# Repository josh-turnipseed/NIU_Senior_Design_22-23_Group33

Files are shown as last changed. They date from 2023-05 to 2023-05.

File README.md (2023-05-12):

# NIU Senior Design 2022-2023 Group 33
Analog and Digital Controlled Modular Synthesizer for Audio Synthesis and Signal Processing

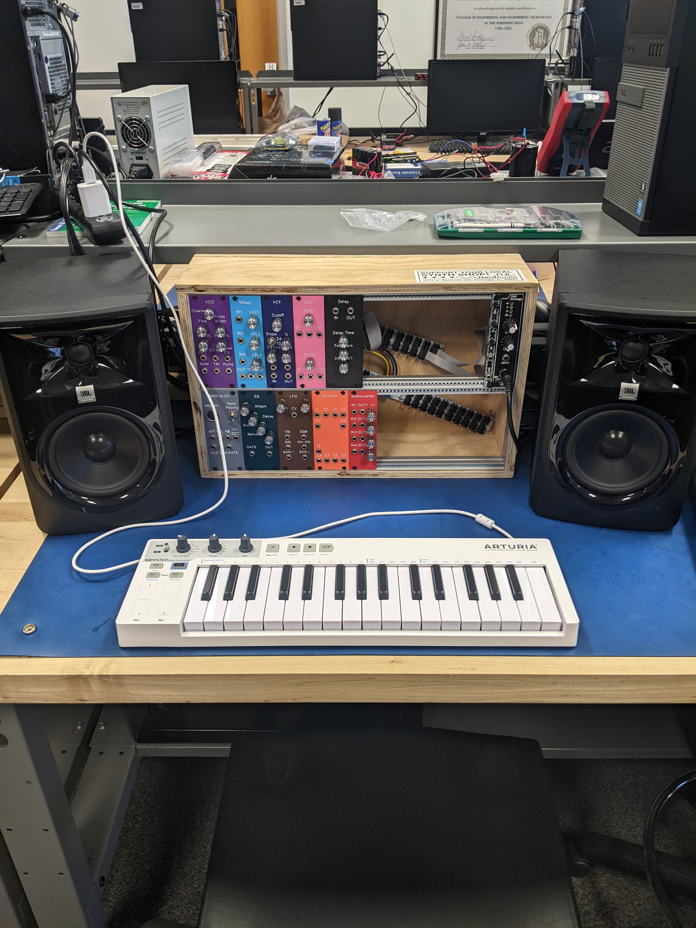
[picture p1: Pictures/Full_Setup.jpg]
Comleted Synthesizer


The goal of this project was to design and construct a modular Eurorack synthesizer.
The team has designed ten modules that perform the functions of a synthesizer. Those modules are:
- Musical Instrument Digital Interface (MIDI) to Control Voltage (CV)
- Voltage Controlled Oscillator (VCO)
- Voltage Controlled Amplifier (VCA)
- Voltage Controlled Filter (VCF)
- Envelope Generator (EG) ADSR Type
- Low Frequency Oscillator (LFO)
- Mixer
- Multiple
- Attenuverter
- Delay

# Schematics and PCBs
The schematic and board files for all ten modules can be found in the KiCad Schematics folder. In which, are folders for each of the modules. In addition to the KiCad project, schematic, and board files, there is a zip in each module folder which contains all the gerber files required to manufacture the PCBs. This group used JLCPCB, but any manufacture will do.

These files were made using KiCad version 7.0.1, release build

# Front Panels
This group chose to manufacture front panels using FDM 3D printing technologies. Step files can be found in the Steps folder for each of the modules. These files can be loaded into the slicer of your choice. Specifically, this group used Prusaslicer 2.6.0-alpha6 for the embossed text feature. Gcode can be found in the Gcode folder for each of the module front panels with text. The Gcode is for a Prusa i3 MK3S.

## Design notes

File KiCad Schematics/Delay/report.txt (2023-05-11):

Info: Processing symbol 'C2:Capacitor_THT:CP_Radial_D5.0mm_P2.00mm'.
Info: Processing symbol 'C3:Capacitor_THT:C_Disc_D3.8mm_W2.6mm_P2.50mm'.
Info: Processing symbol 'C4:Capacitor_THT:C_Disc_D3.8mm_W2.6mm_P2.50mm'.
Info: Processing symbol 'C5:Capacitor_THT:C_Disc_D3.8mm_W2.6mm_P2.50mm'.
Info: Processing symbol 'C6:Capacitor_THT:C_Disc_D3.8mm_W2.6mm_P2.50mm'.
Info: Processing symbol 'C7:Capacitor_THT:CP_Radial_D5.0mm_P2.00mm'.
Info: Processing symbol 'C8:Capacitor_THT:C_Disc_D3.8mm_W2.6mm_P2.50mm'.
Info: Processing symbol 'C9:Capacitor_THT:C_Disc_D3.8mm_W2.6mm_P2.50mm'.
Info: Processing symbol 'C10:Capacitor_THT:C_Disc_D3.8mm_W2.6mm_P2.50mm'.
Info: Processing symbol 'C11:Capacitor_THT:C_Disc_D3.8mm_W2.6mm_P2.50mm'.
Info: Processing symbol 'C12:Capacitor_THT:C_Disc_D3.8mm_W2.6mm_P2.50mm'.
Info: Processing symbol 'C13:Capacitor_THT:C_Disc_D3.8mm_W2.6mm_P2.50mm'.
Info: Processing symbol 'C14:Capacitor_THT:C_Disc_D3.8mm_W2.6mm_P2.50mm'.
Info: Processing symbol 'C15:Capacitor_THT:CP_Radial_D5.0mm_P2.00mm'.
Info: Processing symbol 'C16:Capacitor_THT:CP_Radial_D5.0mm_P2.00mm'.
Info: Processing symbol 'C17:Capacitor_THT:C_Disc_D3.8mm_W2.6mm_P2.50mm'.
Info: Processing symbol 'C18:Capacitor_THT:CP_Radial_D5.0mm_P2.00mm'.
Info: Processing symbol 'C19:Capacitor_THT:C_Disc_D3.8mm_W2.6mm_P2.50mm'.
Info: Processing symbol 'C20:Capacitor_THT:C_Disc_D3.8mm_W2.6mm_P2.50mm'.
Info: Processing symbol 'D2:Diode_THT:D_DO-41_SOD81_P10.16mm_Horizontal'.
Info: Processing symbol 'D3:Diode_THT:D_DO-41_SOD81_P10.16mm_Horizontal'.
Info: Processing symbol 'D4:Diode_THT:D_DO-41_SOD81_P10.16mm_Horizontal'.
Info: Processing symbol 'J1:Connector_Audio:Jack_3.5mm_QingPu_WQP-PJ398SM_Vertical_CircularHoles'.
Info: Processing symbol 'J2:Custom_Footprints:Eurorack_16_pin_header'.
Info: Processing symbol 'J3:Connector_Audio:Jack_3.5mm_QingPu_WQP-PJ398SM_Vertical_CircularHoles'.
Info: Processing symbol 'R1:Resistor_THT:R_Axial_DIN0207_L6.3mm_D2.5mm_P7.62mm_Horizontal'.
Info: Processing symbol 'R2:Resistor_THT:R_Axial_DIN0207_L6.3mm_D2.5mm_P7.62mm_Horizontal'.
Info: Processing symbol 'R3:Resistor_THT:R_Axial_DIN0207_L6.3mm_D2.5mm_P7.62mm_Horizontal'.
Info: Processing symbol 'R4:Resistor_THT:R_Axial_DIN0207_L6.3mm_D2.5mm_P7.62mm_Horizontal'.
Info: Processing symbol 'R5:Resistor_THT:R_Axial_DIN0207_L6.3mm_D2.5mm_P7.62mm_Horizontal'.
Info: Processing symbol 'R6:Resistor_THT:R_Axial_DIN0207_L6.3mm_D2.5mm_P7.62mm_Horizontal'.
Info: Processing symbol 'R7:Resistor_THT:R_Axial_DIN0207_L6.3mm_D2.5mm_P7.62mm_Horizontal'.
Info: Processing symbol 'R8:Resistor_THT:R_Axial_DIN0207_L6.3mm_D2.5mm_P7.62mm_Horizontal'.
Info: Processing symbol 'R9:Resistor_THT:R_Axial_DIN0207_L6.3mm_D2.5mm_P7.62mm_Horizontal'.
Info: Processing symbol 'R10:Resistor_THT:R_Axial_DIN0207_L6.3mm_D2.5mm_P7.62mm_Horizontal'.
Info: Processing symbol 'R11:Resistor_THT:R_Axial_DIN0207_L6.3mm_D2.5mm_P7.62mm_Horizontal'.
Info: Processing symbol 'R12:Resistor_THT:R_Axial_DIN0207_L6.3mm_D2.5mm_P7.62mm_Horizontal'.
Info: Processing symbol 'R13:Resistor_THT:R_Axial_DIN0207_L6.3mm_D2.5mm_P7.62mm_Horizontal'.
Info: Processing symbol 'R14:Resistor_THT:R_Axial_DIN0207_L6.3mm_D2.5mm_P7.62mm_Horizontal'.
Info: Processing symbol 'R15:Resistor_THT:R_Axial_DIN0207_L6.3mm_D2.5mm_P7.62mm_Horizontal'.
Info: Processing symbol 'R16:Resistor_THT:R_Axial_DIN0207_L6.3mm_D2.5mm_P7.62mm_Horizontal'.
Info: Processing symbol 'R17:Resistor_THT:R_Axial_DIN0207_L6.3mm_D2.5mm_P7.62mm_Horizontal'.
Info: Processing symbol 'R18:Resistor_THT:R_Axial_DIN0207_L6.3mm_D2.5mm_P7.62mm_Horizontal'.
Info: Processing symbol 'R19:Resistor_THT:R_Axial_DIN0207_L6.3mm_D2.5mm_P7.62mm_Horizontal'.
Info: Processing symbol 'R20:Resistor_THT:R_Axial_DIN0207_L6.3mm_D2.5mm_P7.62mm_Horizontal'.
Info: Processing symbol 'R21:Resistor_THT:R_Axial_DIN0207_L6.3mm_D2.5mm_P7.62mm_Horizontal'.
Info: Processing symbol 'RV1:Custom_Footprints:Alpha_9mm_Potentiometer'.
Info: Processing symbol 'RV2:Custom_Footprints:Alpha_9mm_Potentiometer'.
Info: Processing symbol 'RV3:Custom_Footprints:Alpha_9mm_Potentiometer'.
Info: Processing symbol 'U1:Package_DIP:DIP-8_W7.62mm'.
Info: Processing symbol 'U2:Package_DIP:DIP-16_W7.62mm'.

Info: Total warnings: 0, errors: 0.

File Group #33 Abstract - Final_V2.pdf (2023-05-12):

## Analog and Digital Controlled Modular Synthesizer for

## Audio Synthesis and Signal Processing

Team 33
Joshua Turnipseed, Michael Nelson, Tobi Adeyemi, Peter Dufka College of Engineering and Engineering Technology Northern Illinois University, Dekalb, IL, USA josh.turnipseed@proton.me, z1808464@students.niu.edu, z1869980@students.niu.edu, z1913659@students.niu.edu Faculty Sponsor: Dr. Fonseca (Electrical Engineering) bfonseca@niu.edu

Abstract— A synthesizer is an electronic musical instrument that generates and manipulates waveforms via electronic circuits, software algorithms, or other techniques to create various sounds, from traditional instruments to experimental sound effects. A modular, analog synthesizer comprises of several modules connected with patch cables. Eurorack is a popular modular synthesizer format due to its versatility, flexibility, and scalability. The goal of this project was to create Eurorack-compliant modules for an analog synthesizer. To reach this goal, the team had to apply knowledge related to electronic circuitry, signal processing, and user interface design, as well as consider technical specifications and compatibility requirements. The result was a musical instrument for live performances, studio recordings, or experimental sound art projects.

Keywords: Synthesizer, Modular, Analog, Eurorack.

I. INTRODUCTION
The goal of this project was to design and construct a modular Eurorack synthesizer. A modular Eurorack synthesizer is a customizable device that generates and manipulates sound using individual modules connected together. Eurorack is a popular synthesizer format due to its standardized size and power supply system, allowing modules from different manufacturers to be combined. Modules can be classified as audio sources, audio modifiers, Control Voltage (CV) sources, or CV modifiers, each with inputs and outputs to connect to other modules. The signal path consists of two different signals: audio and control. The audio signals are the sounds that can be heard while the control signals are not heard directly but affect the audio signals in some noticeable way. These signals are routed between each module’s inputs and outputs by patch cables. External control can be achieved by CVs from other devices or from a Musical Instrument Digital Interface (MIDI) keyboard or controller. MIDI is a protocol for sending musical information digitally. For this information to be used in our device, MIDI messages must be converted to an analog CV. In short, the synthesizer accepts MIDI messages which are converted to CVs. It generates a waveform based on these CVs which is then processed by subsequent modules. Its output can be used for real-time sound generation or recordings for later playback. A high-level flowchart of this is demonstrated in Figure 1. This method of synthesis is known as subtractive synthesis. Under this method, a harmonically rich waveform is generated and then filtered to produce the desired sound.

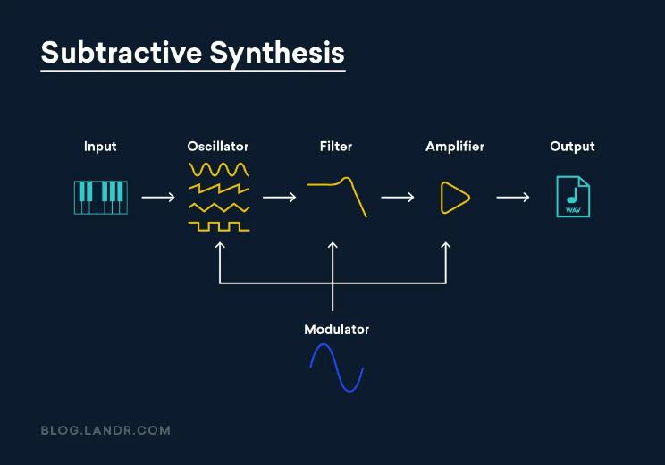
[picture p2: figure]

Figure 1. Subtractive Synthesis Basics [1]

II. PROJECT DESCRIPTION AND SCOPE There are many considerations that come with synthesizer design. Because of this, the team decided to adopt the Eurorack synthesizer format. In this way, some design decisions would be constrained to adhere to the specifications of the Eurorack format. Eurorack was selected due to its flexibility, expandability, and popularity. Modules can be designed in parallel; mounted and powered by Eurorack cases; and interface with other 3rd party modules.
The Eurorack format lays out two distinct specifications: mechanical and electrical. The mechanical specification defines the physical dimensions of the modules and how they mount in a case. The electrical specification defines the voltage levels for power and signals. Eurorack power supplies provide ±12V. +5V is also provided for any digital components. Audio signals range from ±5V, while control signals range from ±2.5V for bipolar CV sources and 0V to +8V for unipolar CV sources. These are typically values for CVs; modules must withstand input voltages within the ±12V range. 3.5mm patch cables connect audio and CV signals between modules. Module parameters can be adjusted on the module’s front panel or by CVs. Figure 2 shows how CVs are used to adjust module parameters.

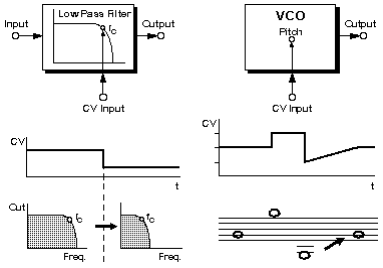
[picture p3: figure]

Figure 2. The Principles of Voltage Control [2]

III. MODULES
The team has designed ten modules that perform the functions of a synthesizer. Those modules are as follows:
1. MIDI to CV
A MIDI to CV module translates MIDI signals from a digital message into analog CVs.
2. Voltage Controlled Oscillator (VCO)
A VCO module produces a waveform with a variable-frequency based on a CV.
3. Voltage Controlled Amplifier (VCA)
A VCA module controls the amplitude or volume of an audio signal based on a CV.
4. Voltage Controlled Filter (VCF)
A VCF module filters the frequency content of an audio signal with the cutoff frequency of the passband being controlled by a voltage.
5. Envelope Generator (EG)
An EG module produces a time-varying CV used to shape the amplitude, timbre, or other module parameters.
6. Low Frequency Oscillator (LFO)
An LFO module generates a periodic waveform used to modulate the pitch, amplitude, filter cutoff frequency, or other module parameters.
7. Mixer
A Mixer module is used to adjust the volume levels of multiple audio signals and sum them into one output signal.
8. Multiple
A Multiple module duplicates and distributes incoming signals to multiple output channels.
9. Attenuverter
An Attenuverter module can attenuate and/or invert incoming signals with adjustable levels of control.
10. Delay
A Delay module creates an echo or repeating effect by delaying and repeating an input signal with adjustable parameters such as delay time and feedback.
These modules can be connected in a variety of ways by a user to create different signal paths. These differing paths allow for unique and complex sounds to be generated and processed. Since these combinations of modules are created by patch cables, a user can easily change the signal path whenever they wish, even in mid performance. Figure 3 shows one example of how all ten designed modules can be connected together as a system.

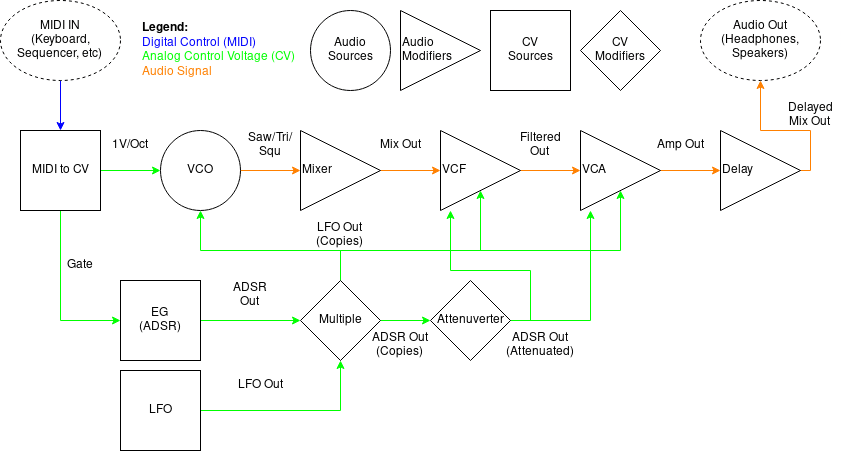
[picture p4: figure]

Figure 3. Example of System Block Diagram

| IV. | RESULTS
Each module designed performs its functions as expected. The modules adhere to the Eurorack format and can interface together to form a larger synthesizer system. This synthesizer can be played and controlled by a user.

ACKNOWLEDGMENT
Team 33 would like to thank and acknowledge the following people for both their direct and indirect involvement in this project. Dr. Fonseca, for accepting to be our faculty advisor and guiding us through this project. Ellaine Ray, for being our TA and providing feedback on our assignments. Dr. Peterson and NIU, for their support in allowing us to complete this design. Antonio Palacios, for helping us construct our case. Moritz Klein, Aaron Lanterman, Bernie Hutchins, Stevey Yarusinsky, and Ray Wilson for all providing invaluable online resources that were used extensively. And finally, to all who will play this synthesizer. Thank you.

REFERENCES

[1] Hahn, M. (2022, November 8). Subtractive Synthesis: Learn
Synthesizer | Sound | Design. | LANDR | Blog.
https://blog.landr.com/subtractive-synthesis/
[2] Technical | Details | | A-100. | (n.d.).
https://doepfer.de/a100_man/a100t_e.htm

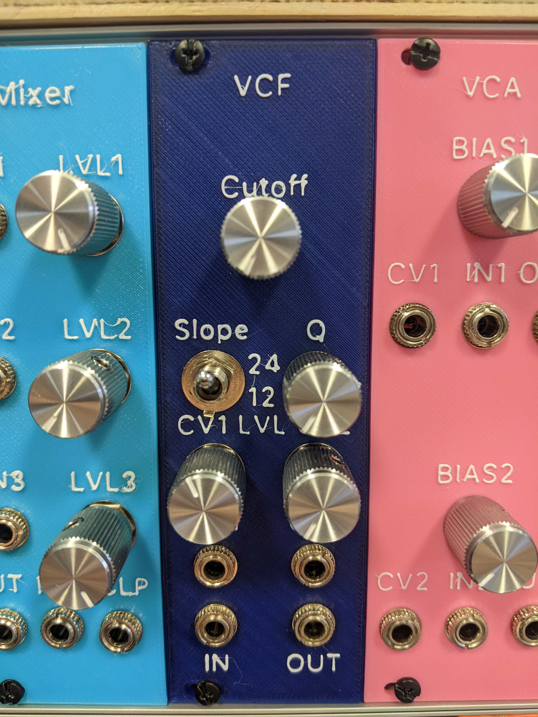
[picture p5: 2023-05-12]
Pictures/VCF.jpg

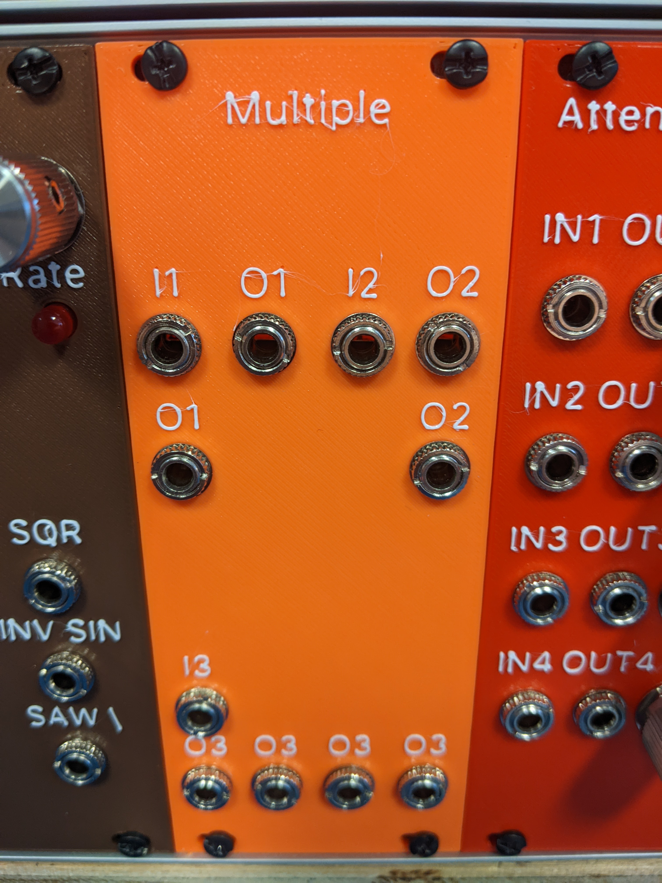
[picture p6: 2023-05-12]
Pictures/Multiple.jpg

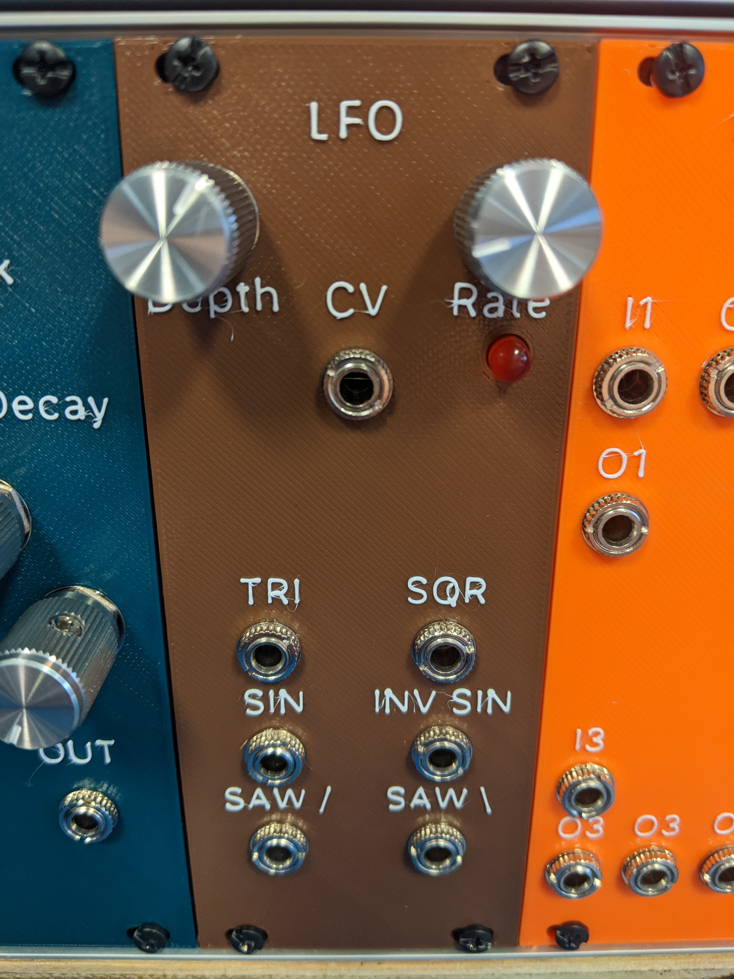
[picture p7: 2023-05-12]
Pictures/LFO.jpg

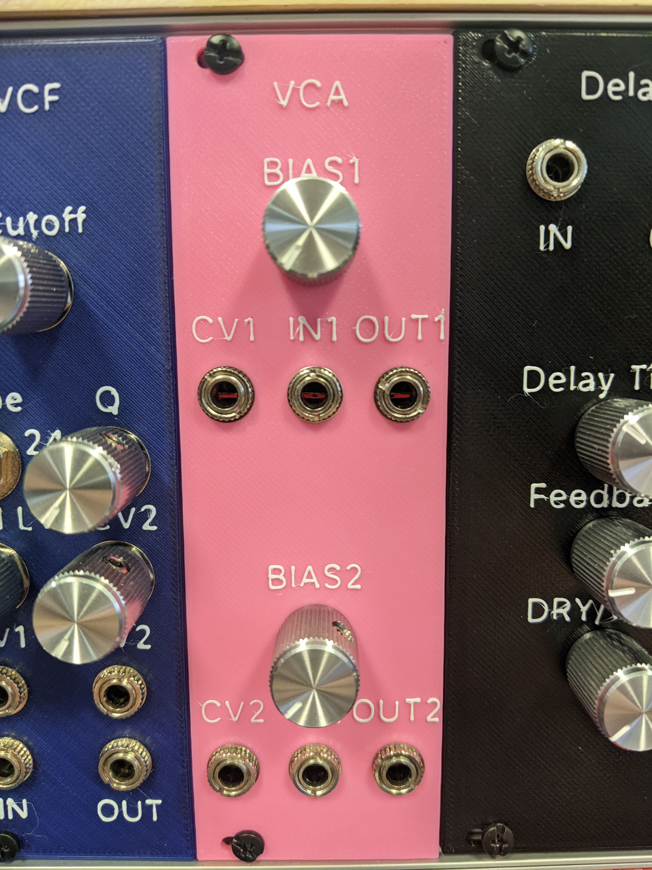
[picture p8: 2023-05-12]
Pictures/VCA.jpg

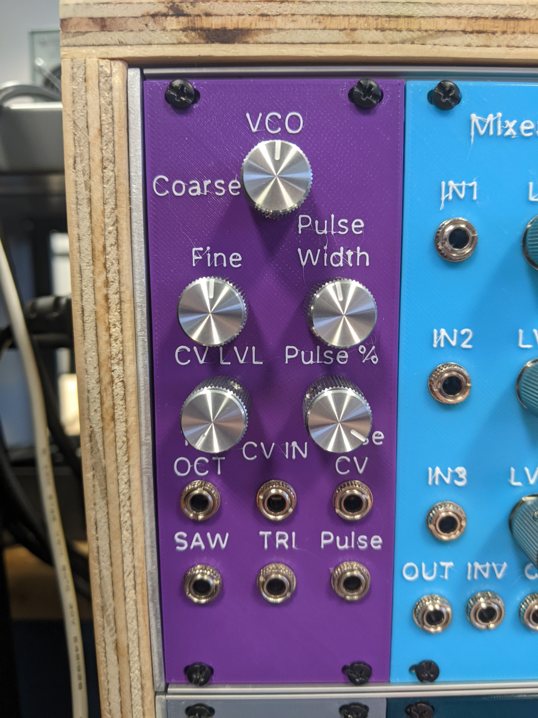
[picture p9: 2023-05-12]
Pictures/VCO.jpg

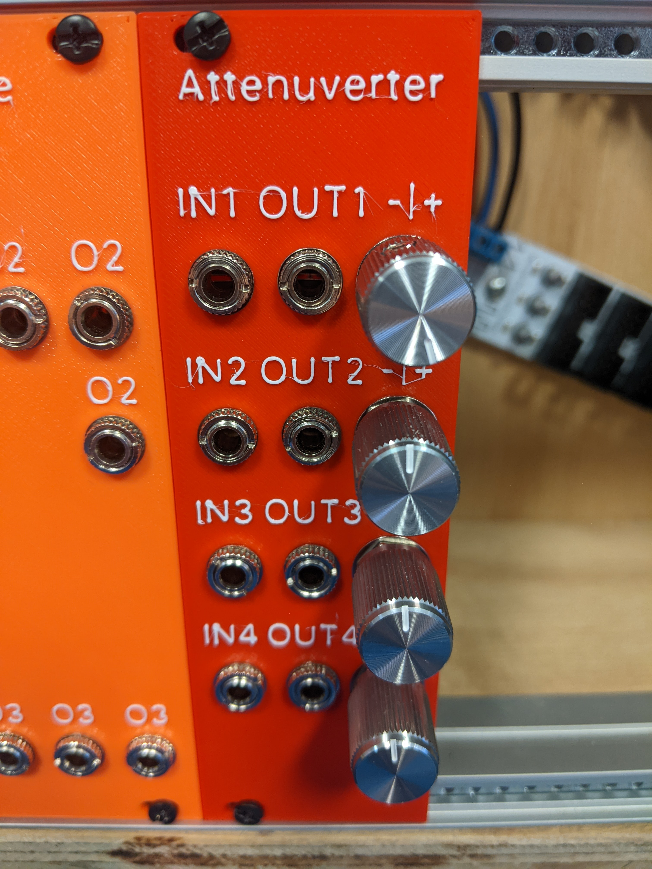
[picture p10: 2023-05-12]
Pictures/Attenuverter.jpg

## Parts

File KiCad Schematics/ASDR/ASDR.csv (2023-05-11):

Source: | /home/josh/Documents/Kicad Projects/Senior Design/ASDR Mike PCB/ASDR.kicad_sch
Date: | Sat 22 Apr 2023 10:32:47 AM CDT
Tool: | Eeschema 7.0.1
Generator: | /usr/share/kicad/plugins/bom_csv_grouped_by_value_with_fp.py
Component Count: | 51
Ref | Qnty | Value | Cmp name | Footprint | Description | Vendor | DNP
Attack1 | 1 | 1M | R_Potentiometer_US | Custom_Footprints:Alpha_9mm_Potentiometer | Potentiometer, US symbol
C1, C2, C3, C4, C6, C7, C10, C12 | 8 | 0.1u | C | Capacitor_THT:C_Disc_D4.7mm_W2.5mm_P5.00mm | Unpolarized capacitor
C5 | 1 | 3.3u | C | Capacitor_THT:C_Disc_D4.7mm_W2.5mm_P5.00mm | Unpolarized capacitor
C8, C9, C11 | 3 | 47u | C_Polarized_US | Capacitor_THT:CP_Radial_D4.0mm_P2.00mm | Polarized capacitor, US symbol
D1, D2, D3, D4, D5 | 5 | 1N4148 | D | Diode_THT:D_DO-41_SOD81_P3.81mm_Vertical_KathodeUp | Diode
D6, D7, D8 | 3 | 1N5819 | 1N5819 | Diode_THT:D_DO-41_SOD81_P3.81mm_Vertical_KathodeUp | 40V 1A Schottky Barrier Rectifier Diode, DO-41
Decay1 | 1 | 500k | R_Potentiometer_US | Custom_Footprints:Alpha_9mm_Potentiometer | Potentiometer, US symbol
J1 | 1 | Eurorack 16 DIP Header | Conn_02x08_Odd_Even | Custom_Footprints:Eurorack_16_pin_header | Generic connector, double row, 02x08, odd/even pin numbering scheme (row 1 odd numbers, row 2 even numbers), script generated (kicad-library-utils/schlib/autogen/connector/)
J2 | 1 | GATE | AudioJack2_SwitchT | Connector_Audio:Jack_3.5mm_QingPu_WQP-PJ398SM_Vertical_CircularHoles | Audio Jack, 2 Poles (Mono / TS), Switched T Pole (Normalling)
J3 | 1 | OUT | AudioJack2_SwitchT | Connector_Audio:Jack_3.5mm_QingPu_WQP-PJ398SM_Vertical_CircularHoles | Audio Jack, 2 Poles (Mono / TS), Switched T Pole (Normalling)
Q1, Q2, Q3 | 3 | 2N3904 | 2N3904 | Package_TO_SOT_THT:TO-92L_Inline_Wide | TRANS NPN 40V TO-92
R1, R3, R5, R8 | 4 | 5.6k | R_US | Resistor_THT:R_Axial_DIN0207_L6.3mm_D2.5mm_P2.54mm_Vertical | Resistor, US symbol
R2, R4, R6, R13 | 4 | 10k | R_US | Resistor_THT:R_Axial_DIN0207_L6.3mm_D2.5mm_P2.54mm_Vertical | Resistor, US symbol
R7, R19 | 2 | 1k | R_US | Resistor_THT:R_Axial_DIN0207_L6.3mm_D2.5mm_P2.54mm_Vertical | Resistor, US symbol
R9, R10, R11 | 3 | 180 | R_US | Resistor_THT:R_Axial_DIN0207_L6.3mm_D2.5mm_P2.54mm_Vertical | Resistor, US symbol
R12 | 1 | 7k | R_US | Resistor_THT:R_Axial_DIN0207_L6.3mm_D2.5mm_P2.54mm_Vertical | Resistor, US symbol
R14 | 1 | 150k | R_US | Resistor_THT:R_Axial_DIN0207_L6.3mm_D2.5mm_P2.54mm_Vertical | Resistor, US symbol
R15 | 1 | 5k | R_US | Resistor_THT:R_Axial_DIN0207_L6.3mm_D2.5mm_P2.54mm_Vertical | Resistor, US symbol
R16, R17, R18 | 3 | 10 | R_US | Resistor_THT:R_Axial_DIN0207_L6.3mm_D2.5mm_P2.54mm_Vertical | Resistor, US symbol
Release1 | 1 | 500k | R_Potentiometer_US | Custom_Footprints:Alpha_9mm_Potentiometer | Potentiometer, US symbol
Sustain1 | 1 | 500k | R_Potentiometer_US | Custom_Footprints:Alpha_9mm_Potentiometer | Potentiometer, US symbol
U1 | 1 | NE555P | NE555P | Package_DIP:DIP-8_W7.62mm | IC OSC SINGLE TIMER 100KHZ 8-DIP
U2 | 1 | LM324 | LM324 | Package_DIP:DIP-14_W7.62mm | Low-Power, Quad-Operational Amplifiers, DIP-14/SOIC-14/SSOP-14

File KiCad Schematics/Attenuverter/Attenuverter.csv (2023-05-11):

Source: | /home/josh/Documents/Kicad Projects/Senior Design/Attenuverter/Attenuverter.kicad_sch
Date: | Sat 22 Apr 2023 10:55:21 AM CDT
Tool: | Eeschema 7.0.1
Generator: | /usr/share/kicad/plugins/bom_csv_grouped_by_value_with_fp.py
Component Count: | 36
Ref | Qnty | Value | Cmp name | Footprint | Description | Vendor | DNP
C1, C2, C5, C6 | 4 | 0.1u | C_Small | Capacitor_THT:C_Disc_D4.7mm_W2.5mm_P5.00mm | Unpolarized capacitor, small symbol
C3, C4 | 2 | 47u | C_Polarized_US | Capacitor_THT:CP_Radial_D4.0mm_P2.00mm | Polarized capacitor, US symbol
D1, D2 | 2 | 1N5819 | 1N5819 | Diode_THT:D_DO-41_SOD81_P3.81mm_Vertical_KathodeUp | 40V 1A Schottky Barrier Rectifier Diode, DO-41
J1 | 1 | IN1 | AudioJack2_SwitchT | Connector_Audio:Jack_3.5mm_QingPu_WQP-PJ398SM_Vertical_CircularHoles | Audio Jack, 2 Poles (Mono / TS), Switched T Pole (Normalling)
J2 | 1 | OUT1 | AudioJack2_SwitchT | Connector_Audio:Jack_3.5mm_QingPu_WQP-PJ398SM_Vertical_CircularHoles | Audio Jack, 2 Poles (Mono / TS), Switched T Pole (Normalling)
J3 | 1 | IN2 | AudioJack2_SwitchT | Connector_Audio:Jack_3.5mm_QingPu_WQP-PJ398SM_Vertical_CircularHoles | Audio Jack, 2 Poles (Mono / TS), Switched T Pole (Normalling)
J4 | 1 | OUT2 | AudioJack2_SwitchT | Connector_Audio:Jack_3.5mm_QingPu_WQP-PJ398SM_Vertical_CircularHoles | Audio Jack, 2 Poles (Mono / TS), Switched T Pole (Normalling)
J5 | 1 | IN3 | AudioJack2_SwitchT | Connector_Audio:Jack_3.5mm_QingPu_WQP-PJ398SM_Vertical_CircularHoles | Audio Jack, 2 Poles (Mono / TS), Switched T Pole (Normalling)
J6 | 1 | OUT3 | AudioJack2_SwitchT | Connector_Audio:Jack_3.5mm_QingPu_WQP-PJ398SM_Vertical_CircularHoles | Audio Jack, 2 Poles (Mono / TS), Switched T Pole (Normalling)
J7 | 1 | IN4 | AudioJack2_SwitchT | Connector_Audio:Jack_3.5mm_QingPu_WQP-PJ398SM_Vertical_CircularHoles | Audio Jack, 2 Poles (Mono / TS), Switched T Pole (Normalling)
J8 | 1 | OUT4 | AudioJack2_SwitchT | Connector_Audio:Jack_3.5mm_QingPu_WQP-PJ398SM_Vertical_CircularHoles | Audio Jack, 2 Poles (Mono / TS), Switched T Pole (Normalling)
J9 | 1 | Eurorack 10 DIP Header | Conn_02x05_Odd_Even | Custom_Footprints:Eurorack_10_pin_header | Generic connector, double row, 02x05, odd/even pin numbering scheme (row 1 odd numbers, row 2 even numbers), script generated (kicad-library-utils/schlib/autogen/connector/)
R1, R2 | 2 | 10 | R_US | Resistor_THT:R_Axial_DIN0207_L6.3mm_D2.5mm_P2.54mm_Vertical | Resistor, US symbol
R3, R4, R5, R6, R9, R10, R11, R12 | 8 | 20k | R_US | Resistor_THT:R_Axial_DIN0207_L6.3mm_D2.5mm_P2.54mm_Vertical | Resistor, US symbol
R7, R8, R13, R14 | 4 | 1k | R_US | Resistor_THT:R_Axial_DIN0207_L6.3mm_D2.5mm_P2.54mm_Vertical | Resistor, US symbol
RV1, RV2, RV3, RV4 | 4 | 10k | R_Potentiometer_US | Custom_Footprints:Alpha_9mm_Potentiometer_Aligned | Potentiometer, US symbol
U1 | 1 | TL074 | TL074 | Package_DIP:DIP-14_W7.62mm | Quad Low-Noise JFET-Input Operational Amplifiers, DIP-14/SOIC-14

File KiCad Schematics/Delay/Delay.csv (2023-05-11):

Source: | /home/josh/Documents/Kicad Projects/Senior Design/Delay/Delay.kicad_sch
Date: | Sat 22 Apr 2023 10:56:42 AM CDT
Tool: | Eeschema 7.0.1
Generator: | /usr/share/kicad/plugins/bom_csv_grouped_by_value_with_fp.py
Component Count: | 51
Ref | Qnty | Value | Cmp name | Footprint | Description | Vendor | DNP
C2 | 1 | 47uF | C_Polarized_US | Capacitor_THT:CP_Radial_D5.0mm_P2.00mm | Polarized capacitor, US symbol
C3 | 1 | .22uF | C | Capacitor_THT:C_Disc_D3.8mm_W2.6mm_P2.50mm | Unpolarized capacitor
C4, C5, C8, C11 | 4 | .1uF | C | Capacitor_THT:C_Disc_D3.8mm_W2.6mm_P2.50mm | Unpolarized capacitor
C6 | 1 | 47pF | C | Capacitor_THT:C_Disc_D3.8mm_W2.6mm_P2.50mm | Unpolarized capacitor
C7, C15, C16, C18 | 4 | 1uF | C_Polarized_US | Capacitor_THT:CP_Radial_D5.0mm_P2.00mm | Polarized capacitor, US symbol
C9, C10 | 2 | 2200pF | C | Capacitor_THT:C_Disc_D3.8mm_W2.6mm_P2.50mm | Unpolarized capacitor
C12 | 1 | 100pF | C | Capacitor_THT:C_Disc_D3.8mm_W2.6mm_P2.50mm | Unpolarized capacitor
C13 | 1 | .015uF | C | Capacitor_THT:C_Disc_D3.8mm_W2.6mm_P2.50mm | Unpolarized capacitor
C14 | 1 | 4700pF | C | Capacitor_THT:C_Disc_D3.8mm_W2.6mm_P2.50mm | Unpolarized capacitor
C17 | 1 | .01uF | C | Capacitor_THT:C_Disc_D3.8mm_W2.6mm_P2.50mm | Unpolarized capacitor
C19 | 1 | .047uF | C | Capacitor_THT:C_Disc_D3.8mm_W2.6mm_P2.50mm | Unpolarized capacitor
C20 | 1 | .022uF | C | Capacitor_THT:C_Disc_D3.8mm_W2.6mm_P2.50mm | Unpolarized capacitor
D2, D3, D4 | 3 | 1N5819 | 1N5819 | Diode_THT:D_DO-41_SOD81_P10.16mm_Horizontal | 40V 1A Schottky Barrier Rectifier Diode, DO-41
J1, J3 | 2 | IN | AudioJack2_SwitchT | Connector_Audio:Jack_3.5mm_QingPu_WQP-PJ398SM_Vertical_CircularHoles | Audio Jack, 2 Poles (Mono / TS), Switched T Pole (Normalling)
J2 | 1 | Eurorack 16 DIP Header | Conn_02x08_Odd_Even | Custom_Footprints:Eurorack_16_pin_header | Generic connector, double row, 02x08, odd/even pin numbering scheme (row 1 odd numbers, row 2 even numbers), script generated (kicad-library-utils/schlib/autogen/connector/)
R1, R18 | 2 | 2K | R | Resistor_THT:R_Axial_DIN0207_L6.3mm_D2.5mm_P7.62mm_Horizontal | Resistor
R2 | 1 | 1M | R | Resistor_THT:R_Axial_DIN0207_L6.3mm_D2.5mm_P7.62mm_Horizontal | Resistor
R3 | 1 | 180K | R | Resistor_THT:R_Axial_DIN0207_L6.3mm_D2.5mm_P7.62mm_Horizontal | Resistor
R4 | 1 | 360K | R | Resistor_THT:R_Axial_DIN0207_L6.3mm_D2.5mm_P7.62mm_Horizontal | Resistor
R5, R7, R8, R9, R10 | 5 | 10K | R | Resistor_THT:R_Axial_DIN0207_L6.3mm_D2.5mm_P7.62mm_Horizontal | Resistor
R6 | 1 | 22K | R | Resistor_THT:R_Axial_DIN0207_L6.3mm_D2.5mm_P7.62mm_Horizontal | Resistor
R11 | 1 | 12K | R | Resistor_THT:R_Axial_DIN0207_L6.3mm_D2.5mm_P7.62mm_Horizontal | Resistor
R12, R13 | 2 | 20K | R | Resistor_THT:R_Axial_DIN0207_L6.3mm_D2.5mm_P7.62mm_Horizontal | Resistor
R14, R15 | 2 | 1K | R | Resistor_THT:R_Axial_DIN0207_L6.3mm_D2.5mm_P7.62mm_Horizontal | Resistor
R16 | 1 | 100K | R | Resistor_THT:R_Axial_DIN0207_L6.3mm_D2.5mm_P7.62mm_Horizontal | Resistor
R17 | 1 | 5.1K | R | Resistor_THT:R_Axial_DIN0207_L6.3mm_D2.5mm_P7.62mm_Horizontal | Resistor
R19, R20, R21 | 3 | 10 | R_US | Resistor_THT:R_Axial_DIN0207_L6.3mm_D2.5mm_P7.62mm_Horizontal | Resistor, US symbol
RV1, RV2, RV3 | 3 | R_Potentiometer | R_Potentiometer | Custom_Footprints:Alpha_9mm_Potentiometer | Potentiometer
U1 | 1 | TL072 | TL072 | Package_DIP:DIP-8_W7.62mm | Dual Low-Noise JFET-Input Operational Amplifiers, DIP-8/SOIC-8
U2 | 1 | PT2399 | PT2399 | Package_DIP:DIP-16_W7.62mm | Echo Processor IC

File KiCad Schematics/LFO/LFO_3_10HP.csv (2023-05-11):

Source: | /home/josh/Documents/Kicad Projects/Senior Design/LFO_3/LFO_3_10HP.kicad_sch
Date: | Sat 22 Apr 2023 10:38:05 AM CDT
Tool: | Eeschema 7.0.1
Generator: | /usr/share/kicad/plugins/bom_csv_grouped_by_value_with_fp.py
Component Count: | 84
Ref | Qnty | Value | Cmp name | Footprint | Description | Vendor | DNP
C1, C2, C5, C6, C7, C8, C9, C10, C11 | 9 | 0.1u | C | Capacitor_THT:C_Disc_D4.7mm_W2.5mm_P5.00mm | Unpolarized capacitor
C3, C4 | 2 | 47u | C_Polarized_US | Capacitor_THT:CP_Radial_D4.0mm_P2.00mm | Polarized capacitor, US symbol
D1, D2 | 2 | 1N5819 | 1N5819 | Diode_THT:D_DO-41_SOD81_P10.16mm_Horizontal | 40V 1A Schottky Barrier Rectifier Diode, DO-41
D3 | 1 | LED | LED | LED_THT:LED_D5.0mm | Light emitting diode
J1 | 1 | CV IN | AudioJack2_SwitchT | Connector_Audio:Jack_3.5mm_QingPu_WQP-PJ398SM_Vertical_CircularHoles | Audio Jack, 2 Poles (Mono / TS), Switched T Pole (Normalling)
J2 | 1 | Eurorack 10 DIP Header | Conn_02x05_Odd_Even | Custom_Footprints:Eurorack_10_pin_header | Generic connector, double row, 02x05, odd/even pin numbering scheme (row 1 odd numbers, row 2 even numbers), script generated (kicad-library-utils/schlib/autogen/connector/)
J3 | 1 | TRI | AudioJack2_SwitchT | Connector_Audio:Jack_3.5mm_QingPu_WQP-PJ398SM_Vertical_CircularHoles | Audio Jack, 2 Poles (Mono / TS), Switched T Pole (Normalling)
J4 | 1 | SQR | AudioJack2_SwitchT | Connector_Audio:Jack_3.5mm_QingPu_WQP-PJ398SM_Vertical_CircularHoles | Audio Jack, 2 Poles (Mono / TS), Switched T Pole (Normalling)
J5 | 1 | SINE | AudioJack2_SwitchT | Connector_Audio:Jack_3.5mm_QingPu_WQP-PJ398SM_Vertical_CircularHoles | Audio Jack, 2 Poles (Mono / TS), Switched T Pole (Normalling)
J6 | 1 | COSINE | AudioJack2_SwitchT | Connector_Audio:Jack_3.5mm_QingPu_WQP-PJ398SM_Vertical_CircularHoles | Audio Jack, 2 Poles (Mono / TS), Switched T Pole (Normalling)
J7 | 1 | RAMP UP | AudioJack2_SwitchT | Connector_Audio:Jack_3.5mm_QingPu_WQP-PJ398SM_Vertical_CircularHoles | Audio Jack, 2 Poles (Mono / TS), Switched T Pole (Normalling)
J8 | 1 | RAMP DOWN | AudioJack2_SwitchT | Connector_Audio:Jack_3.5mm_QingPu_WQP-PJ398SM_Vertical_CircularHoles | Audio Jack, 2 Poles (Mono / TS), Switched T Pole (Normalling)
J9, J10, J11, J12 | 4 | Conn_01x04 | Conn_01x04 | Connector_PinHeader_2.54mm:PinHeader_1x04_P2.54mm_Vertical | Generic connector, single row, 01x04, script generated (kicad-library-utils/schlib/autogen/connector/)
J13, J14 | 2 | Conn_01x02 | Conn_01x02 | Connector_PinHeader_2.54mm:PinHeader_1x02_P2.54mm_Vertical | Generic connector, single row, 01x02, script generated (kicad-library-utils/schlib/autogen/connector/)
Q1, Q2, Q3, Q4, Q5 | 5 | BC550 | BC550 | Package_TO_SOT_THT:TO-92_Inline_Wide | 0.1A Ic, 45V Vce, Small Signal NPN Transistor, TO-92
R1, R2, R5, R6, R7, R8, R18, R22, R23, R25, R26, R30 | 12 | 100k | R_US | Resistor_THT:R_Axial_DIN0207_L6.3mm_D2.5mm_P7.62mm_Horizontal | Resistor, US symbol
R3, R4 | 2 | 10 | R_US | Resistor_THT:R_Axial_DIN0207_L6.3mm_D2.5mm_P7.62mm_Horizontal | Resistor, US symbol
R9, R10, R11, R14, R17 | 5 | 47k | R_US | Resistor_THT:R_Axial_DIN0207_L6.3mm_D2.5mm_P7.62mm_Horizontal | Resistor, US symbol
R12, R15, R16, R21, R33, R35, R36, R37, R38, R39 | 10 | 10k | R_US | Resistor_THT:R_Axial_DIN0207_L6.3mm_D2.5mm_P7.62mm_Horizontal | Resistor, US symbol
R13, R24 | 2 | 470 | R_US | Resistor_THT:R_Axial_DIN0207_L6.3mm_D2.5mm_P7.62mm_Horizontal | Resistor, US symbol
R19 | 1 | 220 | R_US | Resistor_THT:R_Axial_DIN0207_L6.3mm_D2.5mm_P7.62mm_Horizontal | Resistor, US symbol
R20 | 1 | 68k | R_US | Resistor_THT:R_Axial_DIN0207_L6.3mm_D2.5mm_P7.62mm_Horizontal | Resistor, US symbol
R27, R29 | 2 | 33k | R_US | Resistor_THT:R_Axial_DIN0207_L6.3mm_D2.5mm_P7.62mm_Horizontal | Resistor, US symbol
R28, R34, R40, R41, R42 | 5 | 1k | R_US | Resistor_THT:R_Axial_DIN0207_L6.3mm_D2.5mm_P7.62mm_Horizontal | Resistor, US symbol
R31 | 1 | 50k | R_US | Resistor_THT:R_Axial_DIN0207_L6.3mm_D2.5mm_P7.62mm_Horizontal | Resistor, US symbol
R32 | 1 | 20k | R_US | Resistor_THT:R_Axial_DIN0207_L6.3mm_D2.5mm_P7.62mm_Horizontal | Resistor, US symbol
R43 | 1 | 560 | R_US | Resistor_THT:R_Axial_DIN0207_L6.3mm_D2.5mm_P7.62mm_Horizontal | Resistor, US symbol
RV1, RV2 | 2 | 100K | R_Potentiometer_US | Custom_Footprints:Alpha_9mm_Potentiometer_Aligned | Potentiometer, US symbol
RV3 | 1 | 100k | R_Potentiometer_Trim_US | Custom_Footprints:3296Y-1-502LF | Trim-potentiometer, US symbol
RV4 | 1 | 50k | R_Potentiometer_Trim_US | Custom_Footprints:3296Y-1-502LF | Trim-potentiometer, US symbol
RV5 | 1 | 20k | R_Potentiometer_Trim_US | Custom_Footprints:3296Y-1-502LF | Trim-potentiometer, US symbol
U1, U2 | 2 | TL074CN | LM324 | TL074CN:DIP794W45P254L1969H508Q14 | Low-Power, Quad-Operational Amplifiers, DIP-14/SOIC-14/SSOP-14
U3 | 1 | TL072CP | LM358 | TL072CPE4:DIP794W45P254L959H508Q8 | Low-Power, Dual Operational Amplifiers, DIP-8/SOIC-8/TO-99-8

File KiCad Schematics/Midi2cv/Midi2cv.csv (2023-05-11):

Source: | /home/josh/Documents/Kicad Projects/Senior Design/Midi2cv/Midi2cv.kicad_sch
Date: | Mon 27 Feb 2023 08:28:13 PM CST
Tool: | Eeschema (6.0.11)
Generator: | /usr/share/kicad/plugins/bom_csv_grouped_by_value.py
Component Count: | 35
Individual Components:
Item | Qty | Reference(s) | Value | LibPart | Footprint | Datasheet
 |  | A1 | ELEGOO_Nano_V3.0 | MCU_Module:Arduino_Nano_v2.x | Module:Arduino_Nano | https://www.arduino.cc/en/uploads/Main/ArduinoNanoManual23.pdf
 |  | C1 | 0.1uF | Midi2cv-eagle-import:0.1UF-KIT-EZ-50V-20% | Capacitor_THT:C_Disc_D4.7mm_W2.5mm_P5.00mm
 |  | C2 | 0.1uF | Midi2cv-eagle-import:0.1UF-KIT-EZ-50V-20% | Capacitor_THT:C_Disc_D4.7mm_W2.5mm_P5.00mm
 |  | C3 | 0.1uF | Midi2cv-eagle-import:0.1UF-KIT-EZ-50V-20% | Capacitor_THT:C_Disc_D4.7mm_W2.5mm_P5.00mm
 |  | C4 | 0.1u | Device:C | Capacitor_THT:C_Disc_D4.7mm_W2.5mm_P5.00mm | ~
 |  | C5 | 4.7u | Device:C_Polarized_US | Capacitor_THT:CP_Radial_D4.0mm_P1.50mm | ~
 |  | C6 | 0.1u | Device:C | Capacitor_THT:C_Disc_D4.7mm_W2.5mm_P5.00mm | ~
 |  | C7 | 4.7u | Device:C_Polarized_US | Capacitor_THT:CP_Radial_D4.0mm_P1.50mm | ~
 |  | D1 | IN4148 | Device:D | Diode_THT:D_DO-35_SOD27_P7.62mm_Horizontal | ~
 |  | D2 | 1N5819 | Diode:1N5819 | Diode_THT:D_DO-41_SOD81_P10.16mm_Horizontal | http://www.vishay.com/docs/88525/1n5817.pdf
 |  | D3 | 1N5819 | Diode:1N5819 | Diode_THT:D_DO-41_SOD81_P10.16mm_Horizontal | http://www.vishay.com/docs/88525/1n5817.pdf
 |  | IC1 | LM324N | Midi2cv-eagle-import:LM324N | Package_DIP:DIP-14_W7.62mm
 |  | J1 | Clock | Connector:AudioJack2_SwitchT | Connector_Audio:Jack_3.5mm_QingPu_WQP-PJ398SM_Vertical_CircularHoles | ~
 |  | J2 | Trigger | Connector:AudioJack2_SwitchT | Connector_Audio:Jack_3.5mm_QingPu_WQP-PJ398SM_Vertical_CircularHoles | ~
 |  | J3 | Gate | Connector:AudioJack2_SwitchT | Connector_Audio:Jack_3.5mm_QingPu_WQP-PJ398SM_Vertical_CircularHoles | ~
 |  | J4 | Pitch Bend | Connector:AudioJack2_SwitchT | Connector_Audio:Jack_3.5mm_QingPu_WQP-PJ398SM_Vertical_CircularHoles | ~
 |  | J5 | Continuous Control | Connector:AudioJack2_SwitchT | Connector_Audio:Jack_3.5mm_QingPu_WQP-PJ398SM_Vertical_CircularHoles | ~
 |  | J6 | Note | Connector:AudioJack2_SwitchT | Connector_Audio:Jack_3.5mm_QingPu_WQP-PJ398SM_Vertical_CircularHoles | ~
 |  | J7 | Velocity | Connector:AudioJack2_SwitchT | Connector_Audio:Jack_3.5mm_QingPu_WQP-PJ398SM_Vertical_CircularHoles | ~
 |  | J8 | Eurorack 16 DIP Header | Connector_Generic:Conn_02x08_Odd_Even | Custom_Footprints:Eurorack_16_pin_header | ~
 |  | R1 | 470 | Midi2cv-eagle-import:R-US_0207{slash}10 | Resistor_THT:R_Axial_DIN0207_L6.3mm_D2.5mm_P7.62mm_Horizontal
 |  | R2 | 220 | Midi2cv-eagle-import:R-US_0207{slash}10 | Resistor_THT:R_Axial_DIN0207_L6.3mm_D2.5mm_P7.62mm_Horizontal
 |  | R3 | 3K | Midi2cv-eagle-import:R-US_0207{slash}10 | Resistor_THT:R_Axial_DIN0207_L6.3mm_D2.5mm_P7.62mm_Horizontal
 |  | R4 | 10K | Midi2cv-eagle-import:R-US_0207{slash}10 | Resistor_THT:R_Axial_DIN0207_L6.3mm_D2.5mm_P7.62mm_Horizontal
 |  | R5 | 1K | Midi2cv-eagle-import:R-US_0207{slash}10 | Resistor_THT:R_Axial_DIN0207_L6.3mm_D2.5mm_P7.62mm_Horizontal
 |  | R6 | 1K | Midi2cv-eagle-import:R-US_0207{slash}10 | Resistor_THT:R_Axial_DIN0207_L6.3mm_D2.5mm_P7.62mm_Horizontal
 |  | R7 | 1K | Midi2cv-eagle-import:R-US_0207{slash}10 | Resistor_THT:R_Axial_DIN0207_L6.3mm_D2.5mm_P7.62mm_Horizontal
 |  | R8 | 4.7K | Midi2cv-eagle-import:R-US_0207{slash}10 | Resistor_THT:R_Axial_DIN0207_L6.3mm_D2.5mm_P7.62mm_Horizontal
 |  | R9 | 10 | Device:R_US | Resistor_THT:R_Axial_DIN0207_L6.3mm_D2.5mm_P7.62mm_Horizontal | ~
 |  | R10 | 10 | Device:R_US | Resistor_THT:R_Axial_DIN0207_L6.3mm_D2.5mm_P7.62mm_Horizontal | ~
 |  | SW1 | SW_SPDT_MSM | Switch:SW_SPDT_MSM | Eurocad:SPDT toggle on-off-on | ~
 |  | U1 | MCP4822 | Analog_DAC:MCP4822 | Package_DIP:DIP-8_W7.62mm | http://ww1.microchip.com/downloads/en/DeviceDoc/20002249B.pdf
 |  | U2 | MCP4822 | Analog_DAC:MCP4822 | Package_DIP:DIP-8_W7.62mm | http://ww1.microchip.com/downloads/en/DeviceDoc/20002249B.pdf
 |  | U3 | PC817 | Isolator:PC817 | Package_DIP:DIP-4_W7.62mm | http://www.soselectronic.cz/a_info/resource/d/pc817.pdf
 |  | U$1 | MIDIJACK | Midi2cv-eagle-import:MIDIJACK | SD-50BV:CUI_SD-50BV
Collated Components:
Item | Qty | Reference(s) | Value | LibPart | Footprint | Datasheet
1 | 1 | A1 | ELEGOO_Nano_V3.0 | MCU_Module:Arduino_Nano_v2.x | Module:Arduino_Nano | https://www.arduino.cc/en/uploads/Main/ArduinoNanoManual23.pdf
2 | 3 | C1, C2, C3 | 0.1uF | Midi2cv-eagle-import:0.1UF-KIT-EZ-50V-20% | Capacitor_THT:C_Disc_D4.7mm_W2.5mm_P5.00mm
3 | 2 | C4, C6 | 0.1u | Device:C | Capacitor_THT:C_Disc_D4.7mm_W2.5mm_P5.00mm | ~
4 | 2 | C5, C7 | 4.7u | Device:C_Polarized_US | Capacitor_THT:CP_Radial_D4.0mm_P1.50mm | ~
5 | 1 | D1 | IN4148 | Device:D | Diode_THT:D_DO-35_SOD27_P7.62mm_Horizontal | ~
6 | 2 | D2, D3 | 1N5819 | Diode:1N5819 | Diode_THT:D_DO-41_SOD81_P10.16mm_Horizontal | http://www.vishay.com/docs/88525/1n5817.pdf
7 | 1 | IC1 | LM324N | Midi2cv-eagle-import:LM324N | Package_DIP:DIP-14_W7.62mm
8 | 1 | J1 | Clock | Connector:AudioJack2_SwitchT | Connector_Audio:Jack_3.5mm_QingPu_WQP-PJ398SM_Vertical_CircularHoles | ~
9 | 1 | J2 | Trigger | Connector:AudioJack2_SwitchT | Connector_Audio:Jack_3.5mm_QingPu_WQP-PJ398SM_Vertical_CircularHoles | ~
10 | 1 | J3 | Gate | Connector:AudioJack2_SwitchT | Connector_Audio:Jack_3.5mm_QingPu_WQP-PJ398SM_Vertical_CircularHoles | ~
11 | 1 | J4 | Pitch Bend | Connector:AudioJack2_SwitchT | Connector_Audio:Jack_3.5mm_QingPu_WQP-PJ398SM_Vertical_CircularHoles | ~
12 | 1 | J5 | Continuous Control | Connector:AudioJack2_SwitchT | Connector_Audio:Jack_3.5mm_QingPu_WQP-PJ398SM_Vertical_CircularHoles | ~
13 | 1 | J6 | Note | Connector:AudioJack2_SwitchT | Connector_Audio:Jack_3.5mm_QingPu_WQP-PJ398SM_Vertical_CircularHoles | ~
14 | 1 | J7 | Velocity | Connector:AudioJack2_SwitchT | Connector_Audio:Jack_3.5mm_QingPu_WQP-PJ398SM_Vertical_CircularHoles | ~
15 | 1 | J8 | Eurorack 16 DIP Header | Connector_Generic:Conn_02x08_Odd_Even | Custom_Footprints:Eurorack_16_pin_header | ~
16 | 1 | R1 | 470 | Midi2cv-eagle-import:R-US_0207{slash}10 | Resistor_THT:R_Axial_DIN0207_L6.3mm_D2.5mm_P7.62mm_Horizontal
17 | 1 | R2 | 220 | Midi2cv-eagle-import:R-US_0207{slash}10 | Resistor_THT:R_Axial_DIN0207_L6.3mm_D2.5mm_P7.62mm_Horizontal
18 | 1 | R3 | 3K | Midi2cv-eagle-import:R-US_0207{slash}10 | Resistor_THT:R_Axial_DIN0207_L6.3mm_D2.5mm_P7.62mm_Horizontal
19 | 1 | R4 | 10K | Midi2cv-eagle-import:R-US_0207{slash}10 | Resistor_THT:R_Axial_DIN0207_L6.3mm_D2.5mm_P7.62mm_Horizontal
20 | 3 | R5, R6, R7 | 1K | Midi2cv-eagle-import:R-US_0207{slash}10 | Resistor_THT:R_Axial_DIN0207_L6.3mm_D2.5mm_P7.62mm_Horizontal
21 | 1 | R8 | 4.7K | Midi2cv-eagle-import:R-US_0207{slash}10 | Resistor_THT:R_Axial_DIN0207_L6.3mm_D2.5mm_P7.62mm_Horizontal
22 | 2 | R9, R10 | 10 | Device:R_US | Resistor_THT:R_Axial_DIN0207_L6.3mm_D2.5mm_P7.62mm_Horizontal | ~
23 | 1 | SW1 | SW_SPDT_MSM | Switch:SW_SPDT_MSM | Eurocad:SPDT toggle on-off-on | ~
24 | 2 | U1, U2 | MCP4822 | Analog_DAC:MCP4822 | Package_DIP:DIP-8_W7.62mm | http://ww1.microchip.com/downloads/en/DeviceDoc/20002249B.pdf
25 | 1 | U3 | PC817 | Isolator:PC817 | Package_DIP:DIP-4_W7.62mm | http://www.soselectronic.cz/a_info/resource/d/pc817.pdf
26 | 1 | U$1 | MIDIJACK | Midi2cv-eagle-import:MIDIJACK | SD-50BV:CUI_SD-50BV

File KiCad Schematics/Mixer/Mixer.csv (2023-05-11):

Source: | /home/josh/Documents/Kicad Projects/Senior Design/Mixer/Mixer.kicad_sch
Date: | Sat 22 Apr 2023 10:41:42 AM CDT
Tool: | Eeschema 7.0.1
Generator: | /usr/share/kicad/plugins/bom_csv_grouped_by_value_with_fp.py
Component Count: | 36
Ref | Qnty | Value | Cmp name | Footprint | Description | Vendor | DNP
C1, C2, C5, C6 | 4 | 0.1u | C_Small | Capacitor_THT:C_Disc_D4.7mm_W2.5mm_P5.00mm | Unpolarized capacitor, small symbol
C3, C4 | 2 | 47u | C_Polarized_US | Capacitor_THT:CP_Radial_D4.0mm_P2.00mm | Polarized capacitor, US symbol
D1, D2 | 2 | 1N5819 | 1N5819 | Diode_THT:D_DO-41_SOD81_P3.81mm_Vertical_KathodeUp | 40V 1A Schottky Barrier Rectifier Diode, DO-41
D3, D4 | 2 | 1N4148 | D | Diode_THT:D_DO-41_SOD81_P2.54mm_Vertical_KathodeUp | Diode
J1 | 1 | Eurorack 10 DIP Header | Conn_02x05_Odd_Even | Custom_Footprints:Eurorack_10_pin_header | Generic connector, double row, 02x05, odd/even pin numbering scheme (row 1 odd numbers, row 2 even numbers), script generated (kicad-library-utils/schlib/autogen/connector/)
J2 | 1 | IN1 | AudioJack2_SwitchT | Connector_Audio:Jack_3.5mm_QingPu_WQP-PJ398SM_Vertical_CircularHoles | Audio Jack, 2 Poles (Mono / TS), Switched T Pole (Normalling)
J3 | 1 | IN2 | AudioJack2_SwitchT | Connector_Audio:Jack_3.5mm_QingPu_WQP-PJ398SM_Vertical_CircularHoles | Audio Jack, 2 Poles (Mono / TS), Switched T Pole (Normalling)
J4 | 1 | IN3 | AudioJack2_SwitchT | Connector_Audio:Jack_3.5mm_QingPu_WQP-PJ398SM_Vertical_CircularHoles | Audio Jack, 2 Poles (Mono / TS), Switched T Pole (Normalling)
J5 | 1 | INV OUT | AudioJack2_SwitchT | Connector_Audio:Jack_3.5mm_QingPu_WQP-PJ398SM_Vertical_CircularHoles | Audio Jack, 2 Poles (Mono / TS), Switched T Pole (Normalling)
J6 | 1 | OUT | AudioJack2_SwitchT | Connector_Audio:Jack_3.5mm_QingPu_WQP-PJ398SM_Vertical_CircularHoles | Audio Jack, 2 Poles (Mono / TS), Switched T Pole (Normalling)
J7 | 1 | CLP OUT | AudioJack2_SwitchT | Connector_Audio:Jack_3.5mm_QingPu_WQP-PJ398SM_Vertical_CircularHoles | Audio Jack, 2 Poles (Mono / TS), Switched T Pole (Normalling)
R1, R2 | 2 | 10 | R_US | Resistor_THT:R_Axial_DIN0207_L6.3mm_D2.5mm_P2.54mm_Vertical | Resistor, US symbol
R3, R4, R5, R6, R7, R8, R11, R13 | 8 | 100k | R_US | Resistor_THT:R_Axial_DIN0207_L6.3mm_D2.5mm_P2.54mm_Vertical | Resistor, US symbol
R9, R10, R14 | 3 | 1k | R_US | Resistor_THT:R_Axial_DIN0207_L6.3mm_D2.5mm_P2.54mm_Vertical | Resistor, US symbol
R12 | 1 | 27k | R_US | Resistor_THT:R_Axial_DIN0207_L6.3mm_D2.5mm_P2.54mm_Vertical | Resistor, US symbol
RV1, RV2, RV3 | 3 | 100k | R_Potentiometer_US | Custom_Footprints:Alpha_9mm_Potentiometer_Aligned | Potentiometer, US symbol
RV4 | 1 | 20k | R_Potentiometer_Trim_US | Custom_Footprints:3296Y1104LF | Trim-potentiometer, US symbol
U1 | 1 | TL074 | TL074 | Package_DIP:DIP-14_W7.62mm | Quad Low-Noise JFET-Input Operational Amplifiers, DIP-14/SOIC-14

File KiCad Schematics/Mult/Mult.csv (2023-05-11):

Source: | /home/josh/Documents/Kicad Projects/Senior Design/Mult/Mult.kicad_sch
Date: | Sat 22 Apr 2023 10:53:35 AM CDT
Tool: | Eeschema 7.0.1
Generator: | /usr/share/kicad/plugins/bom_csv_grouped_by_value_with_fp.py
Component Count: | 37
Ref | Qnty | Value | Cmp name | Footprint | Description | Vendor | DNP
C1, C2, C5, C6, C7, C8 | 6 | 0.1u | C_Small | Capacitor_THT:C_Disc_D4.7mm_W2.5mm_P5.00mm | Unpolarized capacitor, small symbol
C3, C4 | 2 | 47u | C_Polarized_US | Capacitor_THT:CP_Radial_D4.0mm_P2.00mm | Polarized capacitor, US symbol
D1, D2 | 2 | 1N5819 | 1N5819 | Diode_THT:D_DO-41_SOD81_P10.16mm_Horizontal | 40V 1A Schottky Barrier Rectifier Diode, DO-41
J1 | 1 | Eurorack 10 DIP Header | Conn_02x05_Odd_Even | Custom_Footprints:Eurorack_10_pin_header | Generic connector, double row, 02x05, odd/even pin numbering scheme (row 1 odd numbers, row 2 even numbers), script generated (kicad-library-utils/schlib/autogen/connector/)
J2 | 1 | IN2 | AudioJack2_SwitchT | Connector_Audio:Jack_3.5mm_QingPu_WQP-PJ398SM_Vertical_CircularHoles | Audio Jack, 2 Poles (Mono / TS), Switched T Pole (Normalling)
J3, J5 | 2 | OUT1A | AudioJack2_SwitchT | Connector_Audio:Jack_3.5mm_QingPu_WQP-PJ398SM_Vertical_CircularHoles | Audio Jack, 2 Poles (Mono / TS), Switched T Pole (Normalling)
J4 | 1 | OUT2A | AudioJack2_SwitchT | Connector_Audio:Jack_3.5mm_QingPu_WQP-PJ398SM_Vertical_CircularHoles | Audio Jack, 2 Poles (Mono / TS), Switched T Pole (Normalling)
J6 | 1 | IN3 | AudioJack2_SwitchT | Connector_Audio:Jack_3.5mm_QingPu_WQP-PJ398SM_Vertical_CircularHoles | Audio Jack, 2 Poles (Mono / TS), Switched T Pole (Normalling)
J7 | 1 | OUT3C | AudioJack2_SwitchT | Connector_Audio:Jack_3.5mm_QingPu_WQP-PJ398SM_Vertical_CircularHoles | Audio Jack, 2 Poles (Mono / TS), Switched T Pole (Normalling)
J8 | 1 | OUT2C | AudioJack2_SwitchT | Connector_Audio:Jack_3.5mm_QingPu_WQP-PJ398SM_Vertical_CircularHoles | Audio Jack, 2 Poles (Mono / TS), Switched T Pole (Normalling)
J9 | 1 | OUT1C | AudioJack2_SwitchT | Connector_Audio:Jack_3.5mm_QingPu_WQP-PJ398SM_Vertical_CircularHoles | Audio Jack, 2 Poles (Mono / TS), Switched T Pole (Normalling)
J10 | 1 | IN1 | AudioJack2_SwitchT | Connector_Audio:Jack_3.5mm_QingPu_WQP-PJ398SM_Vertical_CircularHoles | Audio Jack, 2 Poles (Mono / TS), Switched T Pole (Normalling)
J11 | 1 | OUT2B | AudioJack2_SwitchT | Connector_Audio:Jack_3.5mm_QingPu_WQP-PJ398SM_Vertical_CircularHoles | Audio Jack, 2 Poles (Mono / TS), Switched T Pole (Normalling)
J12 | 1 | OUT4C | AudioJack2_SwitchT | Connector_Audio:Jack_3.5mm_QingPu_WQP-PJ398SM_Vertical_CircularHoles | Audio Jack, 2 Poles (Mono / TS), Switched T Pole (Normalling)
R1, R7, R11 | 3 | 100k | R_US | Resistor_THT:R_Axial_DIN0207_L6.3mm_D2.5mm_P7.62mm_Horizontal | Resistor, US symbol
R2, R3 | 2 | 10 | R_US | Resistor_THT:R_Axial_DIN0207_L6.3mm_D2.5mm_P7.62mm_Horizontal | Resistor, US symbol
R4, R5, R6, R8, R9, R10, R12, R13 | 8 | 1k | R_US | Resistor_THT:R_Axial_DIN0207_L6.3mm_D2.5mm_P7.62mm_Horizontal | Resistor, US symbol
U1, U2 | 2 | TL074 | TL074 | Package_DIP:DIP-14_W7.62mm | Quad Low-Noise JFET-Input Operational Amplifiers, DIP-14/SOIC-14

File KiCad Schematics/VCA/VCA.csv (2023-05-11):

Source: | /home/josh/Documents/Kicad Projects/Senior Design/VCA/VCA.kicad_sch
Date: | Tue 28 Feb 2023 03:15:13 PM CST
Tool: | Eeschema (6.0.11)
Generator: | /usr/share/kicad/plugins/bom_csv_grouped_by_value.py
Component Count: | 58
Individual Components:
Item | Qty | Reference(s) | Value | LibPart | Footprint | Datasheet | Category | DK_Datasheet_Link | DK_Detail_Page | Description | Digi-Key_PN | Family | MPN | Manufacturer | Status
 |  | BIAS1 | 100k | Device:R_Potentiometer_US | Custom_Footprints:Alpha_9mm_Potentiometer_Aligned | ~
 |  | BIAS2 | 100k | Device:R_Potentiometer_US | Custom_Footprints:Alpha_9mm_Potentiometer_Aligned | ~
 |  | C1 | 0.1u | Device:C | Capacitor_THT:C_Disc_D4.7mm_W2.5mm_P5.00mm | ~
 |  | C2 | 0.1u | Device:C | Capacitor_THT:C_Disc_D4.7mm_W2.5mm_P5.00mm | ~
 |  | C3 | 0.1u | Device:C | Capacitor_THT:C_Disc_D4.7mm_W2.5mm_P5.00mm | ~
 |  | C4 | 0.1u | Device:C | Capacitor_THT:C_Disc_D4.7mm_W2.5mm_P5.00mm | ~
 |  | C5 | 47u | Device:C_Polarized_US | Capacitor_THT:CP_Radial_D4.0mm_P2.00mm | ~
 |  | C6 | 47u | Device:C_Polarized_US | Capacitor_THT:CP_Radial_D4.0mm_P2.00mm | ~
 |  | D1 | 1N5819 | Diode:1N5819 | Diode_THT:D_DO-41_SOD81_P10.16mm_Horizontal | http://www.vishay.com/docs/88525/1n5817.pdf
 |  | D2 | 1N5819 | Diode:1N5819 | Diode_THT:D_DO-41_SOD81_P10.16mm_Horizontal | http://www.vishay.com/docs/88525/1n5817.pdf
 |  | J1 | IN1 | Connector:AudioJack2_SwitchT | Connector_Audio:Jack_3.5mm_QingPu_WQP-PJ398SM_Vertical_CircularHoles | ~
 |  | J2 | CV1 | Connector:AudioJack2_SwitchT | Connector_Audio:Jack_3.5mm_QingPu_WQP-PJ398SM_Vertical_CircularHoles | ~
 |  | J3 | OUT1 | Connector:AudioJack2_SwitchT | Connector_Audio:Jack_3.5mm_QingPu_WQP-PJ398SM_Vertical_CircularHoles | ~
 |  | J4 | Eurorack 10 DIP Header | Connector_Generic:Conn_02x05_Odd_Even | Custom_Footprints:Eurorack_10_pin_header | ~
 |  | J5 | CV2 | Connector:AudioJack2_SwitchT | Connector_Audio:Jack_3.5mm_QingPu_WQP-PJ398SM_Vertical_CircularHoles | ~
 |  | J6 | IN2 | Connector:AudioJack2_SwitchT | Connector_Audio:Jack_3.5mm_QingPu_WQP-PJ398SM_Vertical_CircularHoles | ~
 |  | J7 | OUT2 | Connector:AudioJack2_SwitchT | Connector_Audio:Jack_3.5mm_QingPu_WQP-PJ398SM_Vertical_CircularHoles | ~
 |  | Q1 | BC550 | Device:Q_NPN_BCE | Package_TO_SOT_THT:TO-92L_Inline_Wide | ~
 |  | Q2 | BC550 | Device:Q_NPN_BCE | Package_TO_SOT_THT:TO-92L_Inline_Wide | ~
 |  | Q3 | BC550 | Device:Q_NPN_BCE | Package_TO_SOT_THT:TO-92L_Inline_Wide | ~
 |  | Q4 | BC550 | Device:Q_NPN_BCE | Package_TO_SOT_THT:TO-92L_Inline_Wide | ~
 |  | R1 | 20k | Device:R_US | Resistor_THT:R_Axial_DIN0207_L6.3mm_D2.5mm_P2.54mm_Vertical | ~
 |  | R2 | 100k | Device:R_US | Resistor_THT:R_Axial_DIN0207_L6.3mm_D2.5mm_P2.54mm_Vertical | ~
 |  | R3 | 100k | Device:R_US | Resistor_THT:R_Axial_DIN0207_L6.3mm_D2.5mm_P2.54mm_Vertical | ~
 |  | R4 | 100k | Device:R_US | Resistor_THT:R_Axial_DIN0207_L6.3mm_D2.5mm_P2.54mm_Vertical | ~
 |  | R5 | 100 | Device:R_US | Resistor_THT:R_Axial_DIN0207_L6.3mm_D2.5mm_P2.54mm_Vertical | ~
 |  | R6 | 82k | Device:R_US | Resistor_THT:R_Axial_DIN0207_L6.3mm_D2.5mm_P2.54mm_Vertical | ~
 |  | R7 | 20k | Device:R_US | Resistor_THT:R_Axial_DIN0207_L6.3mm_D2.5mm_P2.54mm_Vertical | ~
 |  | R8 | 10k | Device:R_US | Resistor_THT:R_Axial_DIN0207_L6.3mm_D2.5mm_P2.54mm_Vertical | ~
 |  | R9 | 20k | Device:R_US | Resistor_THT:R_Axial_DIN0207_L6.3mm_D2.5mm_P2.54mm_Vertical | ~
 |  | R10 | 100 | Device:R_US | Resistor_THT:R_Axial_DIN0207_L6.3mm_D2.5mm_P2.54mm_Vertical | ~
 |  | R11 | 100k | Device:R_US | Resistor_THT:R_Axial_DIN0207_L6.3mm_D2.5mm_P2.54mm_Vertical | ~
 |  | R12 | 4.7k | Device:R_US | Resistor_THT:R_Axial_DIN0207_L6.3mm_D2.5mm_P2.54mm_Vertical | ~
 |  | R13 | 4.7k | Device:R_US | Resistor_THT:R_Axial_DIN0207_L6.3mm_D2.5mm_P2.54mm_Vertical | ~
 |  | R14 | 100k | Device:R_US | Resistor_THT:R_Axial_DIN0207_L6.3mm_D2.5mm_P2.54mm_Vertical | ~
 |  | R15 | 100k | Device:R_US | Resistor_THT:R_Axial_DIN0207_L6.3mm_D2.5mm_P2.54mm_Vertical | ~
 |  | R16 | 1k | Device:R_US | Resistor_THT:R_Axial_DIN0207_L6.3mm_D2.5mm_P2.54mm_Vertical | ~
 |  | R17 | 20k | Device:R_US | Resistor_THT:R_Axial_DIN0207_L6.3mm_D2.5mm_P2.54mm_Vertical | ~
 |  | R18 | 100k | Device:R_US | Resistor_THT:R_Axial_DIN0207_L6.3mm_D2.5mm_P2.54mm_Vertical | ~
 |  | R19 | 100k | Device:R_US | Resistor_THT:R_Axial_DIN0207_L6.3mm_D2.5mm_P2.54mm_Vertical | ~
 |  | R20 | 100k | Device:R_US | Resistor_THT:R_Axial_DIN0207_L6.3mm_D2.5mm_P2.54mm_Vertical | ~
 |  | R21 | 100 | Device:R_US | Resistor_THT:R_Axial_DIN0207_L6.3mm_D2.5mm_P2.54mm_Vertical | ~
 |  | R22 | 82k | Device:R_US | Resistor_THT:R_Axial_DIN0207_L6.3mm_D2.5mm_P2.54mm_Vertical | ~
 |  | R23 | 20k | Device:R_US | Resistor_THT:R_Axial_DIN0207_L6.3mm_D2.5mm_P2.54mm_Vertical | ~
 |  | R24 | 10k | Device:R_US | Resistor_THT:R_Axial_DIN0207_L6.3mm_D2.5mm_P2.54mm_Vertical | ~
 |  | R25 | 20k | Device:R_US | Resistor_THT:R_Axial_DIN0207_L6.3mm_D2.5mm_P2.54mm_Vertical | ~
 |  | R26 | 100 | Device:R_US | Resistor_THT:R_Axial_DIN0207_L6.3mm_D2.5mm_P2.54mm_Vertical | ~
 |  | R27 | 100k | Device:R_US | Resistor_THT:R_Axial_DIN0207_L6.3mm_D2.5mm_P2.54mm_Vertical | ~
 |  | R28 | 4.7k | Device:R_US | Resistor_THT:R_Axial_DIN0207_L6.3mm_D2.5mm_P2.54mm_Vertical | ~
 |  | R29 | 4.7k | Device:R_US | Resistor_THT:R_Axial_DIN0207_L6.3mm_D2.5mm_P2.54mm_Vertical | ~
 |  | R30 | 100k | Device:R_US | Resistor_THT:R_Axial_DIN0207_L6.3mm_D2.5mm_P2.54mm_Vertical | ~
 |  | R31 | 100k | Device:R_US | Resistor_THT:R_Axial_DIN0207_L6.3mm_D2.5mm_P2.54mm_Vertical | ~
 |  | R32 | 1k | Device:R_US | Resistor_THT:R_Axial_DIN0207_L6.3mm_D2.5mm_P2.54mm_Vertical | ~
 |  | R33 | 10 | Device:R_US | Resistor_THT:R_Axial_DIN0207_L6.3mm_D2.5mm_P7.62mm_Horizontal | ~
 |  | R34 | 10 | Device:R_US | Resistor_THT:R_Axial_DIN0207_L6.3mm_D2.5mm_P7.62mm_Horizontal | ~
 |  | RV1 | 100k | Device:R_Potentiometer_Trim_US | Potassium's KiCad Footprints:3296Y1502LF | ~
 |  | RV2 | 100k | Device:R_Potentiometer_Trim_US | Potassium's KiCad Footprints:3296Y1502LF | ~
 |  | U1 | TL074CN | dk_Linear-Amplifiers-Instrumentation-OP-Amps-Buffer-Amps:LM324N | digikey-footprints:DIP-14_W3mm | http://www.ti.com/general/docs/suppproductinfo.tsp?distId=10 | Integrated Circuits (ICs) | http://www.ti.com/general/docs/suppproductinfo.tsp?distId=10 | /product-detail/en/texas-instruments/LM324N/296-1391-5-ND/277627 | IC OPAMP GP 4 CIRCUIT 14DIP | 296-1391-5-ND | Linear - Amplifiers - Instrumentation, OP Amps, Buffer Amps | TL074CN | Texas Instruments | Active
Collated Components:
Item | Qty | Reference(s) | Value | LibPart | Footprint | Datasheet | Category | DK_Datasheet_Link | DK_Detail_Page | Description | Digi-Key_PN | Family | MPN | Manufacturer | Status
1 | 2 | BIAS1, BIAS2 | 100k | Device:R_Potentiometer_US | Custom_Footprints:Alpha_9mm_Potentiometer_Aligned | ~
2 | 4 | C1, C2, C3, C4 | 0.1u | Device:C | Capacitor_THT:C_Disc_D4.7mm_W2.5mm_P5.00mm | ~
3 | 2 | C5, C6 | 47u | Device:C_Polarized_US | Capacitor_THT:CP_Radial_D4.0mm_P2.00mm | ~
4 | 2 | D1, D2 | 1N5819 | Diode:1N5819 | Diode_THT:D_DO-41_SOD81_P10.16mm_Horizontal | http://www.vishay.com/docs/88525/1n5817.pdf
5 | 1 | J1 | IN1 | Connector:AudioJack2_SwitchT | Connector_Audio:Jack_3.5mm_QingPu_WQP-PJ398SM_Vertical_CircularHoles | ~
6 | 1 | J2 | CV1 | Connector:AudioJack2_SwitchT | Connector_Audio:Jack_3.5mm_QingPu_WQP-PJ398SM_Vertical_CircularHoles | ~
7 | 1 | J3 | OUT1 | Connector:AudioJack2_SwitchT | Connector_Audio:Jack_3.5mm_QingPu_WQP-PJ398SM_Vertical_CircularHoles | ~
8 | 1 | J4 | Eurorack 10 DIP Header | Connector_Generic:Conn_02x05_Odd_Even | Custom_Footprints:Eurorack_10_pin_header | ~
9 | 1 | J5 | CV2 | Connector:AudioJack2_SwitchT | Connector_Audio:Jack_3.5mm_QingPu_WQP-PJ398SM_Vertical_CircularHoles | ~
10 | 1 | J6 | IN2 | Connector:AudioJack2_SwitchT | Connector_Audio:Jack_3.5mm_QingPu_WQP-PJ398SM_Vertical_CircularHoles | ~
11 | 1 | J7 | OUT2 | Connector:AudioJack2_SwitchT | Connector_Audio:Jack_3.5mm_QingPu_WQP-PJ398SM_Vertical_CircularHoles | ~
12 | 4 | Q1, Q2, Q3, Q4 | BC550 | Device:Q_NPN_BCE | Package_TO_SOT_THT:TO-92L_Inline_Wide | ~
13 | 6 | R1, R7, R9, R17, R23, R25 | 20k | Device:R_US | Resistor_THT:R_Axial_DIN0207_L6.3mm_D2.5mm_P2.54mm_Vertical | ~
14 | 12 | R2, R3, R4, R11, R14, R15, R18, R19, R20, R27, R30, R31 | 100k | Device:R_US | Resistor_THT:R_Axial_DIN0207_L6.3mm_D2.5mm_P2.54mm_Vertical | ~
15 | 4 | R5, R10, R21, R26 | 100 | Device:R_US | Resistor_THT:R_Axial_DIN0207_L6.3mm_D2.5mm_P2.54mm_Vertical | ~
16 | 2 | R6, R22 | 82k | Device:R_US | Resistor_THT:R_Axial_DIN0207_L6.3mm_D2.5mm_P2.54mm_Vertical | ~
17 | 2 | R8, R24 | 10k | Device:R_US | Resistor_THT:R_Axial_DIN0207_L6.3mm_D2.5mm_P2.54mm_Vertical | ~
18 | 4 | R12, R13, R28, R29 | 4.7k | Device:R_US | Resistor_THT:R_Axial_DIN0207_L6.3mm_D2.5mm_P2.54mm_Vertical | ~
19 | 2 | R16, R32 | 1k | Device:R_US | Resistor_THT:R_Axial_DIN0207_L6.3mm_D2.5mm_P2.54mm_Vertical | ~
20 | 2 | R33, R34 | 10 | Device:R_US | Resistor_THT:R_Axial_DIN0207_L6.3mm_D2.5mm_P7.62mm_Horizontal | ~
21 | 2 | RV1, RV2 | 100k | Device:R_Potentiometer_Trim_US | Potassium's KiCad Footprints:3296Y1502LF | ~
22 | 1 | U1 | TL074CN | dk_Linear-Amplifiers-Instrumentation-OP-Amps-Buffer-Amps:LM324N | digikey-footprints:DIP-14_W3mm | http://www.ti.com/general/docs/suppproductinfo.tsp?distId=10 | Integrated Circuits (ICs) | http://www.ti.com/general/docs/suppproductinfo.tsp?distId=10 | /product-detail/en/texas-instruments/LM324N/296-1391-5-ND/277627 | IC OPAMP GP 4 CIRCUIT 14DIP | 296-1391-5-ND | Linear - Amplifiers - Instrumentation, OP Amps, Buffer Amps | TL074CN | Texas Instruments | Active

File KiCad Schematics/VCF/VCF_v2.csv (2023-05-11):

Source: | /home/josh/Documents/Kicad Projects/Senior Design/VCF_v2/VCF_v2.kicad_sch
Date: | Sat 22 Apr 2023 10:35:44 AM CDT
Tool: | Eeschema 7.0.1
Generator: | /usr/share/kicad/plugins/bom_csv_grouped_by_value_with_fp.py
Component Count: | 82
Ref | Qnty | Value | Cmp name | Footprint | Description | Vendor | DNP
C1, C2, C10, C11, C12, C13, C14, C15, C16, C17, C18, C19 | 12 | 0.1u | C | Capacitor_THT:C_Disc_D4.7mm_W2.5mm_P5.00mm | Unpolarized capacitor
C3, C4 | 2 | 47u | C_Polarized_US | Capacitor_THT:CP_Radial_D4.0mm_P2.00mm | Polarized capacitor, US symbol
C5 | 1 | 20p | C | Capacitor_THT:C_Disc_D4.7mm_W2.5mm_P5.00mm | Unpolarized capacitor
C6, C7, C8, C9 | 4 | 100p | C | Capacitor_THT:C_Disc_D4.7mm_W2.5mm_P5.00mm | Unpolarized capacitor
D1, D2 | 2 | 1N5819 | 1N5819 | Diode_THT:D_DO-41_SOD81_P3.81mm_Vertical_KathodeUp | 40V 1A Schottky Barrier Rectifier Diode, DO-41
J1 | 1 | Eurorack 10 DIP Header | Conn_02x05_Odd_Even | Custom_Footprints.pretty-master:Eurorack_10_pin_header | Generic connector, double row, 02x05, odd/even pin numbering scheme (row 1 odd numbers, row 2 even numbers), script generated (kicad-library-utils/schlib/autogen/connector/)
J2 | 1 | CV2 | AudioJack2_SwitchT | Connector_Audio:Jack_3.5mm_QingPu_WQP-PJ398SM_Vertical_CircularHoles | Audio Jack, 2 Poles (Mono / TS), Switched T Pole (Normalling)
J3 | 1 | CV1 | AudioJack2_SwitchT | Connector_Audio:Jack_3.5mm_QingPu_WQP-PJ398SM_Vertical_CircularHoles | Audio Jack, 2 Poles (Mono / TS), Switched T Pole (Normalling)
J4 | 1 | IN | AudioJack2_SwitchT | Connector_Audio:Jack_3.5mm_QingPu_WQP-PJ398SM_Vertical_CircularHoles | Audio Jack, 2 Poles (Mono / TS), Switched T Pole (Normalling)
J5 | 1 | OUT | AudioJack2_SwitchT | Connector_Audio:Jack_3.5mm_QingPu_WQP-PJ398SM_Vertical_CircularHoles | Audio Jack, 2 Poles (Mono / TS), Switched T Pole (Normalling)
J6 | 1 | Comp1 | Conn_01x03 | Connector_PinSocket_2.54mm:PinSocket_1x03_P2.54mm_Vertical | Generic connector, single row, 01x03, script generated (kicad-library-utils/schlib/autogen/connector/)
J7 | 1 | Inter1 | Conn_01x03 | Connector_PinSocket_2.54mm:PinSocket_1x03_P2.54mm_Vertical | Generic connector, single row, 01x03, script generated (kicad-library-utils/schlib/autogen/connector/)
J8 | 1 | Comp2 | Conn_01x05 | Connector_PinSocket_2.54mm:PinSocket_1x05_P2.54mm_Vertical | Generic connector, single row, 01x05, script generated (kicad-library-utils/schlib/autogen/connector/)
J9 | 1 | Inter2 | Conn_01x05 | Connector_PinSocket_2.54mm:PinSocket_1x05_P2.54mm_Vertical | Generic connector, single row, 01x05, script generated (kicad-library-utils/schlib/autogen/connector/)
Q1, Q2, Q3, Q4, Q5 | 5 | 2N3906 | 2N3906 | Package_TO_SOT_THT:TO-92L_Inline_Wide | TRANS PNP 40V TO-92
R1, R2, R3, R14 | 4 | 100k | R_US | Resistor_THT:R_Axial_DIN0204_L3.6mm_D1.6mm_P5.08mm_Horizontal | Resistor, US symbol
R4, R5, R12, R13, R16, R17, R20, R21, R24, R25, R28, R31 | 12 | 100k | R_US | Resistor_THT:R_Axial_DIN0204_L3.6mm_D1.6mm_P2.54mm_Vertical | Resistor, US symbol
R6 | 1 | 1.87k | R_US | Resistor_THT:R_Axial_DIN0204_L3.6mm_D1.6mm_P2.54mm_Vertical | Resistor, US symbol
R7 | 1 | 470 | R_US | Resistor_THT:R_Axial_DIN0204_L3.6mm_D1.6mm_P2.54mm_Vertical | Resistor, US symbol
R8 | 1 | 1Meg | R_US | Resistor_THT:R_Axial_DIN0204_L3.6mm_D1.6mm_P2.54mm_Vertical | Resistor, US symbol
R9 | 1 | 20k | R_US | Resistor_THT:R_Axial_DIN0204_L3.6mm_D1.6mm_P2.54mm_Vertical | Resistor, US symbol
R10, R19, R23, R27 | 4 | 150k | R_US | Resistor_THT:R_Axial_DIN0204_L3.6mm_D1.6mm_P2.54mm_Vertical | Resistor, US symbol
R11 | 1 | 1.8k | R_US | Resistor_THT:R_Axial_DIN0204_L3.6mm_D1.6mm_P2.54mm_Vertical | Resistor, US symbol
R15, R34, R35 | 3 | 1k | R_US | Resistor_THT:R_Axial_DIN0204_L3.6mm_D1.6mm_P5.08mm_Horizontal | Resistor, US symbol
R18, R22, R26 | 3 | 1k | R_US | Resistor_THT:R_Axial_DIN0204_L3.6mm_D1.6mm_P2.54mm_Vertical | Resistor, US symbol
R29 | 1 | 3.9k | R_US | Resistor_THT:R_Axial_DIN0204_L3.6mm_D1.6mm_P2.54mm_Vertical | Resistor, US symbol
R30 | 1 | 10k | R_US | Resistor_THT:R_Axial_DIN0204_L3.6mm_D1.6mm_P2.54mm_Vertical | Resistor, US symbol
R32 | 1 | 220k | R_US | Resistor_THT:R_Axial_DIN0204_L3.6mm_D1.6mm_P5.08mm_Horizontal | Resistor, US symbol
R33 | 1 | 18k | R_US | Resistor_THT:R_Axial_DIN0204_L3.6mm_D1.6mm_P5.08mm_Horizontal | Resistor, US symbol
R36 | 1 | 27k | R_US | Resistor_THT:R_Axial_DIN0204_L3.6mm_D1.6mm_P5.08mm_Horizontal | Resistor, US symbol
RV1 | 1 | 50k | R_Potentiometer_US | Custom_Footprints.pretty-master:Alpha_9mm_Potentiometer_Aligned | Potentiometer, US symbol
RV2, RV3, RV5 | 3 | 100k | R_Potentiometer_US | Custom_Footprints.pretty-master:Alpha_9mm_Potentiometer_Aligned | Potentiometer, US symbol
RV4 | 1 | 100 | R_Potentiometer_Trim_US | Potentiometer_THT:Potentiometer_Bourns_3296Y_Vertical | Trim-potentiometer, US symbol
SW1 | 1 | SW_SPDT | SW_SPDT | Eurocad:SPDT toggle on-off-on | Switch, single pole double throw
U1, U2 | 2 | LM13700 | LM13700 | Package_DIP:DIP-16_W7.62mm | Dual Operational Transconductance Amplifiers with Linearizing Diodes and Buffers, DIP-16/SOIC-16
U3, U4 | 2 | TL074 | TL074 | Package_DIP:DIP-14_W7.62mm | Quad Low-Noise JFET-Input Operational Amplifiers, DIP-14/SOIC-14
U5 | 1 | TL072 | TL072 | Package_DIP:DIP-8_W7.62mm | Dual Low-Noise JFET-Input Operational Amplifiers, DIP-8/SOIC-8

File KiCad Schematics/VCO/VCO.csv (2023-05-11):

Source: | /home/josh/Documents/Kicad Projects/Senior Design/VCO/VCO.kicad_sch
Date: | Tue 28 Feb 2023 02:08:49 PM CST
Tool: | Eeschema (6.0.11)
Generator: | /usr/share/kicad/plugins/bom_csv_grouped_by_value.py
Component Count: | 77
Individual Components:
Item | Qty | Reference(s) | Value | LibPart | Footprint | Datasheet | Category | DK_Datasheet_Link | DK_Detail_Page | Description | Digi-Key_PN | Family | MPN | Manufacturer | Status
 |  | C1 | 30p | Device:C | Capacitor_THT:C_Disc_D4.7mm_W2.5mm_P5.00mm | ~
 |  | C2 | 2.2n | Device:C | Capacitor_THT:C_Disc_D4.7mm_W2.5mm_P5.00mm | ~
 |  | C3 | 1u | Device:C | Capacitor_THT:C_Disc_D4.7mm_W2.5mm_P5.00mm | ~
 |  | C4 | 1u | Device:C | Capacitor_THT:C_Disc_D4.7mm_W2.5mm_P5.00mm | ~
 |  | C5 | 1u | Device:C | Capacitor_THT:C_Disc_D4.7mm_W2.5mm_P5.00mm | ~
 |  | C6 | 0.1u | Device:C | Capacitor_THT:C_Disc_D4.7mm_W2.5mm_P5.00mm | ~
 |  | C7 | 0.1u | Device:C | Capacitor_THT:C_Disc_D4.7mm_W2.5mm_P5.00mm | ~
 |  | C8 | 0.1u | Device:C | Capacitor_THT:C_Disc_D4.7mm_W2.5mm_P5.00mm | ~
 |  | C9 | 0.1u | Device:C | Capacitor_THT:C_Disc_D4.7mm_W2.5mm_P5.00mm | ~
 |  | C10 | 0.1u | Device:C | Capacitor_THT:C_Disc_D4.7mm_W2.5mm_P5.00mm | ~
 |  | C11 | 47u | Device:C_Polarized_US | Capacitor_THT:CP_Radial_D4.0mm_P2.00mm | ~
 |  | C12 | 47u | Device:C_Polarized_US | Capacitor_THT:CP_Radial_D4.0mm_P2.00mm | ~
 |  | C13 | 0.1u | Device:C | Capacitor_THT:C_Disc_D4.7mm_W2.5mm_P5.00mm | ~
 |  | C14 | 0.1u | Device:C | Capacitor_THT:C_Disc_D4.7mm_W2.5mm_P5.00mm | ~
 |  | C15 | 0.1u | Device:C | Capacitor_THT:C_Disc_D4.7mm_W2.5mm_P5.00mm | ~
 |  | C16 | 0.1u | Device:C | Capacitor_THT:C_Disc_D4.7mm_W2.5mm_P5.00mm | ~
 |  | D1 | 1N4148 | Device:D | Diode_THT:D_DO-41_SOD81_P10.16mm_Horizontal | ~
 |  | D2 | 1N4148 | Device:D | Diode_THT:D_DO-41_SOD81_P10.16mm_Horizontal | ~
 |  | D3 | 1N4148 | Device:D | Diode_THT:D_DO-41_SOD81_P10.16mm_Horizontal | ~
 |  | D4 | 1N5819 | Diode:1N5819 | Diode_THT:D_DO-41_SOD81_P10.16mm_Horizontal | http://www.vishay.com/docs/88525/1n5817.pdf
 |  | D5 | 1N5819 | Diode:1N5819 | Diode_THT:D_DO-41_SOD81_P10.16mm_Horizontal | http://www.vishay.com/docs/88525/1n5817.pdf
 |  | IC1 | 300P14-U | 300P14-U:300P14-U | Package_DIP:DIP-14_W7.62mm
 |  | J1 | Eurorack 10 DIP Header | Connector_Generic:Conn_02x05_Odd_Even | Custom_Footprints:Eurorack_10_pin_header | ~
 |  | J2 | FM | Connector:AudioJack2_SwitchT | Connector_Audio:Jack_3.5mm_QingPu_WQP-PJ398SM_Vertical_CircularHoles | ~
 |  | J3 | CV | Connector:AudioJack2_SwitchT | Connector_Audio:Jack_3.5mm_QingPu_WQP-PJ398SM_Vertical_CircularHoles | ~
 |  | J4 | PWM | Connector:AudioJack2_SwitchT | Connector_Audio:Jack_3.5mm_QingPu_WQP-PJ398SM_Vertical_CircularHoles | ~
 |  | J5 | Triangle | Connector:AudioJack2_SwitchT | Connector_Audio:Jack_3.5mm_QingPu_WQP-PJ398SM_Vertical_CircularHoles | ~
 |  | J6 | Saw | Connector:AudioJack2_SwitchT | Connector_Audio:Jack_3.5mm_QingPu_WQP-PJ398SM_Vertical_CircularHoles | ~
 |  | J7 | Pulse | Connector:AudioJack2_SwitchT | Connector_Audio:Jack_3.5mm_QingPu_WQP-PJ398SM_Vertical_CircularHoles | ~
 |  | J8 | Conn_01x03 | Connector_Generic:Conn_01x03 | Connector_PinSocket_2.54mm:PinSocket_1x03_P2.54mm_Vertical | ~
 |  | J9 | Conn_01x03 | Connector_Generic:Conn_01x03 | Connector_PinHeader_2.54mm:PinHeader_1x03_P2.54mm_Vertical | ~
 |  | J10 | Conn_01x06 | Connector_Generic:Conn_01x06 | Connector_PinSocket_2.54mm:PinSocket_1x06_P2.54mm_Vertical | ~
 |  | J11 | Conn_01x06 | Connector_Generic:Conn_01x06 | Connector_PinHeader_2.54mm:PinHeader_1x06_P2.54mm_Vertical | ~
 |  | R1 | 100k | Device:R_US | Resistor_THT:R_Axial_DIN0207_L6.3mm_D2.5mm_P7.62mm_Horizontal | ~
 |  | R2 | 1.87k | Device:R_US | Resistor_THT:R_Axial_DIN0207_L6.3mm_D2.5mm_P7.62mm_Horizontal | ~
 |  | R3 | 1Meg | Device:R_US | Resistor_THT:R_Axial_DIN0207_L6.3mm_D2.5mm_P7.62mm_Horizontal | ~
 |  | R4 | 500 | Device:R_US | Resistor_THT:R_Axial_DIN0207_L6.3mm_D2.5mm_P7.62mm_Horizontal | ~
 |  | R5 | 100k | Device:R_US | Resistor_THT:R_Axial_DIN0207_L6.3mm_D2.5mm_P7.62mm_Horizontal | ~
 |  | R6 | 100k | Device:R_US | Resistor_THT:R_Axial_DIN0207_L6.3mm_D2.5mm_P7.62mm_Horizontal | ~
 |  | R7 | 1Meg | Device:R_US | Resistor_THT:R_Axial_DIN0207_L6.3mm_D2.5mm_P7.62mm_Horizontal | ~
 |  | R8 | 100k | Device:R_US | Resistor_THT:R_Axial_DIN0207_L6.3mm_D2.5mm_P7.62mm_Horizontal | ~
 |  | R9 | 100k | Device:R_US | Resistor_THT:R_Axial_DIN0207_L6.3mm_D2.5mm_P7.62mm_Horizontal | ~
 |  | R10 | 33k | Device:R_US | Resistor_THT:R_Axial_DIN0207_L6.3mm_D2.5mm_P7.62mm_Horizontal | ~
 |  | R11 | 100k | Device:R_US | Resistor_THT:R_Axial_DIN0207_L6.3mm_D2.5mm_P7.62mm_Horizontal | ~
 |  | R12 | 100k | Device:R_US | Resistor_THT:R_Axial_DIN0207_L6.3mm_D2.5mm_P7.62mm_Horizontal | ~
 |  | R13 | 68k | Device:R_US | Resistor_THT:R_Axial_DIN0207_L6.3mm_D2.5mm_P7.62mm_Horizontal | ~
 |  | R14 | 47k | Device:R_US | Resistor_THT:R_Axial_DIN0207_L6.3mm_D2.5mm_P7.62mm_Horizontal | ~
 |  | R15 | 100k | Device:R_US | Resistor_THT:R_Axial_DIN0207_L6.3mm_D2.5mm_P7.62mm_Horizontal | ~
 |  | R16 | 1k | Device:R_US | Resistor_THT:R_Axial_DIN0207_L6.3mm_D2.5mm_P7.62mm_Horizontal | ~
 |  | R17 | 14k | Device:R_US | Resistor_THT:R_Axial_DIN0207_L6.3mm_D2.5mm_P7.62mm_Horizontal | ~
 |  | R18 | 100k | Device:R_US | Resistor_THT:R_Axial_DIN0207_L6.3mm_D2.5mm_P7.62mm_Horizontal | ~
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

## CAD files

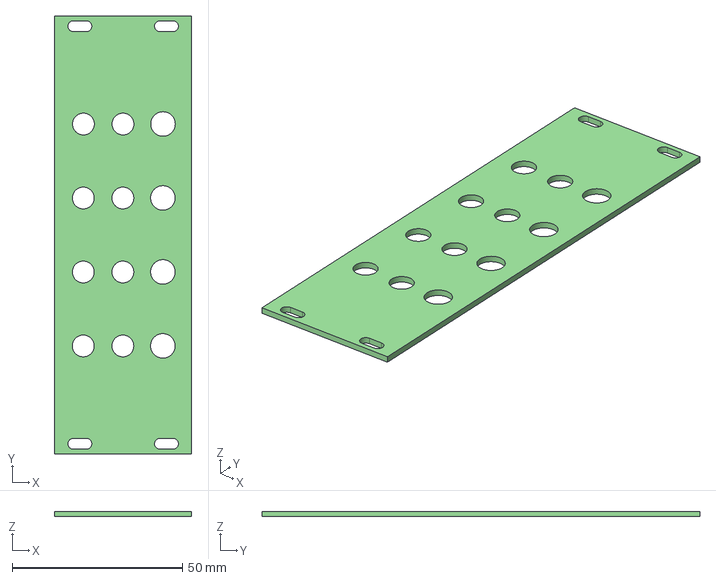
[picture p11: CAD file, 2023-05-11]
KiCad Schematics/Attenuverter/Attenuverter_PANEL.step
40.3 x 128.5 x 1.60 mm

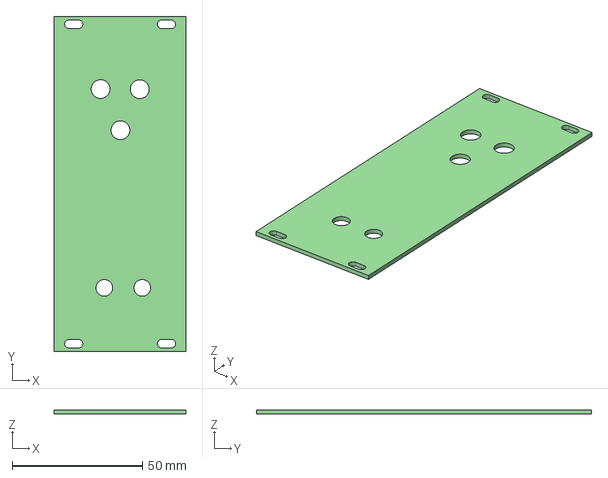
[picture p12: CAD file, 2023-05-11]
KiCad Schematics/Delay/DelayPCBPanel.step
50.5 x 128.5 x 1.60 mm

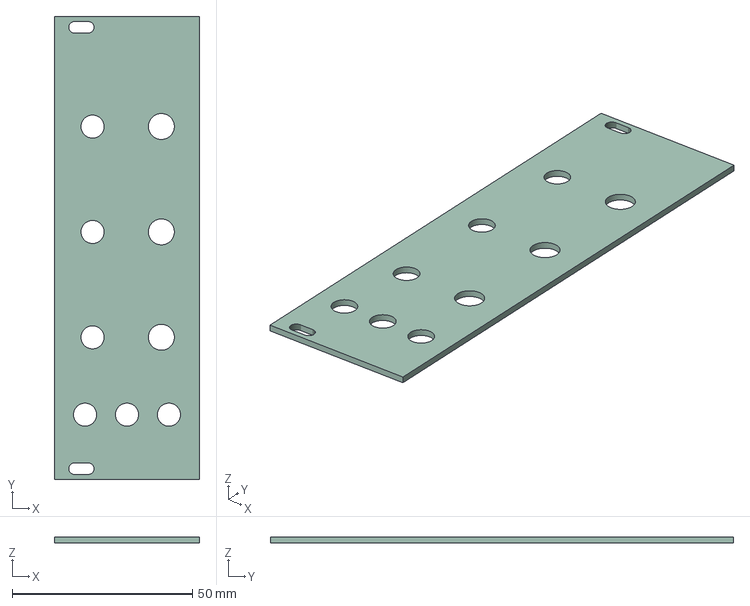
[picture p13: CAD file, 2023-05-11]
KiCad Schematics/Mixer/Mixer_PANEL.step
40.3 x 128.5 x 1.58 mm

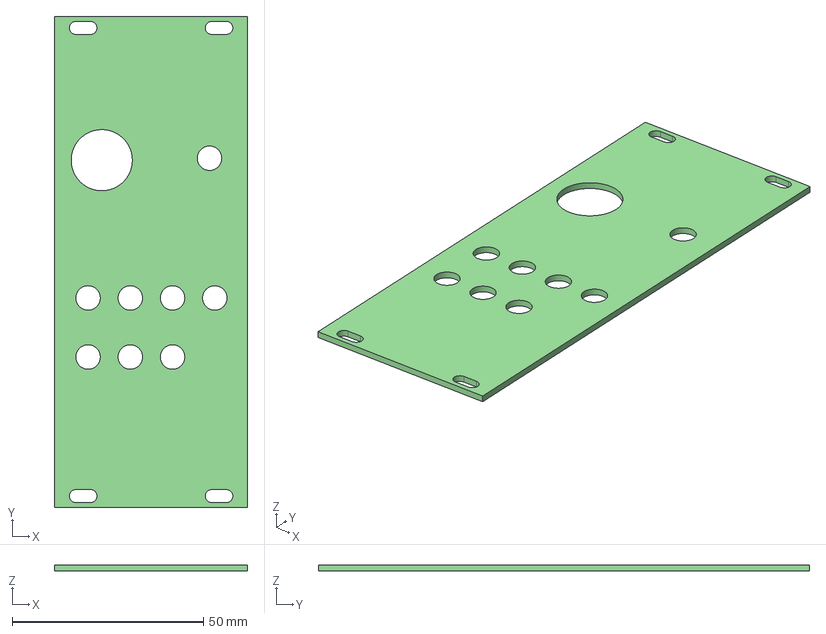
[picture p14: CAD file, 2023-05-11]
KiCad Schematics/Midi2cv/Midi2cv - panel/Midi2cv - panel - V2.step
50.5 x 128.5 x 1.60 mm

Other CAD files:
KiCad Schematics/Midi2cv/Midi2cv - panel/Midi2cv - panel.step
KiCad Schematics/Mult/Mult done-PANEL.step
KiCad Schematics/VCA/VCA_PANEL.step
KiCad Schematics/VCF/VCF-FRONT_PANEL_v2.step
KiCad Schematics/VCO/VCO_INTERFACE_PANEL.step
Steps/Mult done-PANEL.step
KiCad Schematics/Delay/DelayBoard2PanelBoard.step
Steps/Mixer_PANEL.step
Steps/VCO_INTERFACE_PANEL.step
Steps/VCA_PANEL.step
Steps/DelayBoard2PanelBoard.step
Steps/VCF-FRONT_PANEL_v2.step
Steps/Midi2cv - panel - V2.step
Steps/LFO_3_10HP_INTERFACE_PANEL.step
KiCad Schematics/Delay/DelayPCBPanel.3mf
KiCad Schematics/Midi2cv/Midi2cv - panel/Midi2cv - panel.3mf
Steps/ASDR_PANEL.step
Steps/Attenuverter_PANEL.step

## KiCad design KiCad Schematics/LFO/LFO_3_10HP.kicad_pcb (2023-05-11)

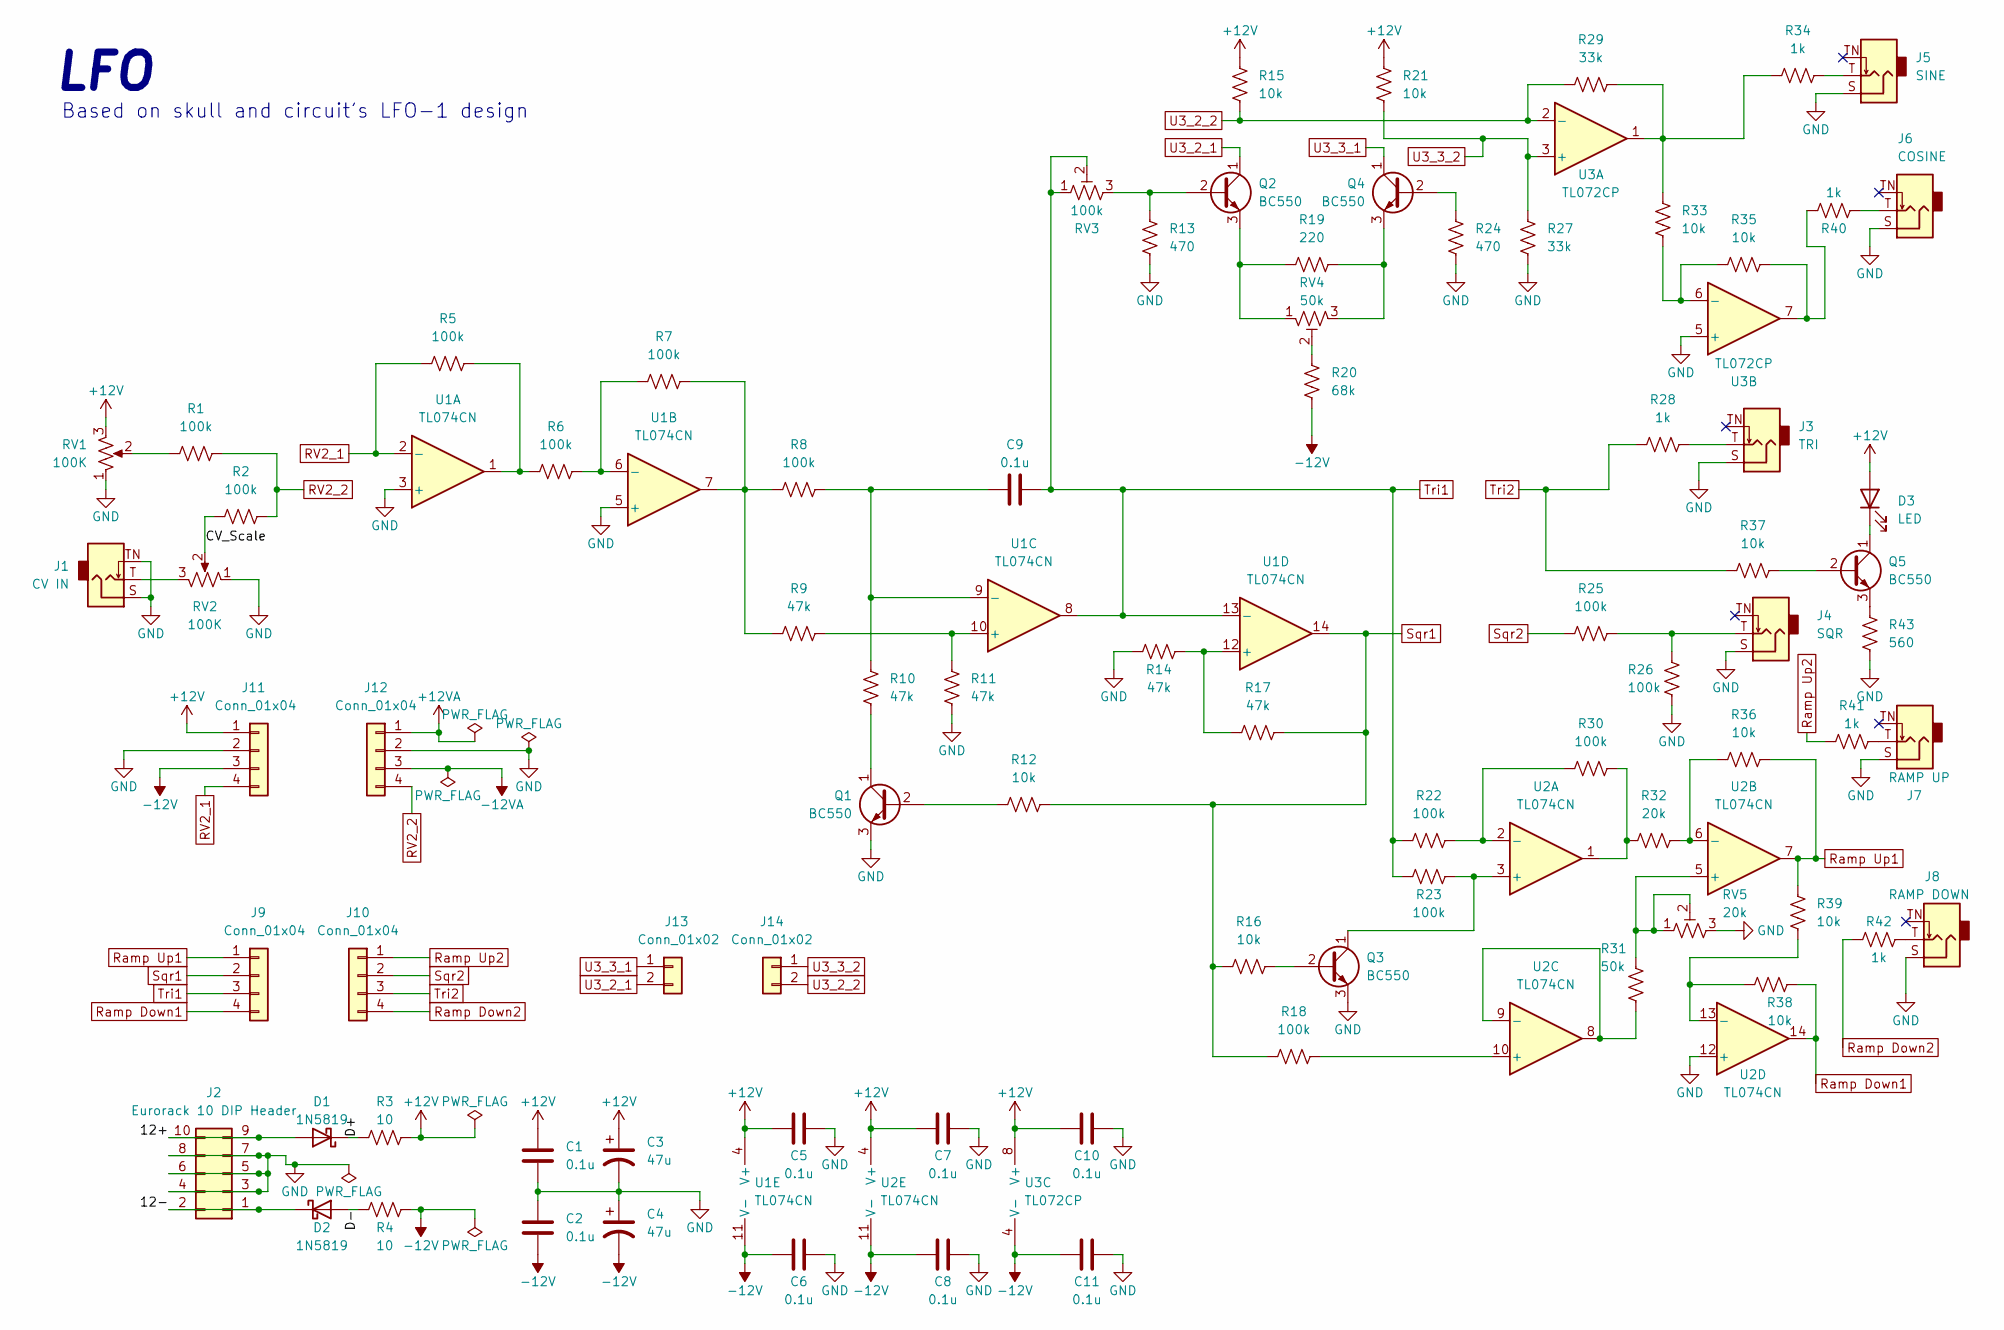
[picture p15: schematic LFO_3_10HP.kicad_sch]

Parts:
C1, C2, C5, C6, C7, C8, C9, C10, C11: 0.1u; C_Disc_D4.7mm_W2.5mm_P5.00mm
C3, C4: 47u; CP_Radial_D4.0mm_P2.00mm
D1, D2: 1N5819; D_DO-41_SOD81_P10.16mm_Horizontal
D3: LED; LED_D5.0mm
J1: CV IN; Jack_3.5mm_QingPu_WQP-PJ398SM_Vertical_CircularHoles
J2: Eurorack 10 DIP Header; Eurorack_10_pin_header
J3: TRI; Jack_3.5mm_QingPu_WQP-PJ398SM_Vertical_CircularHoles
J4: SQR; Jack_3.5mm_QingPu_WQP-PJ398SM_Vertical_CircularHoles
J5: SINE; Jack_3.5mm_QingPu_WQP-PJ398SM_Vertical_CircularHoles
J6: COSINE; Jack_3.5mm_QingPu_WQP-PJ398SM_Vertical_CircularHoles
J7: RAMP UP; Jack_3.5mm_QingPu_WQP-PJ398SM_Vertical_CircularHoles
J8: RAMP DOWN; Jack_3.5mm_QingPu_WQP-PJ398SM_Vertical_CircularHoles
J9, J10, J11, J12: Conn_01x04; PinHeader_1x04_P2.54mm_Vertical
J13, J14: Conn_01x02; PinHeader_1x02_P2.54mm_Vertical
Q1, Q2, Q3, Q4, Q5: BC550; TO-92_Inline_Wide
R1, R2, R5, R6, R7, R8, R18, R22, R23, R25, R26, R30: 100k; R_Axial_DIN0207_L6.3mm_D2.5mm_P7.62mm_Horizontal
R3, R4: 10; R_Axial_DIN0207_L6.3mm_D2.5mm_P7.62mm_Horizontal
R9, R10, R11, R14, R17: 47k; R_Axial_DIN0207_L6.3mm_D2.5mm_P7.62mm_Horizontal
R12, R15, R16, R21, R33, R35, R36, R37, R38, R39: 10k; R_Axial_DIN0207_L6.3mm_D2.5mm_P7.62mm_Horizontal
R13, R24: 470; R_Axial_DIN0207_L6.3mm_D2.5mm_P7.62mm_Horizontal
R19: 220; R_Axial_DIN0207_L6.3mm_D2.5mm_P7.62mm_Horizontal
R20: 68k; R_Axial_DIN0207_L6.3mm_D2.5mm_P7.62mm_Horizontal
R27, R29: 33k; R_Axial_DIN0207_L6.3mm_D2.5mm_P7.62mm_Horizontal
R28, R34, R40, R41, R42: 1k; R_Axial_DIN0207_L6.3mm_D2.5mm_P7.62mm_Horizontal
R31: 50k; R_Axial_DIN0207_L6.3mm_D2.5mm_P7.62mm_Horizontal
R32: 20k; R_Axial_DIN0207_L6.3mm_D2.5mm_P7.62mm_Horizontal
R43: 560; R_Axial_DIN0207_L6.3mm_D2.5mm_P7.62mm_Horizontal
RV1, RV2: 100K; Alpha_9mm_Potentiometer_Aligned
RV3: 100k; 3296Y-1-502LF
RV4: 50k; 3296Y-1-502LF
RV5: 20k; 3296Y-1-502LF
U1, U2: TL074CN; DIP794W45P254L1969H508Q14
U3: TL072CP; DIP794W45P254L959H508Q8

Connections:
/12+: D1.2 (A), J2.9, J2.10
/12-: D2.1 (K), J2.1, J2.2
/CV_Scale: R2.1, RV2.2
/D+: D1.1 (K), R3.2
/D-: D2.2 (A), R4.2
GND: C1.1, C2.2, C3.2, C4.1, C5.2, C6.2, C7.2, C8.2, C10.2, C11.2, J1.S, J1.TN, J2.3, J2.4, J2.5, J2.6, J2.7, J2.8, J3.S, J4.S, J5.S, J6.S, J7.S, J8.S, J11.2, J12.2, Q1.3 (E), Q3.3 (E), R11.1, R13.2, R14.1, R24.2, R26.2, R27.2, R43.2, RV1.1, RV2.1, RV5.3, U1.3 (+), U1.5 (+), U2.12 (+), U3.5 (+)
unnamed: C9.1, R8.2, R10.2, U1.9 (-)
unnamed: D3.1 (K), Q5.1 (C)
unnamed: J1.T, RV2.3
unnamed: J3.T, R28.1
unnamed: J4.T, R25.1, R26.1
unnamed: J5.T, R34.1
unnamed: J6.T, R40.1
unnamed: J7.T, R41.1
unnamed: J8.T, R42.1
unnamed: Q1.1 (C), R10.1
unnamed: Q1.2 (B), R12.2
unnamed: Q2.2 (B), R13.1, RV3.3
unnamed: Q2.3 (E), R19.2, RV4.1
unnamed: Q3.1 (C), R23.1, U2.3 (+)
unnamed: Q3.2 (B), R16.1
unnamed: Q4.2 (B), R24.1
unnamed: Q4.3 (E), R19.1, RV4.3
unnamed: Q5.2 (B), R37.1
unnamed: Q5.3 (E), R43.1
unnamed: R1.1, RV1.2
unnamed: R5.2, R6.1, U1.1
unnamed: R6.2, R7.1, U1.6 (-)
unnamed: R7.2, R8.1, R9.1, U1.7
unnamed: R9.2, R11.2, U1.10 (+)
unnamed: R14.2, R17.2, U1.12 (+)
unnamed: R18.1, U2.10 (+)
unnamed: R20.1, RV4.2
unnamed: R22.1, R30.2, U2.2 (-)
unnamed: R29.2, R33.1, R34.2, U3.1
unnamed: R30.1, R32.2, U2.1
unnamed: R31.1, RV5.1, RV5.2, U2.5 (+)
unnamed: R31.2, U2.8, U2.9 (-)
unnamed: R32.1, R36.2, U2.6 (-)
unnamed: R33.2, R35.1, U3.6 (-)
unnamed: R35.2, R40.2, U3.7
unnamed: R38.2, R39.2, U2.13 (-)
RV2_1: J11.4, R5.1, U1.2 (-)
RV2_2: J12.4, R1.2, R2.2
Ramp Down1: J9.4, R38.1, U2.14
Ramp Down2: J10.4, R42.2
Ramp Up1: J9.1, R36.1, R39.1, U2.7
Ramp Up2: J10.1, R41.2
Sqr1: J9.2, R12.1, R16.2, R17.1, R18.2, U1.14
Sqr2: J10.2, R25.2
Tri1: C9.2, J9.3, R22.2, R23.2, RV3.1, RV3.2, U1.8, U1.13 (-)
Tri2: J10.3, R28.2, R37.2
U3_2_1: J13.2, Q2.1 (C)
U3_2_2: J14.2, R15.2, R29.1, U3.2 (-)
U3_3_1: J13.1, Q4.1 (C)
U3_3_2: J14.1, R21.2, R27.1, U3.3 (+)

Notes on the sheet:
LFO
Based on skull and circuit's LFO-1 design

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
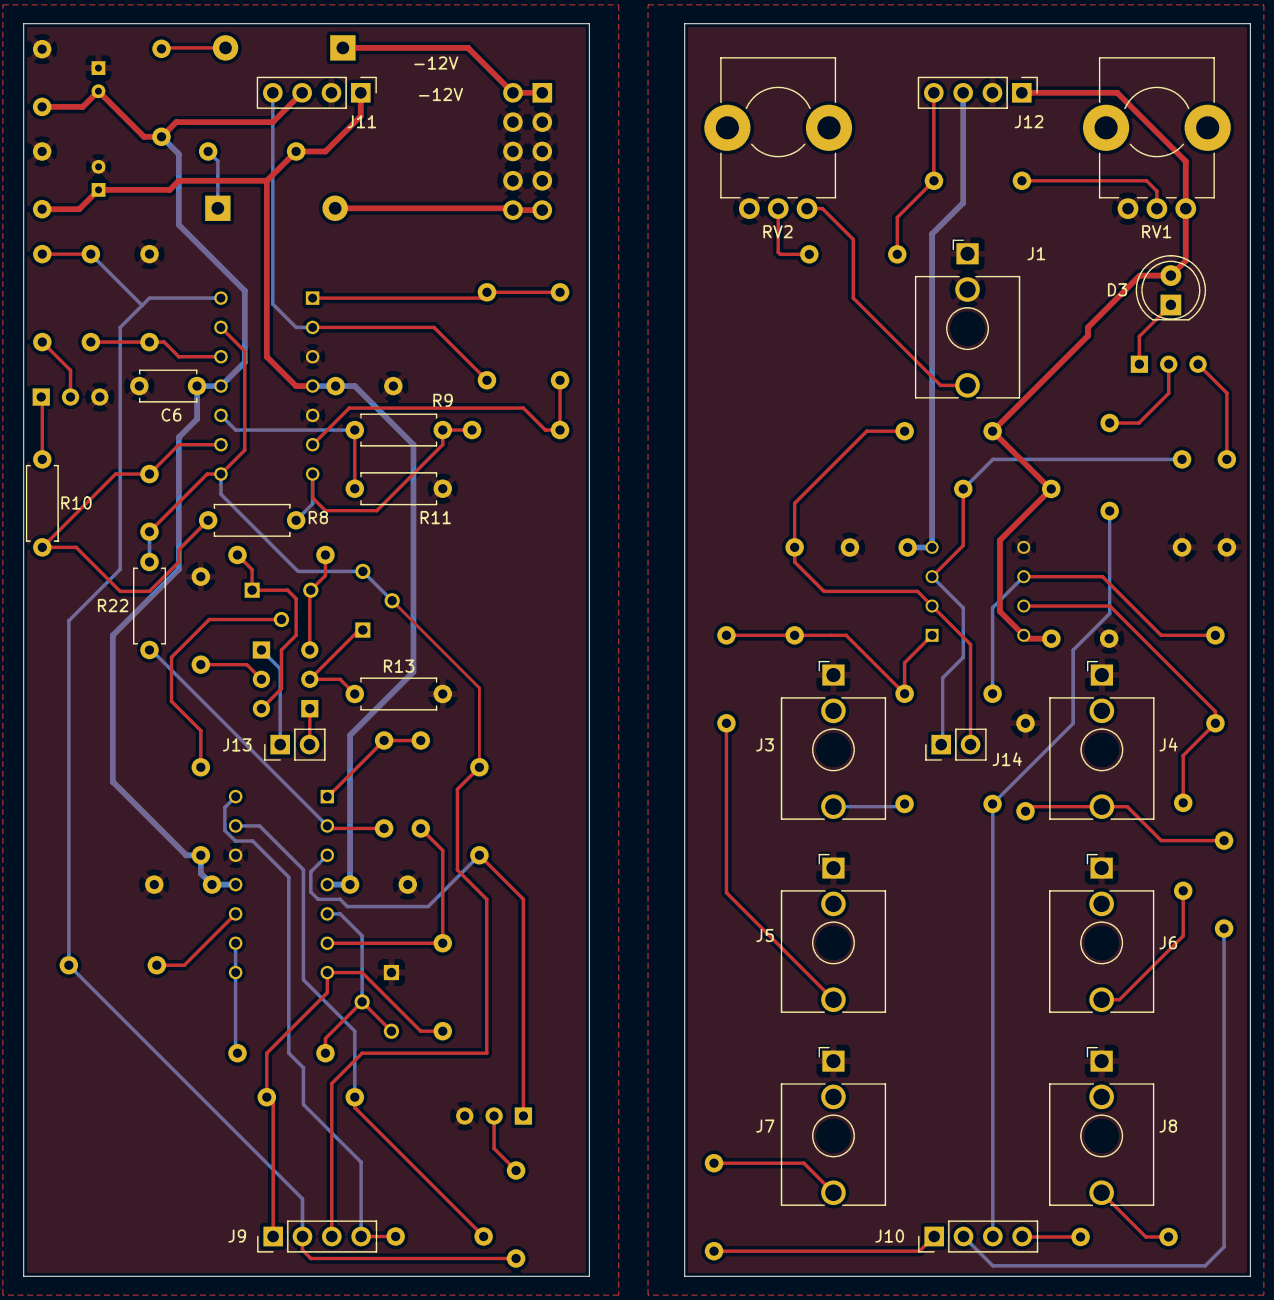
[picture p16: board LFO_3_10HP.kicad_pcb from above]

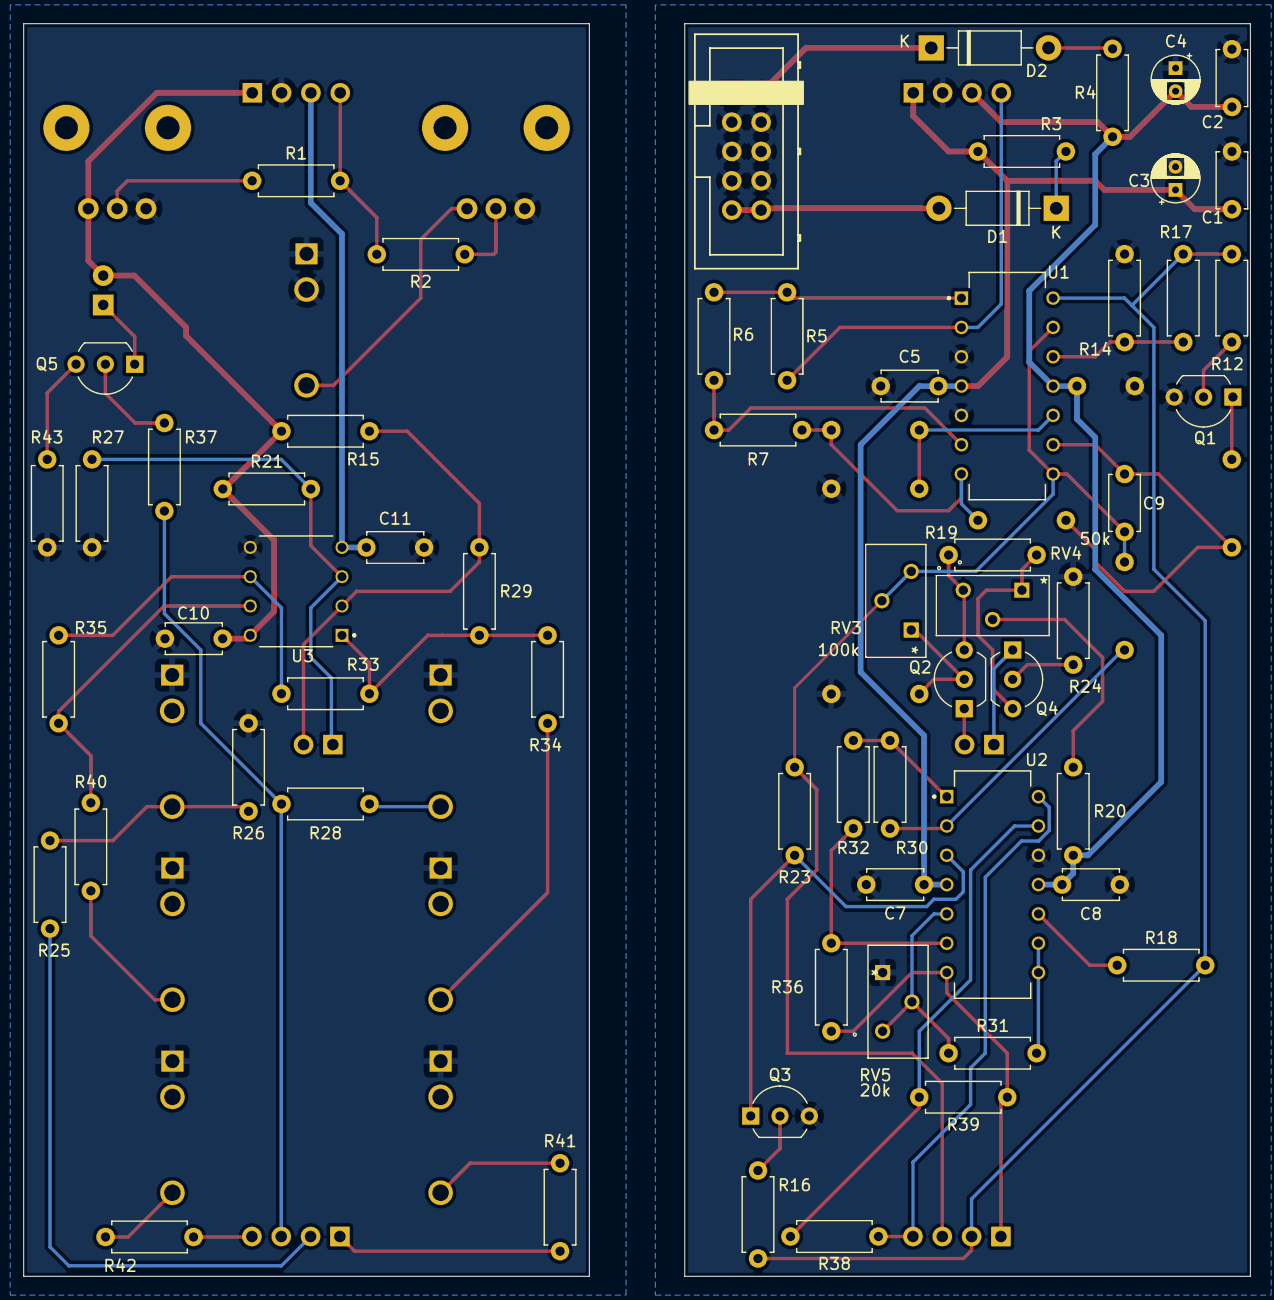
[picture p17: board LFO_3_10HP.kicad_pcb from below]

Board: 2 copper layers, 106.3 x 108.5 mm, 84 parts (61 on the bottom side), 60 nets.

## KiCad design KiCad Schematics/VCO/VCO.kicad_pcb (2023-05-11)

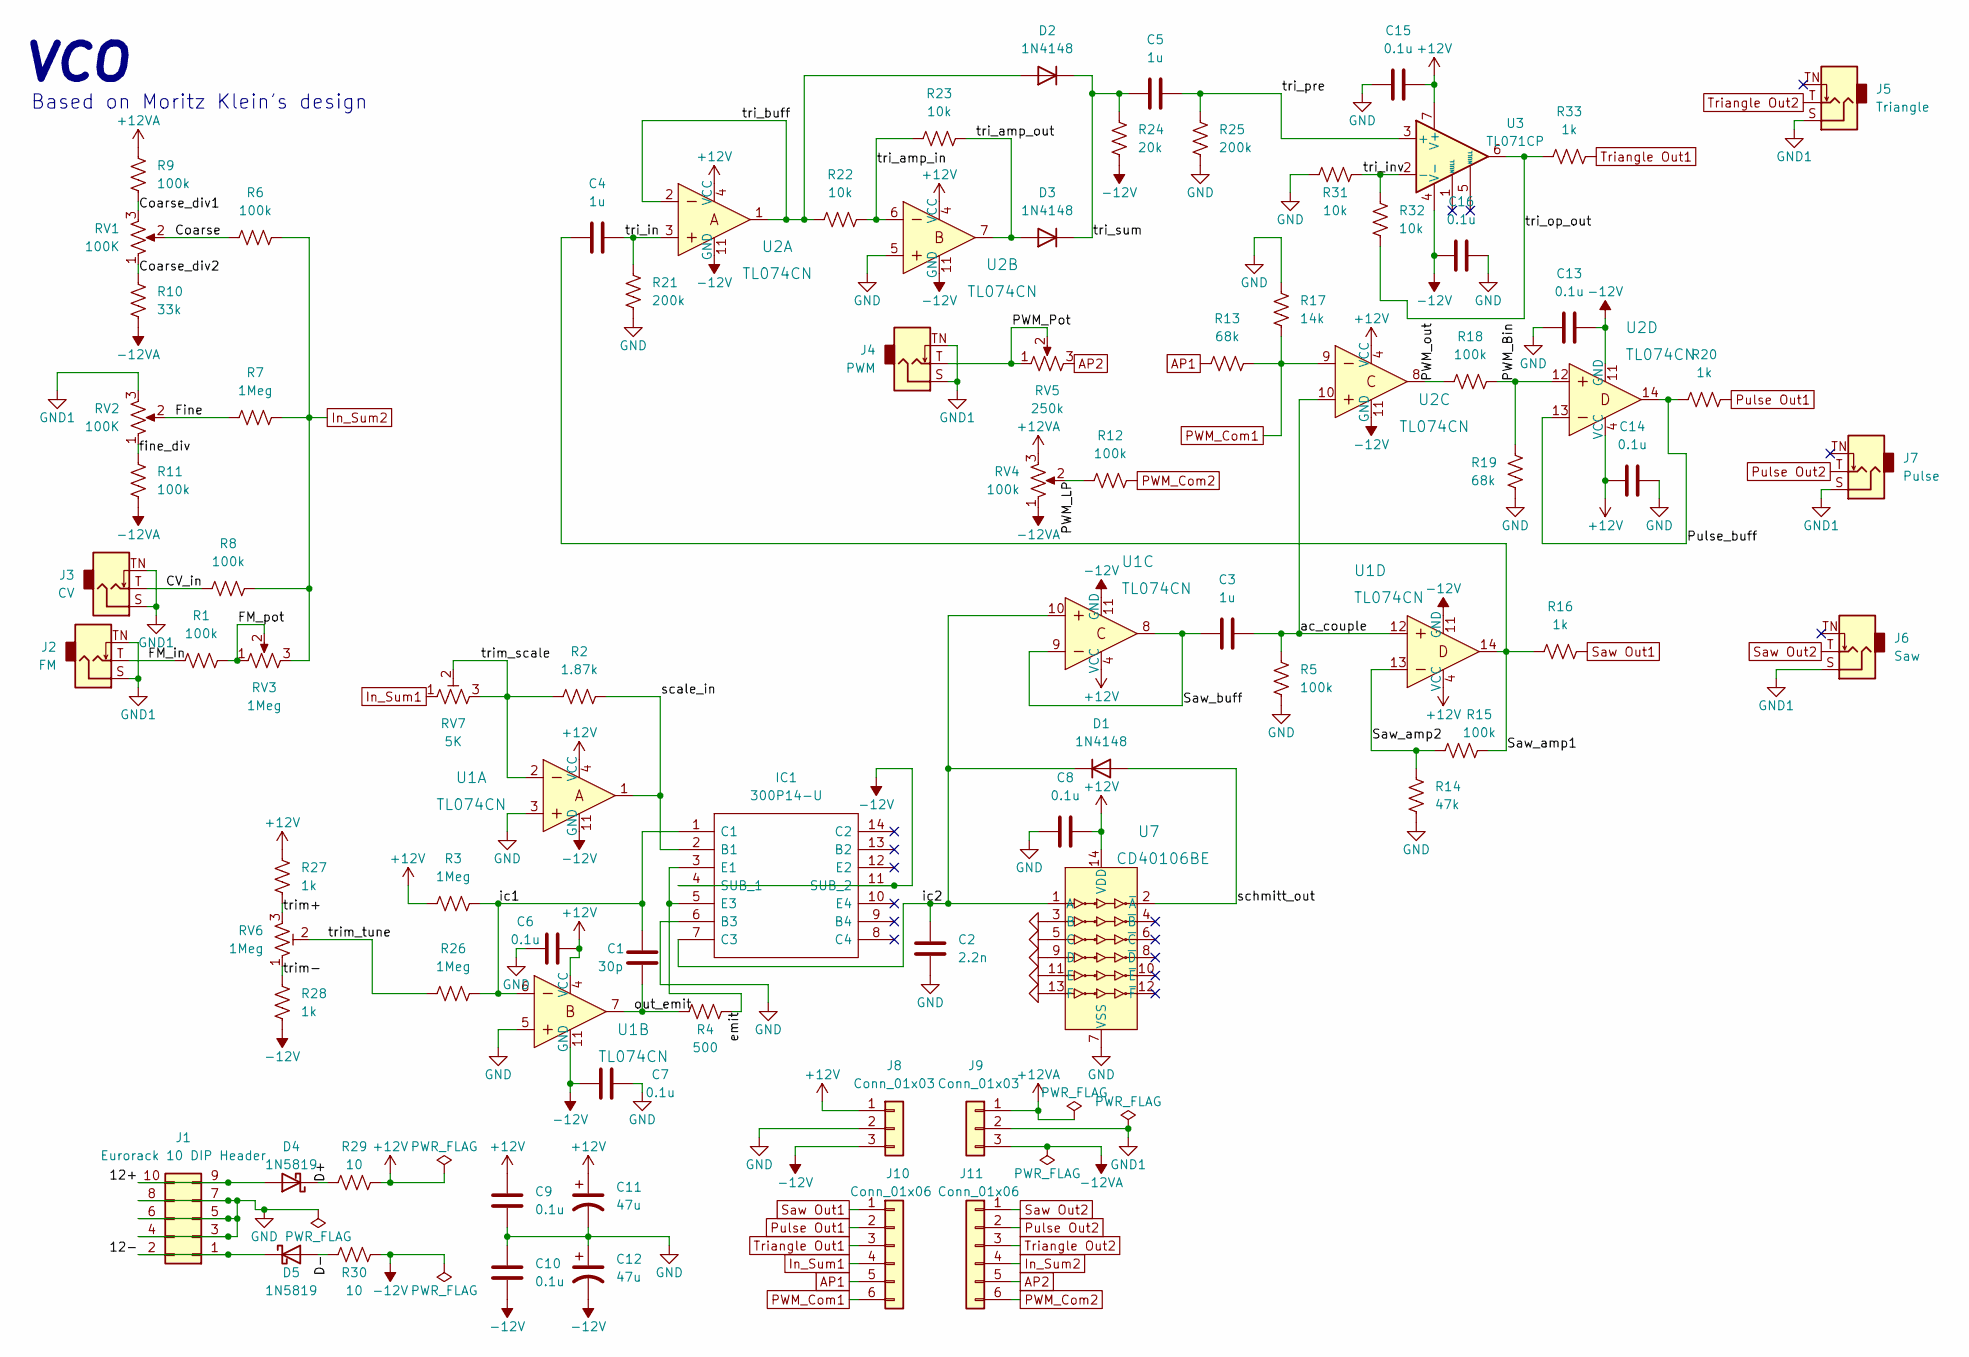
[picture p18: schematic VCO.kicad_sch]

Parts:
C1: 30p; C_Disc_D4.7mm_W2.5mm_P5.00mm
C2: 2.2n; C_Disc_D4.7mm_W2.5mm_P5.00mm
C3, C4, C5: 1u; C_Disc_D4.7mm_W2.5mm_P5.00mm
C6, C7, C8, C9, C10, C13, C14, C15, C16: 0.1u; C_Disc_D4.7mm_W2.5mm_P5.00mm
C11, C12: 47u; CP_Radial_D4.0mm_P2.00mm
D1, D2, D3: 1N4148; D_DO-41_SOD81_P10.16mm_Horizontal
D4, D5: 1N5819; D_DO-41_SOD81_P10.16mm_Horizontal
IC1: 300P14-U; DIP-14_W7.62mm
J1: Eurorack 10 DIP Header; Eurorack_10_pin_header
J2: FM; Jack_3.5mm_QingPu_WQP-PJ398SM_Vertical_CircularHoles
J3: CV; Jack_3.5mm_QingPu_WQP-PJ398SM_Vertical_CircularHoles
J4: PWM; Jack_3.5mm_QingPu_WQP-PJ398SM_Vertical_CircularHoles
J5: Triangle; Jack_3.5mm_QingPu_WQP-PJ398SM_Vertical_CircularHoles
J6: Saw; Jack_3.5mm_QingPu_WQP-PJ398SM_Vertical_CircularHoles
J7: Pulse; Jack_3.5mm_QingPu_WQP-PJ398SM_Vertical_CircularHoles
J8: Conn_01x03; PinSocket_1x03_P2.54mm_Vertical
J9: Conn_01x03; PinHeader_1x03_P2.54mm_Vertical
J10: Conn_01x06; PinSocket_1x06_P2.54mm_Vertical
J11: Conn_01x06; PinHeader_1x06_P2.54mm_Vertical
R1, R5, R6, R8, R9, R11, R12, R15, R18: 100k; R_Axial_DIN0207_L6.3mm_D2.5mm_P7.62mm_Horizontal
R2: 1.87k; R_Axial_DIN0207_L6.3mm_D2.5mm_P7.62mm_Horizontal
R3, R7, R26: 1Meg; R_Axial_DIN0207_L6.3mm_D2.5mm_P7.62mm_Horizontal
R4: 500; R_Axial_DIN0207_L6.3mm_D2.5mm_P7.62mm_Horizontal
R10: 33k; R_Axial_DIN0207_L6.3mm_D2.5mm_P7.62mm_Horizontal
R13, R19: 68k; R_Axial_DIN0207_L6.3mm_D2.5mm_P7.62mm_Horizontal
R14: 47k; R_Axial_DIN0207_L6.3mm_D2.5mm_P7.62mm_Horizontal
R16, R20, R27, R28, R33: 1k; R_Axial_DIN0207_L6.3mm_D2.5mm_P7.62mm_Horizontal
R17: 14k; R_Axial_DIN0207_L6.3mm_D2.5mm_P7.62mm_Horizontal
R21, R25: 200k; R_Axial_DIN0207_L6.3mm_D2.5mm_P7.62mm_Horizontal
R22, R23, R31, R32: 10k; R_Axial_DIN0207_L6.3mm_D2.5mm_P7.62mm_Horizontal
R24: 20k; R_Axial_DIN0207_L6.3mm_D2.5mm_P7.62mm_Horizontal
R29, R30: 10; R_Axial_DIN0207_L6.3mm_D2.5mm_P7.62mm_Horizontal
RV1, RV2: 100K; Alpha_9mm_Potentiometer_Aligned
RV3: 1Meg; Alpha_9mm_Potentiometer_Aligned
RV4: 100k; Alpha_9mm_Potentiometer_Aligned
RV5: 250k; Alpha_9mm_Potentiometer_Aligned
RV6: 1Meg; 3296Y1502LF
RV7: 5K; 3296Y1502LF
U1, U2: TL074CN; DIP-14_W3mm
U3: TL071CP; DIP-8_W7.62mm
U7: CD40106BE; DIP-14_W3mm; MPN CD40106BE; Digi-Key_PN 296-3503-5-ND

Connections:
+12V: C6.1, C8.2, C9.2, C11.1, C14.2, C15.1, J8.1, R3.1, R27.2, R29.1, U1.4 (VCC), U2.4 (VCC), U3.7 (V+), U7.14 (VDD)
+12VA: J9.1, R9.2, RV4.3
-12V: C7.2, C10.1, C12.2, C13.1, C16.2, IC1.4 (SUB_1), IC1.11 (SUB_2), J8.3, R24.1, R28.1, R30.1, U1.11 (GND), U2.11 (GND), U3.4 (V-)
-12VA: J9.3, R10.1, R11.1, RV4.1
/12+: D4.2 (A), J1.9, J1.10
/12-: D5.1 (K), J1.1, J1.2
/CV_in: J3.T, R8.1
/Coarse: R6.1, RV1.2
/Coarse_div1: R9.1, RV1.3
/Coarse_div2: R10.2, RV1.1
/D+: D4.1 (K), R29.2
/D-: D5.2 (A), R30.2
/FM_in: J2.T, R1.1
/FM_pot: R1.2, RV3.1, RV3.2
/Fine: R7.1, RV2.2
/PWM_Bin: R18.2, R19.2, U2.12
/PWM_LP: R12.2, RV4.2
/PWM_Pot: J4.T, RV5.1, RV5.2
/PWM_out: R18.1, U2.8
/Pulse_buff: R20.1, U2.13, U2.14
/Saw_amp1: C4.1, R15.2, R16.1, U1.14
/Saw_amp2: R14.1, R15.1, U1.13
/Saw_buff: C3.1, U1.8, U1.9
/ac_couple: C3.2, R5.1, U1.12, U2.10
/emit: IC1.3 (E1), IC1.5 (E3), R4.2
/fine_div: R11.2, RV2.1
/ic1: C1.1, IC1.1 (C1), R3.2, R26.2, U1.6
/ic2: C2.1, D1.1 (K), IC1.7 (C3), U1.10, U7.1 (A)
/out_emit: C1.2, R4.1, U1.7
/scale_in: IC1.2 (B1), R2.2, U1.1
/schmitt_out: D1.2 (A), U7.2 (~A)
/tri_amp_in: R22.1, R23.2, U2.6
/tri_amp_out: D3.2 (A), R23.1, U2.7
/tri_buff: D2.2 (A), R22.2, U2.1, U2.2
/tri_in: C4.2, R21.2, U2.3
/tri_inv: R31.2, R32.2, U3.2 (-)
/tri_op_out: R32.1, R33.1, U3.6
/tri_pre: C5.2, R25.2, U3.3 (+)
/tri_sum: C5.1, D2.1 (K), D3.1 (K), R24.2
/trim+: R27.1, RV6.3
/trim-: R28.2, RV6.1
/trim_scale: R2.1, RV7.2, RV7.3, U1.2
/trim_tune: R26.1, RV6.2
AP1: J10.5, R13.2
AP2: J11.5, RV5.3
GND: C2.2, C6.2, C7.1, C8.1, C9.1, C10.2, C11.2, C12.1, C13.2, C14.1, C15.2, C16.1, IC1.6 (B3), J1.3, J1.4, J1.5, J1.6, J1.7, J1.8, J8.2, R5.2, R14.2, R17.2, R19.1, R21.1, R25.1, R31.1, U1.3, U1.5, U2.5, U7.3 (B), U7.5 (C), U7.7 (VSS), U7.9 (D), U7.11 (E), U7.13 (F)
GND1: J2.S, J2.TN, J3.S, J3.TN, J4.S, J4.TN, J5.S, J6.S, J7.S, J9.2, RV2.3
In_Sum1: J10.4, RV7.1
In_Sum2: J11.4, R6.2, R7.2, R8.2, RV3.3
PWM_Com1: J10.6, R13.1, R17.1, U2.9
PWM_Com2: J11.6, R12.1
Pulse Out1: J10.2, R20.2
Pulse Out2: J7.T, J11.2
Saw Out1: J10.1, R16.2
Saw Out2: J6.T, J11.1
Triangle Out1: J10.3, R33.2
Triangle Out2: J5.T, J11.3

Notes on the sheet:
VCO
Based on Moritz Klein's design

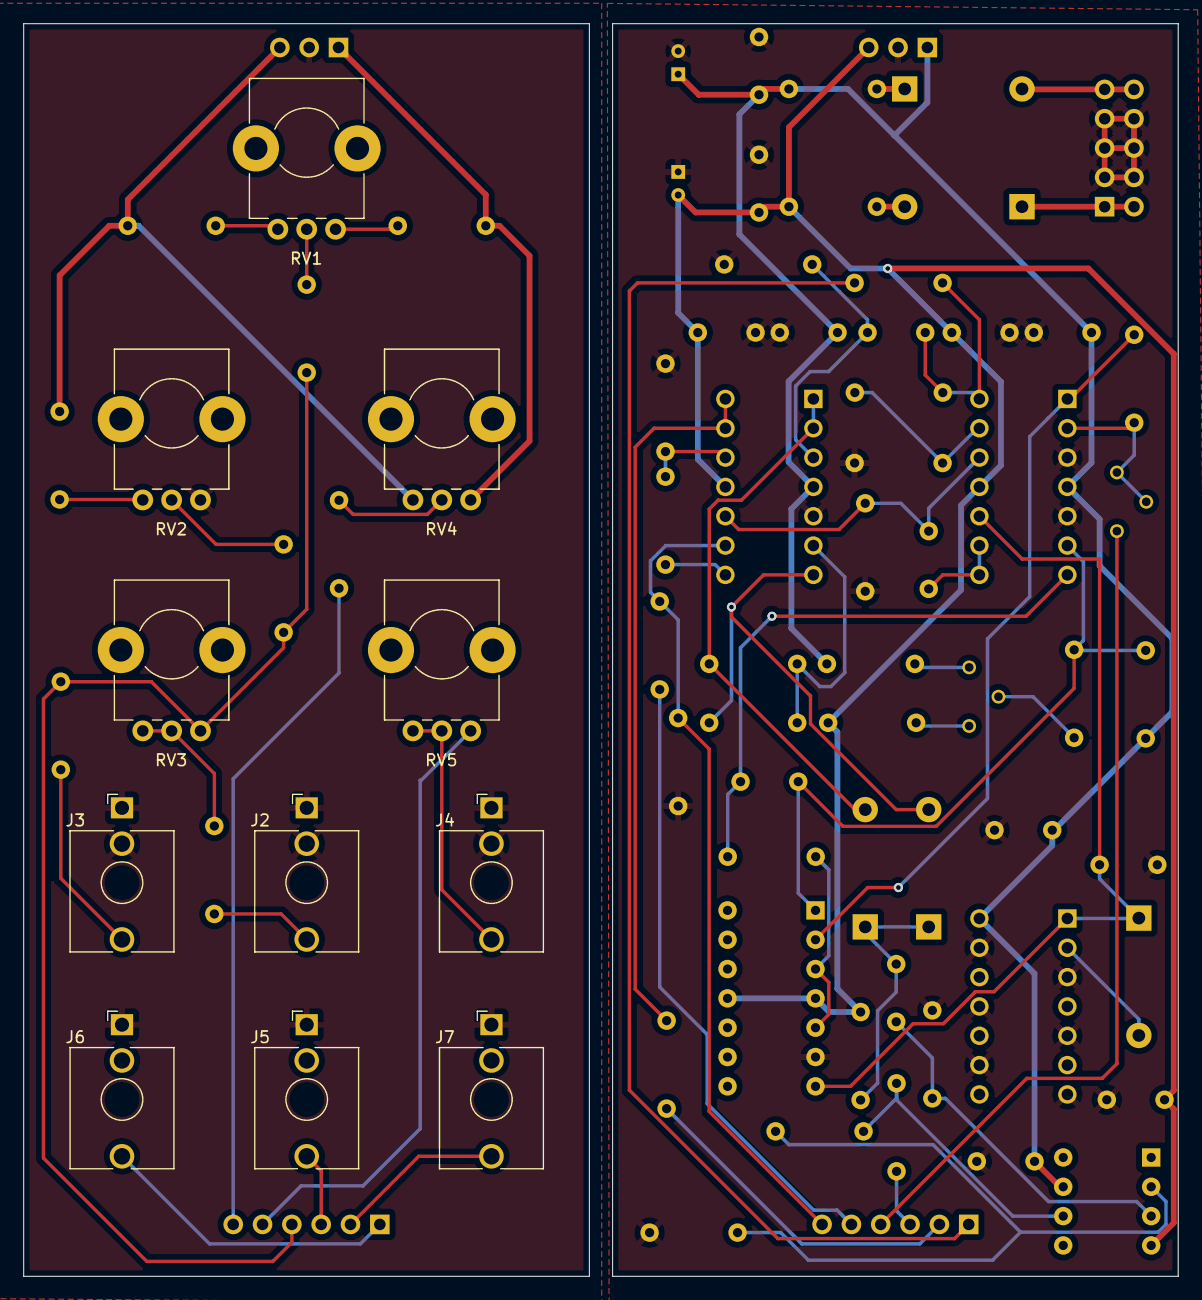
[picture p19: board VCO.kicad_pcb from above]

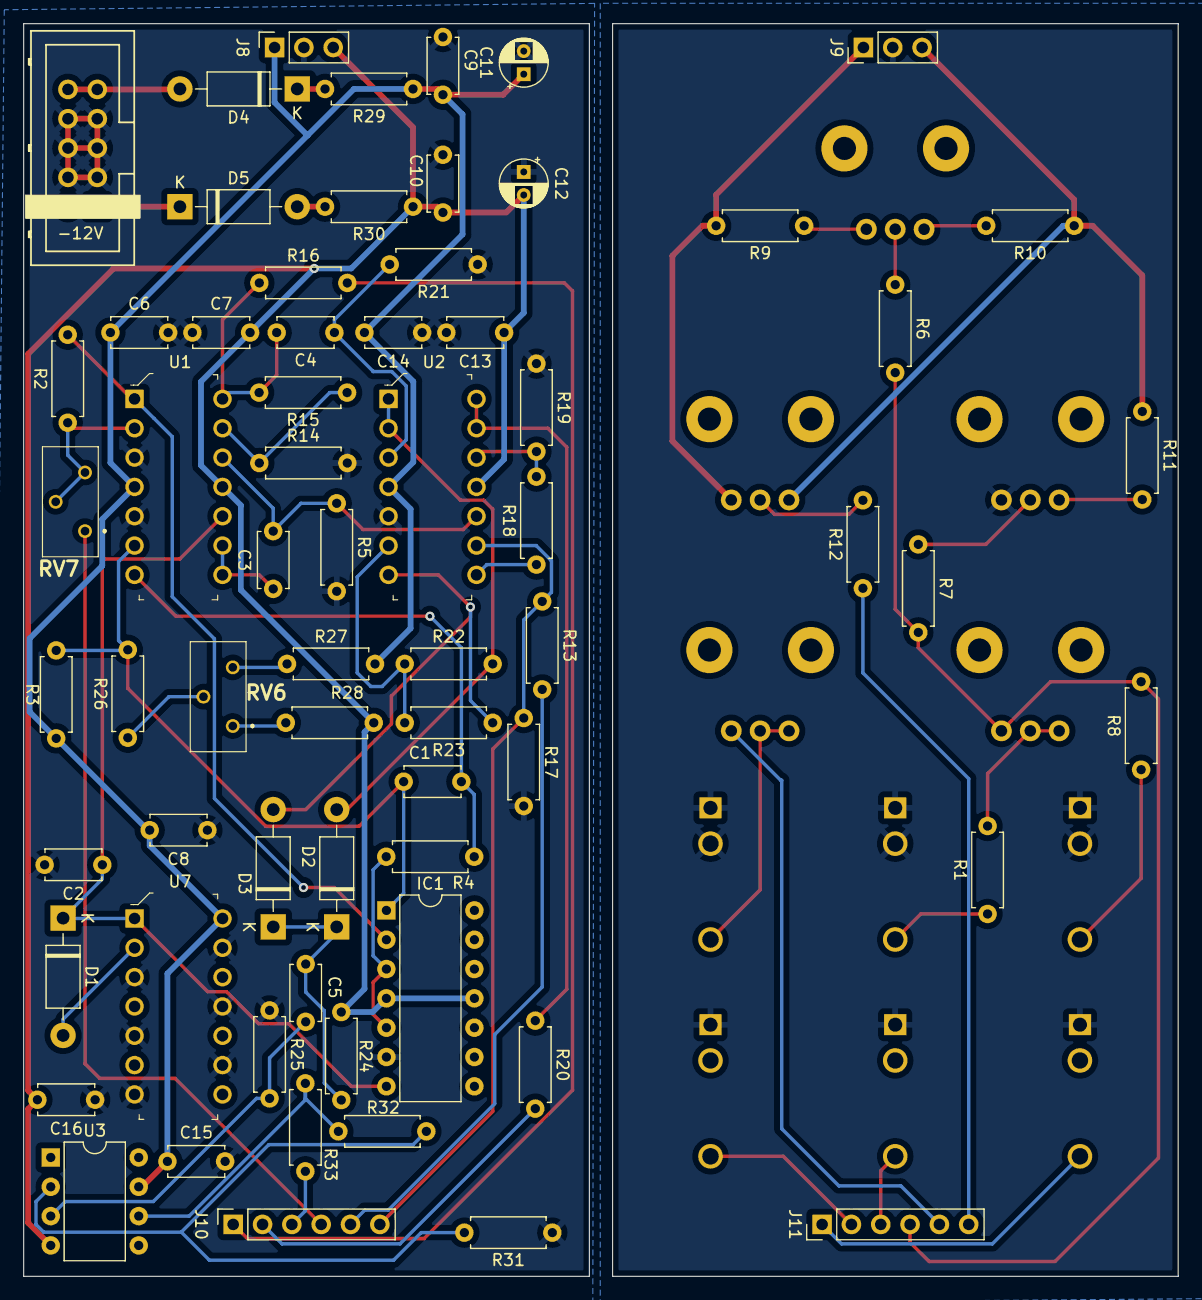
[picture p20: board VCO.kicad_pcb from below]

Board: 2 copper layers, 100.0 x 108.5 mm, 77 parts (66 on the bottom side), 57 nets.

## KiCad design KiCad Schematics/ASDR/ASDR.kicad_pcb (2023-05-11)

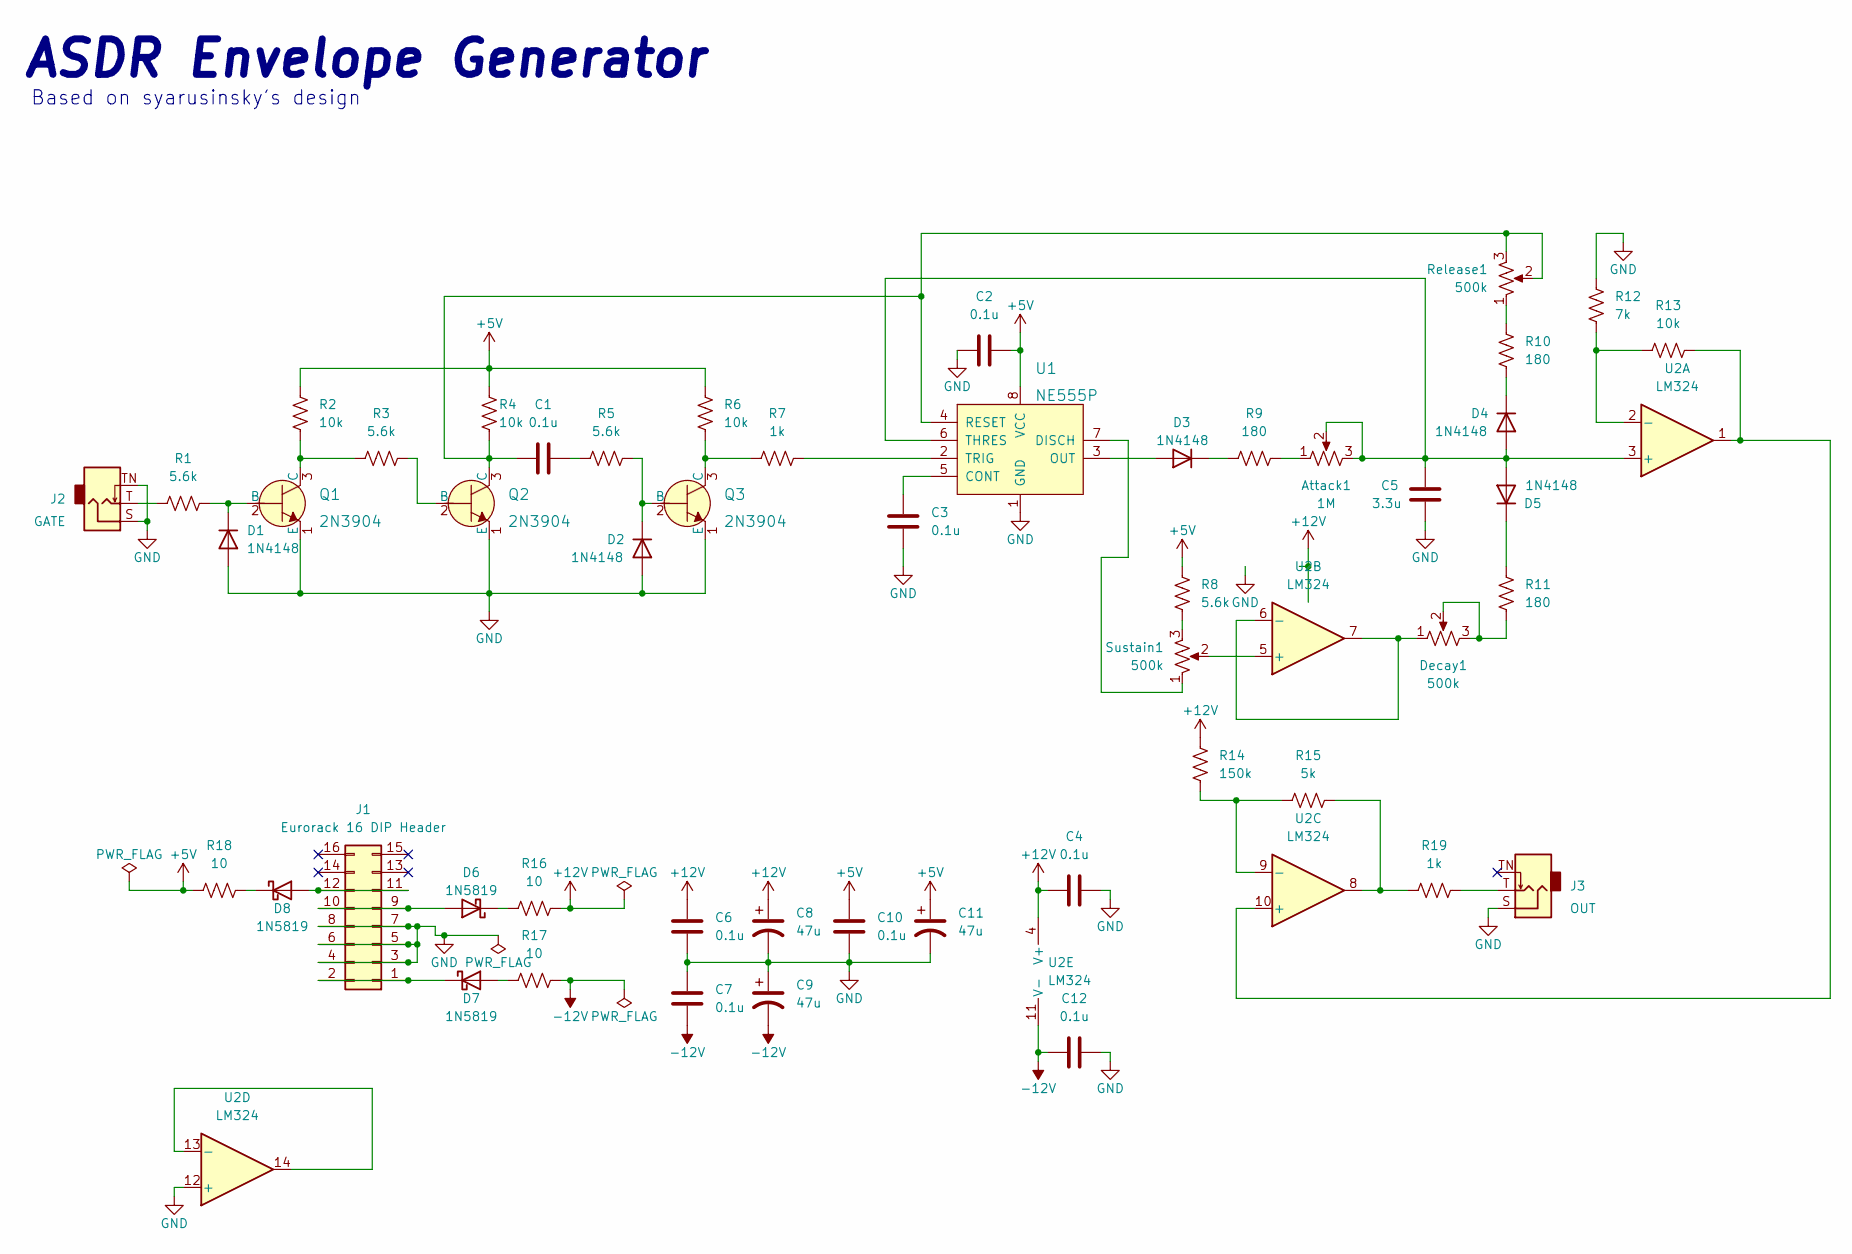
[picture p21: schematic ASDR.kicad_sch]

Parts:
Attack1: 1M; Alpha_9mm_Potentiometer
C1, C2, C3, C4, C6, C7, C10, C12: 0.1u; C_Disc_D4.7mm_W2.5mm_P5.00mm
C5: 3.3u; C_Disc_D4.7mm_W2.5mm_P5.00mm
C8, C9, C11: 47u; CP_Radial_D4.0mm_P2.00mm
D1, D2, D3, D4, D5: 1N4148; D_DO-41_SOD81_P3.81mm_Vertical_KathodeUp
D6, D7, D8: 1N5819; D_DO-41_SOD81_P3.81mm_Vertical_KathodeUp
Decay1: 500k; Alpha_9mm_Potentiometer
J1: Eurorack 16 DIP Header; Eurorack_16_pin_header
J2: GATE; Jack_3.5mm_QingPu_WQP-PJ398SM_Vertical_CircularHoles
J3: OUT; Jack_3.5mm_QingPu_WQP-PJ398SM_Vertical_CircularHoles
Q1, Q2, Q3: 2N3904; TO-92L_Inline_Wide; MPN 2N3904; Digi-Key_PN 2N3904CS-ND
R1, R3, R5, R8: 5.6k; R_Axial_DIN0207_L6.3mm_D2.5mm_P2.54mm_Vertical
R2, R4, R6, R13: 10k; R_Axial_DIN0207_L6.3mm_D2.5mm_P2.54mm_Vertical
R7, R19: 1k; R_Axial_DIN0207_L6.3mm_D2.5mm_P2.54mm_Vertical
R9, R10, R11: 180; R_Axial_DIN0207_L6.3mm_D2.5mm_P2.54mm_Vertical
R12: 7k; R_Axial_DIN0207_L6.3mm_D2.5mm_P2.54mm_Vertical
R14: 150k; R_Axial_DIN0207_L6.3mm_D2.5mm_P2.54mm_Vertical
R15: 5k; R_Axial_DIN0207_L6.3mm_D2.5mm_P2.54mm_Vertical
R16, R17, R18: 10; R_Axial_DIN0207_L6.3mm_D2.5mm_P2.54mm_Vertical
Release1: 500k; Alpha_9mm_Potentiometer
Sustain1: 500k; Alpha_9mm_Potentiometer
U1: NE555P; DIP-8_W7.62mm; MPN NE555P; Digi-Key_PN 296-1411-5-ND
U2: LM324; DIP-14_W7.62mm

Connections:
+5V: C2.2, C10.2, C11.1, R2.2, R4.2, R6.2, R8.2, R18.2, U1.8 (VCC)
+12V: C4.1, C6.2, C8.1, R14.1, R16.1, U2.4 (V+)
-12V: C7.1, C9.2, C12.1, R17.1, U2.11 (V-)
GND: C2.1, C3.1, C4.2, C5.1, C6.1, C7.2, C8.2, C9.1, C10.1, C11.2, C12.2, D1.2 (A), D2.2 (A), J1.3, J1.4, J1.5, J1.6, J1.7, J1.8, J2.S, J2.TN, J3.S, Q1.1 (E), Q2.1 (E), Q3.1 (E), R12.1, U1.1 (GND), U2.12 (+); also elsewhere on the board
unnamed: Attack1.1, R9.1
unnamed: Attack1.2, Attack1.3, C5.2, D4.2 (A), D5.2 (A), U1.6 (THRES), U2.3 (+)
unnamed 6: C1.1, Q2.3 (C), R4.1, Release1.2, Release1.3, U1.4 (RESET); also elsewhere on the board
unnamed: C1.2, R5.1
unnamed: C3.2, U1.5 (CONT)
unnamed: D1.1 (K), Q1.2 (B), R1.2
unnamed: D2.1 (K), Q3.2 (B), R5.2
unnamed: D3.1 (K), R9.2
unnamed: D3.2 (A), U1.3 (OUT)
unnamed: D4.1 (K), R10.2
unnamed: D5.1 (K), R11.1
unnamed: D6.1 (K), R16.2
unnamed: D6.2 (A), J1.9, J1.10
unnamed: D7.1 (K), J1.1, J1.2
unnamed: D7.2 (A), R17.2
unnamed: D8.1 (K), R18.1
unnamed: D8.2 (A), J1.11, J1.12
unnamed: Decay1.1, U2.6 (-), U2.7
unnamed: Decay1.2, Decay1.3, R11.2
unnamed: J2.T, R1.1
unnamed: J3.T, R19.2
unnamed: Q1.3 (C), R2.1, R3.1
unnamed 26: Q2.2 (B), R3.2; also elsewhere on the board
unnamed: Q3.3 (C), R6.1, R7.2
unnamed: R7.1, U1.2 (TRIG)
unnamed: R8.1, Sustain1.3
unnamed: R10.1, Release1.1
unnamed: R12.2, R13.1, U2.2 (-)
unnamed: R13.2, U2.1, U2.10 (+)
unnamed: R14.2, R15.1, U2.9 (-)
unnamed: R15.2, R19.1, U2.8
unnamed: Sustain1.1, U1.7 (DISCH)
unnamed: Sustain1.2, U2.5 (+)
unnamed: U2.13 (-), U2.14

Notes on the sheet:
Based on syarusinsky's design
ASDR Envelope Generator

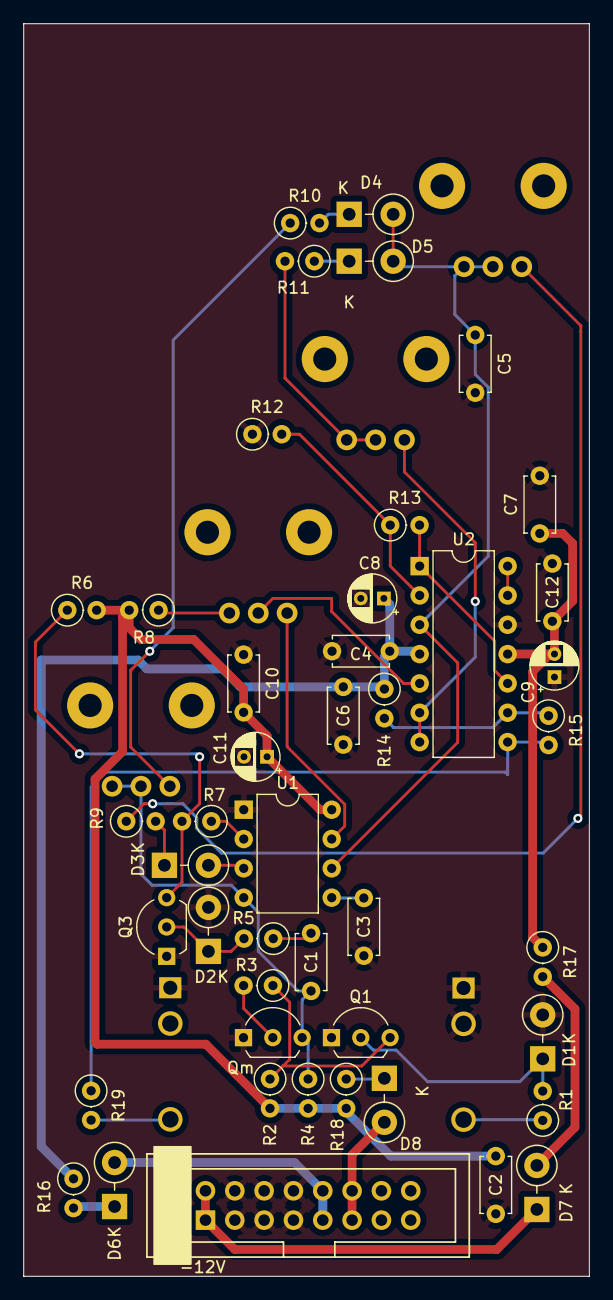
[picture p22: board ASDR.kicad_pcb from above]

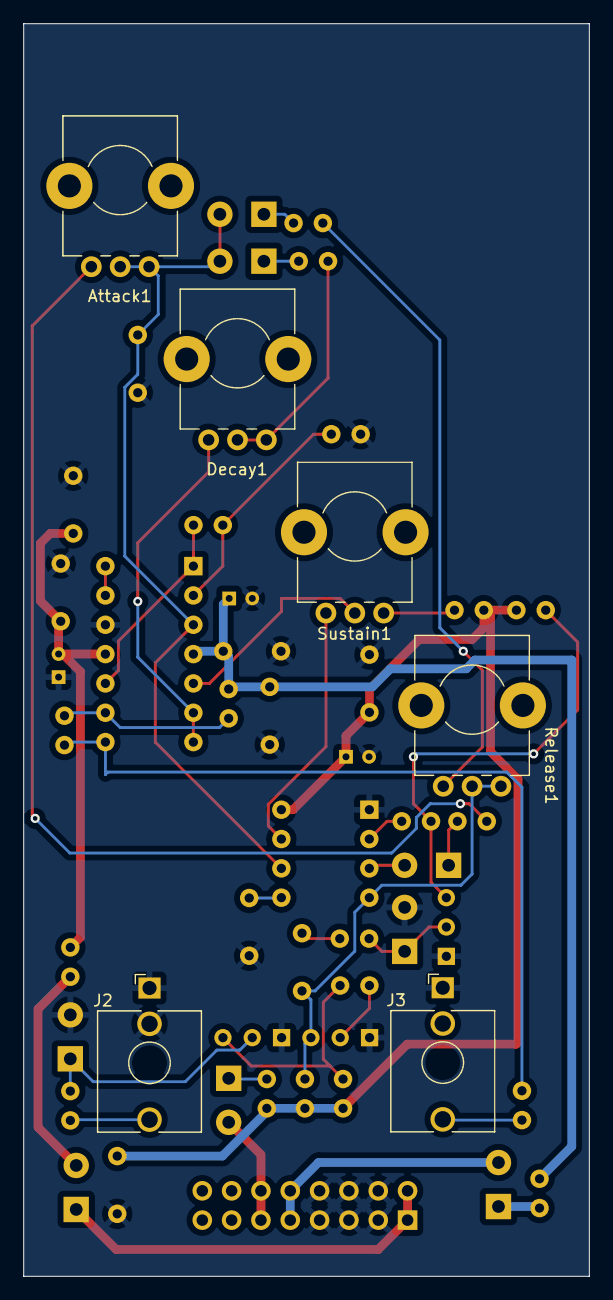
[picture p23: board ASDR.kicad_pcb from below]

Board: 2 copper layers, 49.0 x 108.5 mm, 51 parts (6 on the bottom side), 38 nets.

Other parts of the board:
Qm: 2N3904; TO-92L_Inline_Wide

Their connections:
GND: Qm.1 (E); also elsewhere on the board
unnamed 6: Qm.3 (C); also elsewhere on the board
unnamed 26: Qm.2 (B); also elsewhere on the board

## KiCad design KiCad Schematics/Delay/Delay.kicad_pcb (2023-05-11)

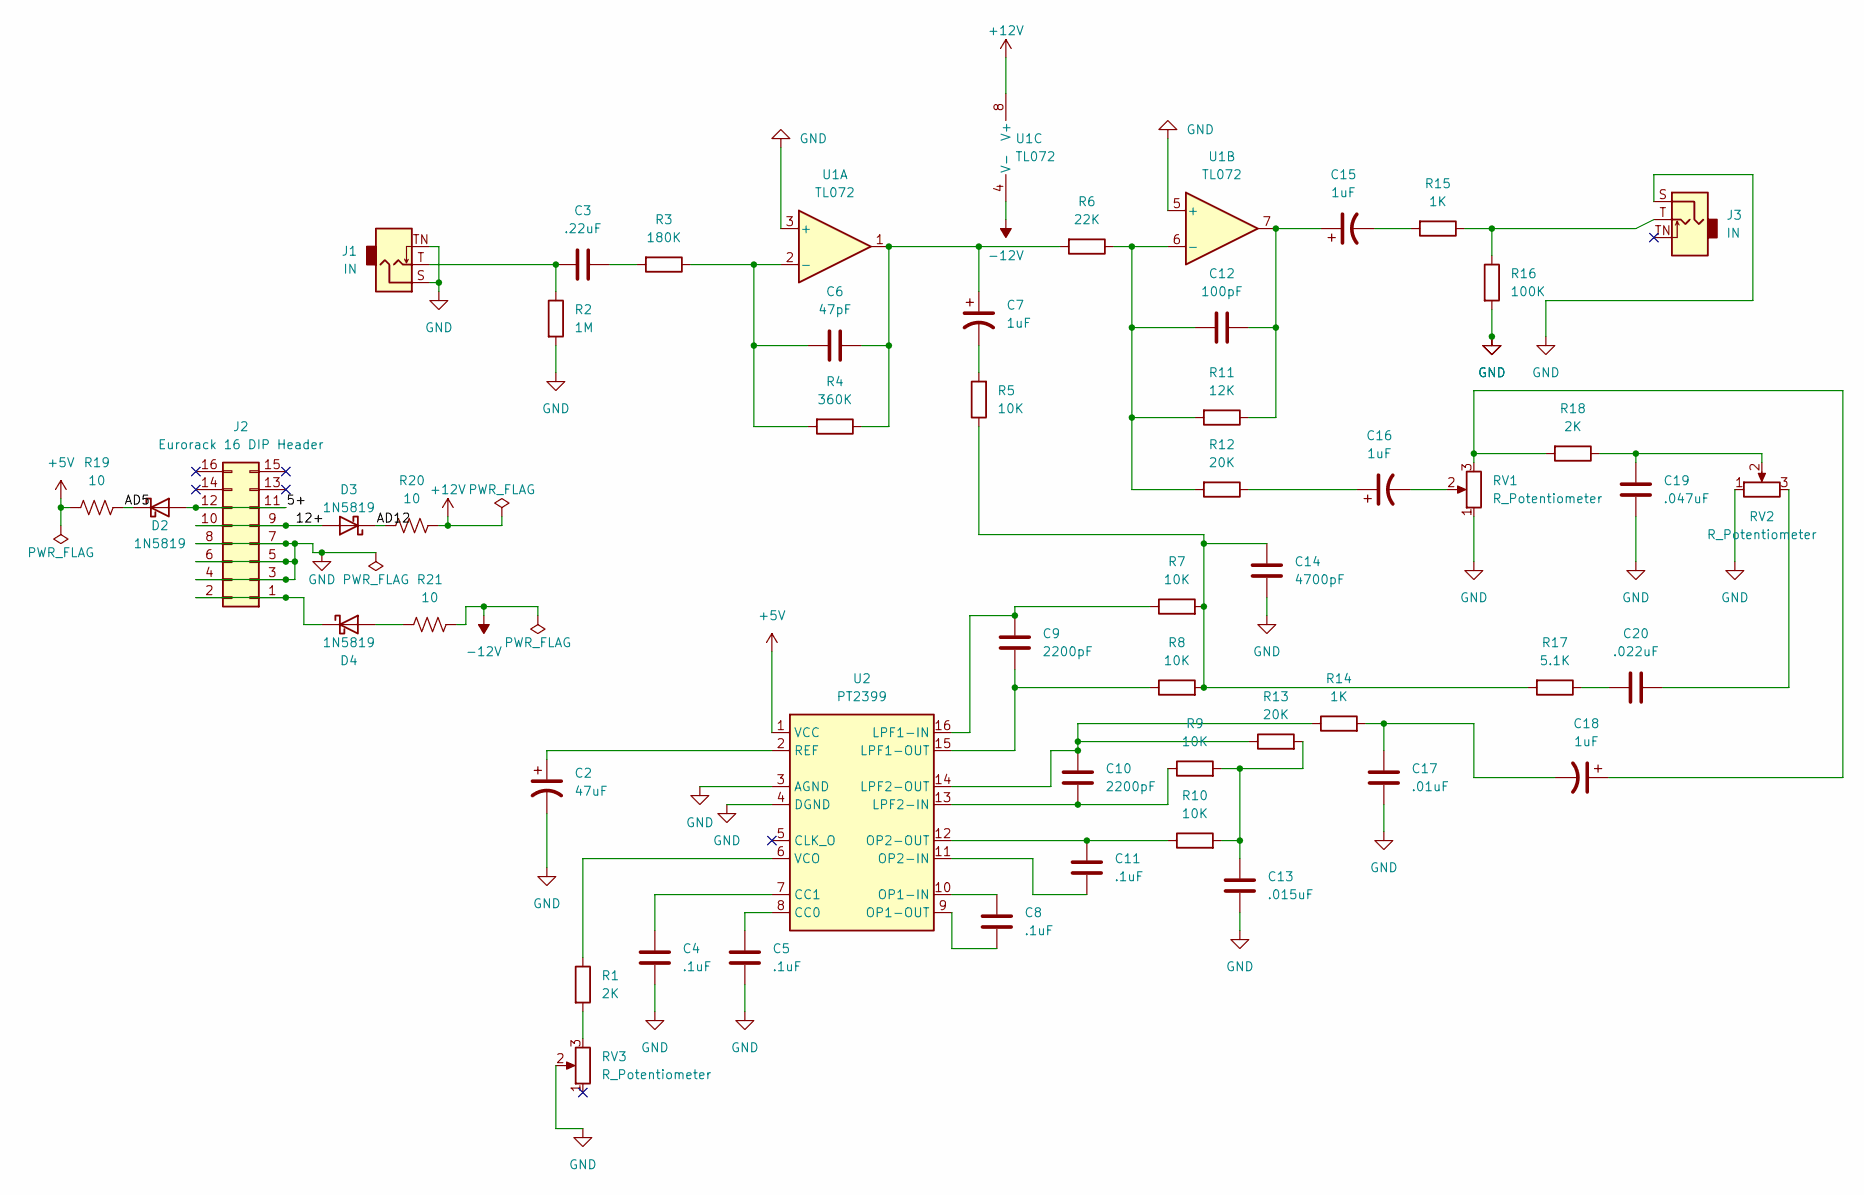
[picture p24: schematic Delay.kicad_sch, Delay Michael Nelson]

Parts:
C2: 47uF; CP_Radial_D5.0mm_P2.00mm
C3: .22uF; C_Disc_D3.8mm_W2.6mm_P2.50mm
C4, C5, C8, C11: .1uF; C_Disc_D3.8mm_W2.6mm_P2.50mm
C6: 47pF; C_Disc_D3.8mm_W2.6mm_P2.50mm
C7, C15, C16, C18: 1uF; CP_Radial_D5.0mm_P2.00mm
C9, C10: 2200pF; C_Disc_D3.8mm_W2.6mm_P2.50mm
C12: 100pF; C_Disc_D3.8mm_W2.6mm_P2.50mm
C13: .015uF; C_Disc_D3.8mm_W2.6mm_P2.50mm
C14: 4700pF; C_Disc_D3.8mm_W2.6mm_P2.50mm
C17: .01uF; C_Disc_D3.8mm_W2.6mm_P2.50mm
C19: .047uF; C_Disc_D3.8mm_W2.6mm_P2.50mm
C20: .022uF; C_Disc_D3.8mm_W2.6mm_P2.50mm
D2, D3, D4: 1N5819; D_DO-41_SOD81_P10.16mm_Horizontal
J1, J3: IN; Jack_3.5mm_QingPu_WQP-PJ398SM_Vertical_CircularHoles
J2: Eurorack 16 DIP Header; Eurorack_16_pin_header
R1, R18: 2K; R_Axial_DIN0207_L6.3mm_D2.5mm_P7.62mm_Horizontal
R2: 1M; R_Axial_DIN0207_L6.3mm_D2.5mm_P7.62mm_Horizontal
R3: 180K; R_Axial_DIN0207_L6.3mm_D2.5mm_P7.62mm_Horizontal
R4: 360K; R_Axial_DIN0207_L6.3mm_D2.5mm_P7.62mm_Horizontal
R5, R7, R8, R9, R10: 10K; R_Axial_DIN0207_L6.3mm_D2.5mm_P7.62mm_Horizontal
R6: 22K; R_Axial_DIN0207_L6.3mm_D2.5mm_P7.62mm_Horizontal
R11: 12K; R_Axial_DIN0207_L6.3mm_D2.5mm_P7.62mm_Horizontal
R12, R13: 20K; R_Axial_DIN0207_L6.3mm_D2.5mm_P7.62mm_Horizontal
R14, R15: 1K; R_Axial_DIN0207_L6.3mm_D2.5mm_P7.62mm_Horizontal
R16: 100K; R_Axial_DIN0207_L6.3mm_D2.5mm_P7.62mm_Horizontal
R17: 5.1K; R_Axial_DIN0207_L6.3mm_D2.5mm_P7.62mm_Horizontal
R19, R20, R21: 10; R_Axial_DIN0207_L6.3mm_D2.5mm_P7.62mm_Horizontal
RV1, RV2, RV3: R_Potentiometer; Alpha_9mm_Potentiometer
U1: TL072; DIP-8_W7.62mm
U2: PT2399; DIP-16_W7.62mm

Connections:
+5V: R19.2, U2.1 (VCC)
+12V: R20.1, U1.8 (V+)
-12V: R21.1, U1.4 (V-)
/5+: D2.2 (A), J2.11, J2.12
/12+: D3.2 (A), J2.9, J2.10
/AD5: D2.1 (K), R19.1
/AD12: D3.1 (K), R20.2
GND: C2.2, C4.2, C5.2, C13.2, C14.2, C17.2, C19.1, J1.S, J1.TN, J2.3, J2.4, J2.5, J2.6, J2.7, J2.8, J3.S, R2.2, R16.2, RV1.1, RV2.1, RV3.2, U1.3 (+), U1.5 (+), U2.3 (AGND), U2.4 (DGND)
unnamed: C2.1, U2.2 (REF)
unnamed: C3.1, J1.T, R2.1
unnamed: C3.2, R3.2
unnamed: C4.1, U2.7 (CC1)
unnamed: C5.1, U2.8 (CC0)
unnamed: C6.1, R3.1, R4.2, U1.2 (-)
unnamed: C6.2, C7.1, R4.1, R6.2, U1.1
unnamed: C7.2, R5.2
unnamed: C8.1, U2.10 (OP1-IN)
unnamed: C8.2, U2.9 (OP1-OUT)
unnamed: C9.1, R7.1, U2.16 (LPF1-IN)
unnamed: C9.2, R8.1, U2.15 (LPF1-OUT)
unnamed: C10.1, R13.1, R14.1, U2.14 (LPF2-OUT)
unnamed: C10.2, R9.1, U2.13 (LPF2-IN)
unnamed: C11.1, R10.1, U2.12 (OP2-OUT)
unnamed: C11.2, U2.11 (OP2-IN)
unnamed: C12.1, R6.1, R11.2, R12.2, U1.6 (-)
unnamed: C12.2, C15.1, R11.1, U1.7
unnamed: C13.1, R9.2, R10.2, R13.2
unnamed: C14.1, R5.1, R7.2, R8.2, R17.2
unnamed: C15.2, R15.2
unnamed: C16.1, R12.1
unnamed: C16.2, RV1.2
unnamed: C17.1, C18.2, R14.2
unnamed: C18.1, R18.2, RV1.3
unnamed: C19.2, R18.1, RV2.2
unnamed: C20.1, RV2.3
unnamed: C20.2, R17.1
unnamed: D4.1 (K), J2.1, J2.2
unnamed: D4.2 (A), R21.2
unnamed: J3.T, R15.1, R16.1
unnamed: R1.1, U2.6 (VCO)
unnamed: R1.2, RV3.3

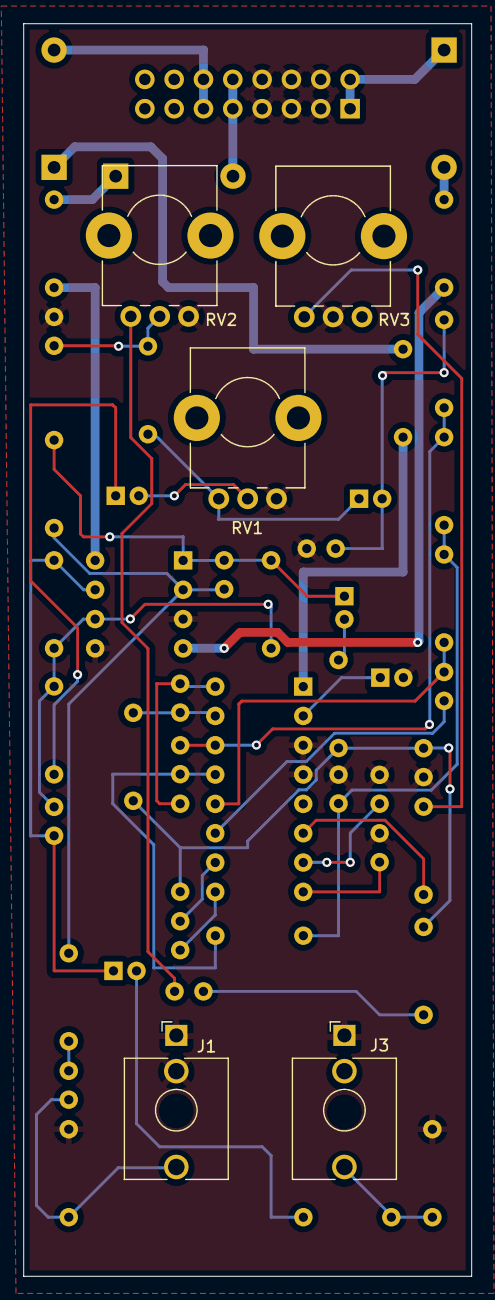
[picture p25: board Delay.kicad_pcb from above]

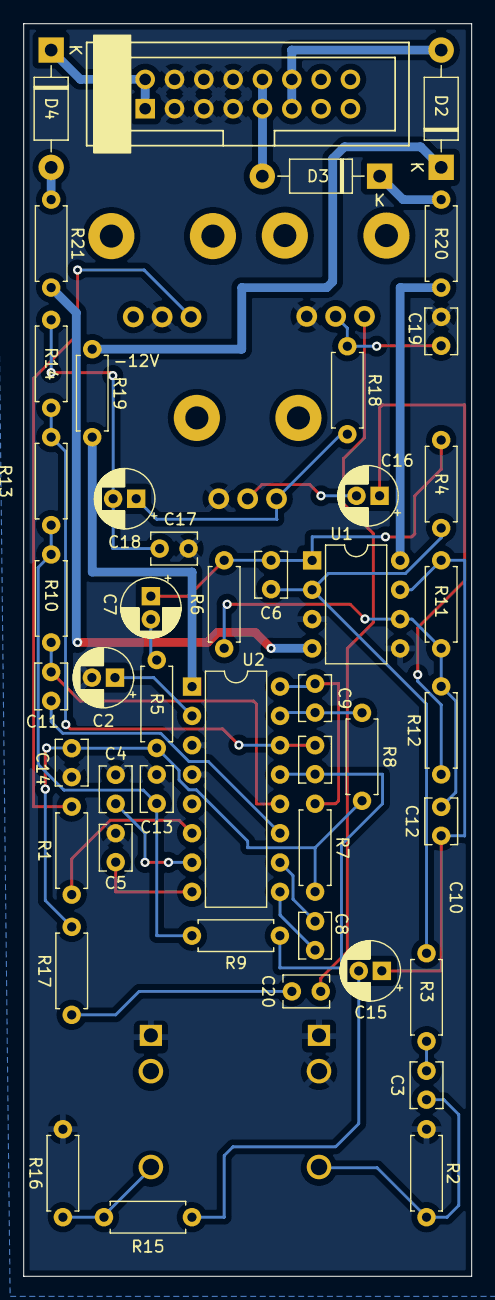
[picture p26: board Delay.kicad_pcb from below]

Board: 2 copper layers, 38.8 x 108.5 mm, 51 parts (46 on the bottom side), 41 nets.

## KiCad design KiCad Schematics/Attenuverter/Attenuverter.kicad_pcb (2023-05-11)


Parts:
C1, C2, C5, C6: 0.1u; C_Disc_D4.7mm_W2.5mm_P5.00mm
C3, C4: 47u; CP_Radial_D4.0mm_P2.00mm
D1, D2: 1N5819; D_DO-41_SOD81_P3.81mm_Vertical_KathodeUp
J1: IN1; Jack_3.5mm_QingPu_WQP-PJ398SM_Vertical_CircularHoles
J2: OUT1; Jack_3.5mm_QingPu_WQP-PJ398SM_Vertical_CircularHoles
J3: IN2; Jack_3.5mm_QingPu_WQP-PJ398SM_Vertical_CircularHoles
J4: OUT2; Jack_3.5mm_QingPu_WQP-PJ398SM_Vertical_CircularHoles
J5: IN3; Jack_3.5mm_QingPu_WQP-PJ398SM_Vertical_CircularHoles
J6: OUT3; Jack_3.5mm_QingPu_WQP-PJ398SM_Vertical_CircularHoles
J7: IN4; Jack_3.5mm_QingPu_WQP-PJ398SM_Vertical_CircularHoles
J8: OUT4; Jack_3.5mm_QingPu_WQP-PJ398SM_Vertical_CircularHoles
J9: Eurorack 10 DIP Header; Eurorack_10_pin_header
R1, R2: 10; R_Axial_DIN0207_L6.3mm_D2.5mm_P2.54mm_Vertical
R3, R4, R5, R6, R9, R10, R11, R12: 20k; R_Axial_DIN0207_L6.3mm_D2.5mm_P2.54mm_Vertical
R7, R8, R13, R14: 1k; R_Axial_DIN0207_L6.3mm_D2.5mm_P2.54mm_Vertical
RV1, RV2, RV3, RV4: 10k; Alpha_9mm_Potentiometer_Aligned
U1: TL074; DIP-14_W7.62mm

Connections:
+12V: C1.2, C3.1, C5.1, R1.1, U1.4 (V+)
-12V: C2.1, C4.2, C6.1, R2.1, U1.11 (V-)
/12+: D1.2 (A), J9.9, J9.10
/12-: D2.1 (K), J9.1, J9.2
/D+: D1.1 (K), R1.2
/D-: D2.2 (A), R2.2
/fb1: R5.2, R7.1, U1.1
/fb2: R11.2, R13.1, U1.7
/fb3: R6.2, R8.1, U1.8
/fb4: R12.2, R14.1, U1.14
/in1: J1.T, R3.1, RV1.3
/in2: J3.T, R9.1, RV2.3
/in3: J5.T, R4.1, RV3.3
/in4: J7.T, R10.1, RV4.3
/inv1: R3.2, R5.1, U1.2 (-)
/inv2: R9.2, R11.1, U1.6 (-)
/inv3: R4.2, R6.1, U1.9 (-)
/inv4: R10.2, R12.1, U1.13 (-)
/non_inv1: RV1.2, U1.3 (+)
/non_inv2: RV2.2, U1.5 (+)
/non_inv3: RV3.2, U1.10 (+)
/non_inv4: RV4.2, U1.12 (+)
/out1: J2.T, R7.2
/out2: J4.T, R13.2
/out3: J6.T, R8.2
/out4: J8.T, R14.2
GND: C1.1, C2.2, C3.2, C4.1, C5.2, C6.2, J1.S, J1.TN, J2.S, J3.S, J3.TN, J4.S, J5.S, J5.TN, J6.S, J7.S, J7.TN, J8.S, J9.3, J9.4, J9.5, J9.6, J9.7, J9.8, RV1.1, RV2.1, RV3.1, RV4.1



Board: 2 copper layers, 38.8 x 108.5 mm, 36 parts (24 on the bottom side), 27 nets.

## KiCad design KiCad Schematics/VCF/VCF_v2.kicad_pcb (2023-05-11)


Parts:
C1, C2, C10, C11, C12, C13, C14, C15, C16, C17, C18, C19: 0.1u; C_Disc_D4.7mm_W2.5mm_P5.00mm
C3, C4: 47u; CP_Radial_D4.0mm_P2.00mm
C5: 20p; C_Disc_D4.7mm_W2.5mm_P5.00mm
C6, C7, C8, C9: 100p; C_Disc_D4.7mm_W2.5mm_P5.00mm
D1, D2: 1N5819; D_DO-41_SOD81_P3.81mm_Vertical_KathodeUp
J1: Eurorack 10 DIP Header; Eurorack_10_pin_header
J2: CV2; Jack_3.5mm_QingPu_WQP-PJ398SM_Vertical_CircularHoles
J3: CV1; Jack_3.5mm_QingPu_WQP-PJ398SM_Vertical_CircularHoles
J4: IN; Jack_3.5mm_QingPu_WQP-PJ398SM_Vertical_CircularHoles
J5: OUT; Jack_3.5mm_QingPu_WQP-PJ398SM_Vertical_CircularHoles
J6: Comp1; PinSocket_1x03_P2.54mm_Vertical
J7: Inter1; PinSocket_1x03_P2.54mm_Vertical
J8: Comp2; PinSocket_1x05_P2.54mm_Vertical
J9: Inter2; PinSocket_1x05_P2.54mm_Vertical
Q1, Q2, Q3, Q4, Q5: 2N3906; TO-92L_Inline_Wide; MPN 2N3906; Digi-Key_PN 2N3906CS-ND
R1, R2, R3, R14: 100k; R_Axial_DIN0204_L3.6mm_D1.6mm_P5.08mm_Horizontal
R4, R5, R12, R13, R16, R17, R20, R21, R24, R25, R28, R31: 100k; R_Axial_DIN0204_L3.6mm_D1.6mm_P2.54mm_Vertical
R6: 1.87k; R_Axial_DIN0204_L3.6mm_D1.6mm_P2.54mm_Vertical
R7: 470; R_Axial_DIN0204_L3.6mm_D1.6mm_P2.54mm_Vertical
R8: 1Meg; R_Axial_DIN0204_L3.6mm_D1.6mm_P2.54mm_Vertical
R9: 20k; R_Axial_DIN0204_L3.6mm_D1.6mm_P2.54mm_Vertical
R10, R19, R23, R27: 150k; R_Axial_DIN0204_L3.6mm_D1.6mm_P2.54mm_Vertical
R11: 1.8k; R_Axial_DIN0204_L3.6mm_D1.6mm_P2.54mm_Vertical
R15, R34, R35: 1k; R_Axial_DIN0204_L3.6mm_D1.6mm_P5.08mm_Horizontal
R18, R22, R26: 1k; R_Axial_DIN0204_L3.6mm_D1.6mm_P2.54mm_Vertical
R29: 3.9k; R_Axial_DIN0204_L3.6mm_D1.6mm_P2.54mm_Vertical
R30: 10k; R_Axial_DIN0204_L3.6mm_D1.6mm_P2.54mm_Vertical
R32: 220k; R_Axial_DIN0204_L3.6mm_D1.6mm_P5.08mm_Horizontal
R33: 18k; R_Axial_DIN0204_L3.6mm_D1.6mm_P5.08mm_Horizontal
R36: 27k; R_Axial_DIN0204_L3.6mm_D1.6mm_P5.08mm_Horizontal
RV1: 50k; Alpha_9mm_Potentiometer_Aligned
RV2, RV3, RV5: 100k; Alpha_9mm_Potentiometer_Aligned
RV4: 100; Potentiometer_Bourns_3296Y_Vertical
SW1: SW_SPDT; SPDT toggle on-off-on
U1, U2: LM13700; DIP-16_W7.62mm
U3, U4: TL074; DIP-14_W7.62mm
U5: TL072; DIP-8_W7.62mm

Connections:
+12V: C1.2, C3.1, C10.2, C11.2, C12.2, C13.2, C14.2, D1.1 (K), J6.1, R10.1, R19.1, R23.1, R27.1, U1.7, U1.8, U1.9, U1.10, U1.11 (V+), U2.7, U2.8, U2.9, U2.10, U2.11 (V+), U3.4 (V+), U4.4 (V+), U5.8 (V+)
+12VA: J7.1, R36.2
-12V: C2.1, C4.2, C15.2, C16.2, C17.2, C18.2, C19.2, D2.2 (A), J6.3, R8.1, U1.6 (V-), U2.6 (V-), U3.11 (V-), U4.11 (V-), U5.4 (V-)
-12VA: J7.3, R33.1
/1V/Oct: R6.2, RV4.1, U3.1
/2P_FDB: R11.1, R12.2, U5.2 (-)
/4P_FDB: R13.2, R29.1, U5.6 (-)
/12+: D1.2 (A), J1.9, J1.10
/12-: D2.1 (K), J1.1, J1.2
/12out: R34.2, SW1.3 (C)
/24out: R35.2, SW1.1 (A)
/Amp_C1: Q2.3 (C), U1.16
/Amp_C2: Q3.3 (C), U1.1
/Amp_C3: Q4.3 (C), U2.16
/Amp_C4: Q5.3 (C), U2.1
/Bias_Current: C5.2, Q1.3 (C), R8.2, U3.13 (-)
/Buf_Out1: R16.2, R17.1, U4.13 (-), U4.14
/Buf_Out2: R20.2, R21.1, U4.8, U4.9 (-), U5.3 (+)
/Buf_Out3: R24.2, R25.1, U4.6 (-), U4.7
/Buf_Out4: R28.2, R30.2, U4.1, U4.2 (-), U5.5 (+)
/CF_V: R3.1, RV1.2
/CV1: J3.T, RV2.3
/CV1_ATN: R1.1, RV2.2
/CV2: J2.T, RV3.3
/CV2_ATN: R2.1, RV3.2
/CV_FDB: R4.2, R5.1, U3.8
/CV_SCLE: R5.2, R6.1, U3.2 (-)
/Cout1: C6.2, U1.12, U4.12 (+)
/Cout2: C7.2, U1.5, U4.10 (+)
/Cout3: C8.2, U2.12, U4.5 (+)
/Cout4: C9.2, U2.5, U4.3 (+)
/Exp_Cout: Q1.1 (E), Q2.1 (E), Q3.1 (E), Q4.1 (E), Q5.1 (E), R9.2
/Exp_Out: C5.1, R9.1, U3.14
/IN: J4.T, R14.1
/INV2: R17.2, R18.2, R20.1, U1.4 (-)
/INV3: R21.2, R22.2, R24.1, U2.13 (-)
/INV4: R25.2, R26.2, R28.1, U2.4 (-)
/OUT: J5.T, SW1.2 (B)
/Res_ATN: R32.2, RV5.2
/Res_INV: R30.1, R31.2, U3.6 (-)
/Trim: R7.2, RV4.3
Audio_1st_invert_Comp: J8.3, R16.1, U1.13 (-)
Audio_1st_invert_INT: J9.3, R14.2, R15.2, R32.1
Audio_-12Out_Comp: J8.4, R11.2, U5.1
Audio_-12Out_INT: J9.4, R34.1
Audio_-24Out_Comp: J8.5, R29.2, U5.7
Audio_-24Out_INT: J9.5, R35.1
CV_Sum_Comp: J8.1, R4.1, U3.9 (-)
CV_Sum_INT: J9.1, R1.2, R2.2, R3.2
GND: C1.1, C2.2, C3.2, C4.1, C6.1, C7.1, C8.1, C9.1, C10.1, C11.1, C12.1, C13.1, C14.1, C15.1, C16.1, C17.1, C18.1, C19.1, J1.3, J1.4, J1.5, J1.6, J1.7, J1.8, J6.2, Q2.2 (B), Q3.2 (B), Q4.2 (B), Q5.2 (B), R7.1, R12.1, R13.1, R18.1, R22.1, R26.1, U1.3 (+), U1.14 (+), U2.3 (+), U2.14 (+), U3.3 (+), U3.5 (+), U3.10 (+), U3.12 (+)
GND1: J2.S, J2.TN, J3.S, J3.TN, J4.S, J4.TN, J5.S, J7.2, R15.1, RV2.1, RV3.1, RV5.1
unnamed: Q1.2 (B), RV4.2
unnamed: R33.2, RV1.1
unnamed: R36.1, RV1.3
unnamed: R10.2, U1.15 (DIODE_BIAS)
unnamed: R19.2, U1.2 (DIODE_BIAS)
unnamed: R23.2, U2.15 (DIODE_BIAS)
unnamed: R27.2, U2.2 (DIODE_BIAS)
Res_Comp: J8.2, R31.1, U3.7
Res_INT: J9.2, RV5.3



Board: 2 copper layers, 87.6 x 108.5 mm, 82 parts (69 on the bottom side), 60 nets.

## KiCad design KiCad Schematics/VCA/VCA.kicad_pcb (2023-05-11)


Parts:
BIAS1, BIAS2: 100k; Alpha_9mm_Potentiometer_Aligned
C1, C2, C3, C4: 0.1u; C_Disc_D4.7mm_W2.5mm_P5.00mm
C5, C6: 47u; CP_Radial_D4.0mm_P2.00mm
D1, D2: 1N5819; D_DO-41_SOD81_P10.16mm_Horizontal
J1: IN1; Jack_3.5mm_QingPu_WQP-PJ398SM_Vertical_CircularHoles
J2: CV1; Jack_3.5mm_QingPu_WQP-PJ398SM_Vertical_CircularHoles
J3: OUT1; Jack_3.5mm_QingPu_WQP-PJ398SM_Vertical_CircularHoles
J4: Eurorack 10 DIP Header; Eurorack_10_pin_header
J5: CV2; Jack_3.5mm_QingPu_WQP-PJ398SM_Vertical_CircularHoles
J6: IN2; Jack_3.5mm_QingPu_WQP-PJ398SM_Vertical_CircularHoles
J7: OUT2; Jack_3.5mm_QingPu_WQP-PJ398SM_Vertical_CircularHoles
Q1, Q2, Q3, Q4: BC550; TO-92L_Inline_Wide
R1, R7, R9, R17, R23, R25: 20k; R_Axial_DIN0207_L6.3mm_D2.5mm_P2.54mm_Vertical
R2, R3, R4, R11, R14, R15, R18, R19, R20, R27, R30, R31: 100k; R_Axial_DIN0207_L6.3mm_D2.5mm_P2.54mm_Vertical
R5, R10, R21, R26: 100; R_Axial_DIN0207_L6.3mm_D2.5mm_P2.54mm_Vertical
R6, R22: 82k; R_Axial_DIN0207_L6.3mm_D2.5mm_P2.54mm_Vertical
R8, R24: 10k; R_Axial_DIN0207_L6.3mm_D2.5mm_P2.54mm_Vertical
R12, R13, R28, R29: 4.7k; R_Axial_DIN0207_L6.3mm_D2.5mm_P2.54mm_Vertical
R16, R32: 1k; R_Axial_DIN0207_L6.3mm_D2.5mm_P2.54mm_Vertical
R33, R34: 10; R_Axial_DIN0207_L6.3mm_D2.5mm_P7.62mm_Horizontal
RV1, RV2: 100k; 3296Y1502LF
U1: TL074CN; DIP-14_W3mm; MPN TL074CN

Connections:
+12V: C1.2, C3.2, C5.1, R1.2, R7.1, R9.1, R17.2, R23.1, R25.1, R33.1, RV1.1, RV2.1, U1.4 (VCC)
-12V: C2.1, C4.1, C6.2, R34.1, RV1.3, RV2.3, U1.11 (GND)
/12+: D1.2 (A), J4.9, J4.10
/12-: D2.1 (K), J4.1, J4.2
/B1: Q1.1 (B), R4.2, R5.1
/B2: Q2.1 (B), R10.1, R11.1
/B2_BIAS: R11.2, RV1.2
/B3: Q3.1 (B), R20.2, R21.1
/B4: Q4.1 (B), R26.1, R27.1
/B4_BIAS: R27.2, RV2.2
/BIC1: R6.2, R8.2, U1.7
/BIC2: R22.2, R24.2, U1.14
/C1: Q1.2 (C), R7.2, R12.1
/C2: Q2.2 (C), R9.2, R13.1
/C3: Q3.2 (C), R23.2, R28.1
/C4: Q4.2 (C), R25.2, R29.1
/CV_IN1: J2.T, J5.TN, R2.1
/CV_IN2: J5.T, R18.1
/CV_IN_SUM1: R2.2, R3.2, R6.1, U1.6
/CV_IN_SUM2: R18.2, R19.2, R22.1, U1.13
/D+: D1.1 (K), R33.2
/D-: D2.2 (A), R34.2
/DP1: Q1.3 (E), Q2.3 (E), R8.1
/DP2: Q3.3 (E), Q4.3 (E), R24.1
/IN1: J1.T, J6.TN, R4.1
/IN2: J6.T, R20.1
/OP_INV1: R12.2, R15.1, U1.2
/OP_INV2: R28.2, R31.1, U1.9
/OP_NON1: R13.2, R14.2, U1.3
/OP_NON2: R29.2, R30.2, U1.10
/OP_OUT1: R15.2, R16.1, U1.1
/OP_OUT2: R31.2, R32.1, U1.8
/OUT1: J3.T, R16.2
/OUT2: J7.T, R32.2
/VD1: BIAS1.3, R1.1
/VD2: BIAS2.3, R17.1
/WIP1: BIAS1.2, R3.1
/WIP2: BIAS2.2, R19.1
GND: BIAS1.1, BIAS2.1, C1.1, C2.2, C3.1, C4.2, C5.2, C6.1, J1.S, J1.TN, J2.S, J2.TN, J3.S, J4.3, J4.4, J4.5, J4.6, J4.7, J4.8, J5.S, J6.S, J7.S, R5.2, R10.2, R14.1, R21.2, R26.2, R30.1, U1.5, U1.12

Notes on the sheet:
Based on Moritz Klein's design
Dual VCA

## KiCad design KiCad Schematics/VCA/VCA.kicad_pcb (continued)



Board: 2 copper layers, 38.8 x 108.5 mm, 58 parts (50 on the bottom side), 39 nets.

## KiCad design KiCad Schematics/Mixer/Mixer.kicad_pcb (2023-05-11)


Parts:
C1, C2, C5, C6: 0.1u; C_Disc_D4.7mm_W2.5mm_P5.00mm
C3, C4: 47u; CP_Radial_D4.0mm_P2.00mm
D1, D2: 1N5819; D_DO-41_SOD81_P3.81mm_Vertical_KathodeUp
D3, D4: 1N4148; D_DO-41_SOD81_P2.54mm_Vertical_KathodeUp
J1: Eurorack 10 DIP Header; Eurorack_10_pin_header
J2: IN1; Jack_3.5mm_QingPu_WQP-PJ398SM_Vertical_CircularHoles
J3: IN2; Jack_3.5mm_QingPu_WQP-PJ398SM_Vertical_CircularHoles
J4: IN3; Jack_3.5mm_QingPu_WQP-PJ398SM_Vertical_CircularHoles
J5: INV OUT; Jack_3.5mm_QingPu_WQP-PJ398SM_Vertical_CircularHoles
J6: OUT; Jack_3.5mm_QingPu_WQP-PJ398SM_Vertical_CircularHoles
J7: CLP OUT; Jack_3.5mm_QingPu_WQP-PJ398SM_Vertical_CircularHoles
R1, R2: 10; R_Axial_DIN0207_L6.3mm_D2.5mm_P2.54mm_Vertical
R3, R4, R5, R6, R7, R8, R11, R13: 100k; R_Axial_DIN0207_L6.3mm_D2.5mm_P2.54mm_Vertical
R9, R10, R14: 1k; R_Axial_DIN0207_L6.3mm_D2.5mm_P2.54mm_Vertical
R12: 27k; R_Axial_DIN0207_L6.3mm_D2.5mm_P2.54mm_Vertical
RV1, RV2, RV3: 100k; Alpha_9mm_Potentiometer_Aligned
RV4: 20k; 3296Y1104LF
U1: TL074; DIP-14_W7.62mm

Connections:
+12V: C1.2, C3.1, C5.1, R1.1, U1.4 (V+)
-12V: C2.1, C4.2, C6.1, R2.1, U1.11 (V-)
/12+: D1.2 (A), J1.9, J1.10
/12-: D2.1 (K), J1.1, J1.2
/CLP_FB: R12.2, R13.1, U1.9 (-)
/CLP_IN: D3.2 (A), D4.1 (K), R11.2, U1.10 (+)
/CLP_OUT: R13.2, R14.1, U1.8
/D+: D1.1 (K), R1.2
/D-: D2.2 (A), R2.2
/DD: D3.1 (K), D4.2 (A), RV4.3
/IN1: J2.T, RV1.3
/IN2: J3.T, RV2.3
/IN3: J4.T, RV3.3
/INVBF: R7.2, R8.1, U1.6 (-)
/INV_SUM_OUT: R6.2, R7.1, R9.1, U1.1
/IW1: R3.1, RV1.2
/IW2: R4.1, RV2.2
/IW3: R5.1, RV3.2
/STABLE: U1.13 (-), U1.14
/SUM: R3.2, R4.2, R5.2, R6.1, U1.2 (-)
/SUM_OUT: R8.2, R10.1, R11.1, U1.7
GND: C1.1, C2.2, C3.2, C4.1, C5.2, C6.2, J1.3, J1.4, J1.5, J1.6, J1.7, J1.8, J2.S, J2.TN, J3.S, J3.TN, J4.S, J4.TN, J5.S, J6.S, J7.S, R12.1, RV1.1, RV2.1, RV3.1, RV4.1, RV4.2, U1.3 (+), U1.5 (+), U1.12 (+)
unnamed: J5.T, R9.2
unnamed: J6.T, R10.2
unnamed: J7.T, R14.2



Board: 2 copper layers, 38.8 x 108.5 mm, 36 parts (27 on the bottom side), 25 nets.

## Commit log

2023-05-11 Added schematic files
    [ASDR.csv, ASDR.kicad_pcb, ASDR.kicad_sch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]
2023-05-11 Added symbol, footprint, and template files
    [eurorack-faceplate-10hp.kicad_pcb, eurorack-faceplate-10hp.kicad_sch, eurorack-faceplate-12hp.kicad_pcb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]
2023-05-11 Added step files
    [ASDR_PANEL.step, Attenuverter_PANEL.step, DelayBoard2PanelBoard.step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]

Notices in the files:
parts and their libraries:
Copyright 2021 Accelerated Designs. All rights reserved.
